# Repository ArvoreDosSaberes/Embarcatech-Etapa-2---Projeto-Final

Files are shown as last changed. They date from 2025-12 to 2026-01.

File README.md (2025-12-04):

# Rack Inteligente Workspace






[]()
[]()








MVP para o projeto Embarcatech, o Rack Inteligente é um sistema IoT para Racks de Redes de Computadores. Ele monitora o Rack quanto a questões ambientais (temperatura, umidade) e segurança (porta, inclinação), alertando uma central através do protocolo MQTT na borda, que recebe subscrição de um servidor na nuvem que centraliza a gestão dos racks.

---

## 📋 Índice

1. [Pré-requisitos](#-pré-requisitos)
2. [Clonagem do Repositório](#-clonagem-do-repositório)
3. [Configuração do Ambiente Python](#-configuração-do-ambiente-python)
4. [Instalação do Granite TSF](#-instalação-do-granite-tsf)
5. [Configuração de Variáveis de Ambiente](#%EF%B8%8F-configuração-de-variáveis-de-ambiente)
6. [Compilação do Firmware](#-compilação-do-firmware)
7. [Gravação no RP2040](#-gravação-no-rp2040)
8. [Configuração no VSCode/Windsurf](#-configuração-no-vscodewindsurf)
9. [Softwares Relevantes](#-softwares-relevantes)

---

## 🔧 Pré-requisitos

Antes de iniciar, certifique-se de ter instalado:

### Sistema Operacional
- **Linux** (Ubuntu 20.04+ recomendado) ou **Windows 10/11**
- **macOS** 10.15+ (Catalina ou superior)

### Ferramentas de Desenvolvimento

| Ferramenta | Versão Mínima | Descrição |
|---|---|---|
| **Git** | 2.30+ | Controle de versão |
| **Python** | 3.10+ | Runtime para dashboard e serviços |
| **CMake** | 3.16+ | Sistema de build para firmware |
| **GCC ARM** | 10.3+ | Compilador para RP2040 |
| **Pico SDK** | 2.1.1 | SDK da Raspberry Pi Pico |
| **picotool** | 2.1.1 | Ferramenta para flash do RP2040 |

### Instalação das Ferramentas no Linux (Ubuntu/Debian)

```bash
# Atualizar sistema
sudo apt update && sudo apt upgrade -y

# Instalar dependências básicas
sudo apt install -y git cmake build-essential python3 python3-pip python3-venv

# Instalar ARM toolchain
sudo apt install -y gcc-arm-none-eabi libnewlib-arm-none-eabi

# Instalar dependências do PyQt5 (para o dashboard)
sudo apt install -y libxcb-xinerama0 libxkbcommon-x11-0 libxcb-icccm4 \
    libxcb-image0 libxcb-keysyms1 libxcb-randr0 libxcb-render-util0 \
    libxcb-shape0 qtbase5-dev
```

---

## 📥 Clonagem do Repositório

O repositório utiliza **submódulos Git** para organizar os componentes. É necessário clonar recursivamente.

### Opção 1: Clonagem via SSH (recomendado)

```bash
git clone --recursive git@github.com:ArvoreDosSaberes/Embarcatech-Etapa-2---Projeto-Final.git
cd Embarcatech-Etapa-2---Projeto-Final
```

### Opção 2: Clonagem via HTTPS

```bash
git clone --recursive https://github.com/ArvoreDosSaberes/Embarcatech-Etapa-2---Projeto-Final.git
cd Embarcatech-Etapa-2---Projeto-Final
```

### Caso já tenha clonado sem `--recursive`

```bash
cd Embarcatech-Etapa-2---Projeto-Final
git submodule update --init --recursive
```

### Verificando os submódulos

Após a clonagem, verifique se todos os submódulos estão presentes:

```bash
git submodule status
```

Você deve ver os seguintes submódulos:
- `dashboard/` - Interface de monitoramento (PyQt5)
- `firmware/` - Firmware para RP2040/Pico W
- `FreeRTOS-Kernel/` - Kernel FreeRTOS
- `Keyboard-Menu---workspace/` - Biblioteca de menu para teclado matricial

---

## 🐍 Configuração do Ambiente Python

O projeto utiliza um ambiente virtual Python único na raiz do workspace.

### 1. Criar o ambiente virtual

```bash
# Na raiz do projeto
python3 -m venv venv
```

### 2. Ativar o ambiente virtual

**Linux/macOS:**
```bash
source venv/bin/activate
```

**Windows (PowerShell):**
```powershell
.\venv\Scripts\Activate.ps1
```

**Windows (CMD):**
```cmd
venv\Scripts\activate.bat
```

### 3. Atualizar pip e instalar dependências base

```bash
pip install --upgrade pip setuptools wheel

# Instalar dependências do workspace principal
pip install -r requirements.txt
```

### 4. Instalar dependências do Dashboard

```bash
pip install -r dashboard/requirements.txt
```

---

## 🔮 Instalação do Granite TSF

O **Granite Time Series Forecasting** é o serviço de previsão de séries temporais que utiliza o modelo IBM Granite TTM-R2.

### 1. Instalar dependências do Granite TSF

```bash
# Com o venv ativado
pip install -r Granite-Time-Series-Forecasting-Python/requirements.txt
```

### 2. Instalar o modelo IBM Granite TTM-R2

Execute o script de instalação fornecido:

```bash
cd Granite-Time-Series-Forecasting-Python
bash install_granite.sh
cd ..
```

O script irá:
- Instalar PyTorch (versão CPU por padrão)
- Instalar transformers
- Baixar e instalar o modelo Granite do repositório IBM

### 3. Verificar a instalação

```bash
python -c "
try:
    from tsfm_public import TimeSeriesForecastingPipeline, TinyTimeMixerForPrediction
    print('✅ Granite TTM-R2 disponível!')
except ImportError:
    print('⚠️  Granite TTM-R2 não disponível - usando modelo alternativo (SARIMA)')
"
```

> **Nota**: Caso o Granite não esteja disponível, o sistema utilizará automaticamente o modelo SARIMA (statsmodels) como fallback.

### 4. Configurar o serviço Granite TSF

```bash
cd Granite-Time-Series-Forecasting-Python
cp .env.example .env
# Edite o arquivo .env conforme necessário
cd ..
```

---

## ⚙️ Configuração de Variáveis de Ambiente

### 1. Criar arquivo `.env` a partir do exemplo

```bash
cp env.example .env
```

### 2. Editar o arquivo `.env`

Abra o arquivo `.env` e configure as seguintes variáveis:

#### Configuração WiFi (Firmware)
```ini
WIFI_SSID="SuaRedeWiFi"
WIFI_PASSWORD="SuaSenhaWiFi"
```

#### Configuração MQTT
```ini
MQTT_SERVER=mqtt.seu-servidor.com
MQTT_PORT=1883
MQTT_USERNAME=usuario
MQTT_PASSWORD=senha_segura
MQTT_KEEPALIVE=60
MQTT_BASE_TOPIC=racks/
MQTT_CLIENT_ID="Rack Inteligente"
MQTT_RACK_NUMBER="PICOW001"
```

#### Configuração de IA Generativa (opcional)
```ini
GENAI_API_KEY=sua-chave-api-aqui
GENAI_URL=generativa.rapport.tec.br/api/v1
GENAI_MODEL=granite4:3b
```

### 3. Criar arquivo `env.cmake` para o firmware

O firmware também requer um arquivo `env.cmake` na raiz do projeto:

```bash
# Criar arquivo env.cmake
cat > env.cmake << 'EOF'
# ===========================================
# Configurações do Firmware - env.cmake
# ===========================================

set(ENV{WIFI_SSID} "SuaRedeWiFi")
set(ENV{WIFI_PASSWORD} "SuaSenhaWiFi")

set(ENV{MQTT_BROKER} "mqtt.seu-servidor.com")
set(ENV{MQTT_PORT} "1883")
set(ENV{MQTT_USERNAME} "usuario")
set(ENV{MQTT_PASSWORD} "senha_segura")
set(ENV{MQTT_CLIENT_ID} "Rack Inteligente")
set(ENV{MQTT_BASE_TOPIC} "racks")
set(ENV{MQTT_RACK_NUMBER} "PICOW001")

# Nível de log: -1=OFF, 0=CRITICAL, 1=ERROR, 2=WARNING, 3=INFO
set(ENV{LOG_LEVEL} "3")
EOF
```

> **⚠️ Importante**: Os arquivos `.env` e `env.cmake` contêm credenciais sensíveis e estão no `.gitignore`.

---

## 🔨 Compilação do Firmware

O firmware é desenvolvido para **Raspberry Pi Pico W** utilizando o **Pico SDK** e **FreeRTOS**.

### Pré-requisitos do Pico SDK

#### Opção 1: Instalação via Extensão VSCode/Windsurf (Recomendado)

A extensão **Raspberry Pi Pico** instala automaticamente o SDK. Veja a seção [Configuração no VSCode/Windsurf](#-configuração-no-vscodewindsurf).

#### Opção 2: Instalação Manual

```bash
# Definir diretório do SDK
export PICO_SDK_PATH=$HOME/pico-sdk

# Clonar o SDK
git clone -b 2.1.1 https://github.com/raspberrypi/pico-sdk.git $PICO_SDK_PATH
cd $PICO_SDK_PATH
git submodule update --init

# Voltar ao projeto
cd -
```

### Compilação via Linha de Comando

```bash
# Criar diretório de build
cd firmware
mkdir -p build
cd build

# Configurar o projeto com CMake
cmake .. -DPICO_BOARD=pico_w

# Compilar
make -j$(nproc)

# Voltar à raiz
cd ../..
```

Após a compilação, o arquivo `rack_inteligente.uf2` estará em `firmware/build/`.

### Compilação via VSCode/Windsurf

1. Abra a pasta `firmware/` como workspace
2. Pressione `Ctrl+Shift+P` → **CMake: Configure**
3. Selecione o kit **Pico ARM GCC**
4. Pressione `F7` ou **CMake: Build** para compilar

---

## 📤 Gravação no RP2040

### Método 1: BOOTSEL (Modo UF2)

1. **Desconecte** a Pico W do USB
2. **Pressione e segure** o botão **BOOTSEL**
3. **Conecte** o cabo USB mantendo o botão pressionado
4. **Solte** o botão - a Pico aparecerá como dispositivo de armazenamento USB
5. **Copie** o arquivo `firmware/build/rack_inteligente.uf2` para o dispositivo

```bash
# No Linux, o dispositivo geralmente monta em /media/$USER/RPI-RP2
cp firmware/build/rack_inteligente.uf2 /media/$USER/RPI-RP2/
```

### Método 2: picotool (via SWD ou USB)

```bash
# Instalar picotool (se não instalado)
sudo apt install picotool

# Gravar firmware
picotool load firmware/build/rack_inteligente.uf2 -f

# Reiniciar a placa
picotool reboot
```

### Método 3: Via VSCode/Windsurf

1. Conecte a Pico W em modo BOOTSEL
2. Pressione `Ctrl+Shift+P` → **Raspberry Pi Pico: Flash**
3. Selecione o arquivo `.uf2` gerado

---

## 💻 Configuração no VSCode/Windsurf

### Extensões Essenciais

| Extensão | ID | Descrição |
|---|-----|---|
| **Raspberry Pi Pico** | `raspberry-pi.raspberry-pi-pico` | Suporte completo ao Pico SDK |
| **C/C++** | `ms-vscode.cpptools` | IntelliSense e debugging C/C++ |
| **CMake Tools** | `ms-vscode.cmake-tools` | Integração com CMake |
| **Python** | `ms-python.python` | Suporte Python |
| **Pylance** | `ms-python.vscode-pylance` | IntelliSense avançado para Python |

### Extensões Recomendadas

| Extensão | ID | Descrição |
|---|-----|---|
| **Cortex-Debug** | `marus25.cortex-debug` | Debug para ARM Cortex-M |
| **Serial Monitor** | `ms-vscode.vscode-serial-monitor` | Monitor serial integrado |
| **GitLens** | `eamodio.gitlens` | Melhorias para Git |
| **Error Lens** | `usernamehw.errorlens` | Exibe erros inline |
| **Todo Tree** | `Gruntfuggly.todo-tree` | Gerenciador de TODOs |

### Instalação das Extensões (Linha de Comando)

```bash
# Extensões essenciais
code --install-extension raspberry-pi.raspberry-pi-pico
code --install-extension ms-vscode.cpptools
code --install-extension ms-vscode.cmake-tools
code --install-extension ms-python.python
code --install-extension ms-python.vscode-pylance

# Extensões recomendadas
code --install-extension marus25.cortex-debug
code --install-extension ms-vscode.vscode-serial-monitor
code --install-extension eamodio.gitlens
```

### Configuração do Workspace

Ao abrir o projeto, o VSCode/Windsurf solicitará:

1. **Selecionar Kit CMake**: Escolha **Pico ARM GCC**
2. **Configurar Python Interpreter**: Selecione `./venv/bin/python`

### Arquivo `settings.json` Recomendado

Crie ou edite `.vscode/settings.json`:

```json
{
    "cmake.configureOnOpen": true,
    "cmake.buildDirectory": "${workspaceFolder}/firmware/build",
    "python.defaultInterpreterPath": "${workspaceFolder}/venv/bin/python",
    "python.terminal.activateEnvironment": true,
    "files.associations": {
        "*.h": "c",
        "*.hpp": "cpp"
    },
    "C_Cpp.default.configurationProvider": "ms-vscode.cmake-tools"
}
```

---

## 🛠️ Softwares Relevantes

| Software | Descrição | Link |
|---|---|---|
| **MQTTX** | Cliente MQTT GUI para testes | [mqttx.app](https://mqttx.app/) |
| **PuTTY** | Terminal serial (Windows) | [putty.org](https://www.putty.org/) |
| **minicom** | Terminal serial (Linux) | `sudo apt install minicom` |
| **Wireshark** | Análise de pacotes de rede | [wireshark.org](https://www.wireshark.org/) |

### Monitoramento Serial

```bash
# Linux (minicom)
minicom -D /dev/ttyACM0 -b 115200

# Linux (screen)
screen /dev/ttyACM0 115200
```

---

## 📚 Estrutura do Projeto

```
Embarcatech-Etapa-2---Projeto-Final/
├── dashboard/                      # Interface PyQt5 (submódulo)
│   ├── app.py                      # Aplicação principal
│   ├── services/                   # Serviços de negócio
│   └── requirements.txt
├── firmware/                       # Firmware RP2040 (submódulo)
│   ├── CMakeLists.txt              # Build system
│   ├── rack_inteligente.cpp        # Código principal
│   ├── tasks/                      # Tarefas FreeRTOS
│   └── FreeRTOS-Kernel/            # Kernel FreeRTOS
├── Granite-Time-Series-Forecasting-Python/  # Serviço de previsão
│   ├── app.py                      # Servidor Flask
│   ├── src/services/               # Serviços de ML
│   └── install_granite.sh          # Script de instalação
├── docs/                           # Documentação do projeto
├── simulador/                      # Simulador MQTT
├── .env                            # Variáveis de ambiente (gitignored)
├── env.cmake                       # Variáveis para CMake (gitignored)
├── env.example                     # Template de configuração
├── requirements.txt                # Dependências Python (raiz)
└── README.md                       # Este arquivo
```

---

## 🚀 Execução do Sistema Completo

### 1. Iniciar o Serviço Granite TSF (opcional)

```bash
source venv/bin/activate
cd Granite-Time-Series-Forecasting-Python
python app.py
# Acesse: http://localhost:5000
```

### 2. Iniciar o Dashboard

```bash
source venv/bin/activate
cd dashboard
python app.py
```

### 3. Gravar e executar o Firmware

Após gravar o firmware na Pico W, ela iniciará automaticamente e se conectará ao broker MQTT.

### 4. Simulador MQTT (para testes sem hardware)

```bash
source venv/bin/activate
cd simulador
python mqtt_simulator.py
```

---

## 🤝 Contribuindo

1. Fork o projeto
2. Crie uma branch para sua feature (`git checkout -b feature/NovaFuncionalidade`)
3. Commit suas mudanças (`git commit -m 'Adiciona nova funcionalidade'`)
4. Push para a branch (`git push origin feature/NovaFuncionalidade`)
5. Abra um Pull Request

---

## 📄 Licença

Este projeto está licenciado sob a licença **CC BY 4.0**. Veja o arquivo [LICENSE](LICENSE) para detalhes.

---

## 📞 Suporte

Para problemas ou dúvidas, abra uma [issue](https://github.com/ArvoreDosSaberes/Embarcatech-Etapa-2---Projeto-Final/issues) no repositório.

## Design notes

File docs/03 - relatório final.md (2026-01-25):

---
title: "Rack Inteligente: Sistema AIoT de Gerenciamento e Segurança Ambiental para Racks em Infraestruturas de Pequeno Porte"
authors:
  - "Carlos Delfino Carvalho Pinheiro"
summary: "Solução AIoT focada em monitorar ambiente e controlar o acesso de racks compactos, integrando sensores, atuadores e IA generativa. - Relatório Final"
language: "pt-BR"
date: "2025-11-06"
tags:
  - "EmbarcaTech"
  - "AIoT"
  - "IoT"
  - "Segurança"
  - "Monitoramento"
  - "Infraestrutura"
  - "Rack Inteligente"
  - "MQTT"
  - "Controle Ambiental"
  - "Relatório Final"

abnt:
  institution: "Instituto Federal de Educação, Ciência e Tecnologia"
  campus: "Campus Fortaleza"
  course: "Embarcatech - Etapa 2 - Residência"
  discipline: "Projeto Integrador"
  nature: "Trabalho de Conclusão de Curso"
  natureDetails: "apresentado ao Instituto Federal como requisito parcial do projeto Embarcatech - Etapa 2 - Residência."
  studentId: "202510110980368"
  city: "Fortaleza"
  state: "CE"
  year: "2026"
---
# Rack Inteligente AIoT

## Sistema de gerenciamento e segurança ambiental para racks em infraestruturas de pequeno porte, com apoio de IA generativa

## 1. Introdução

O **Rack Inteligente AIoT** foi desenvolvido para atender a uma necessidade comum em operações de TI de pequeno e médio porte: o gerenciamento de **múltiplos racks compactos**, frequentemente instalados em ambientes com pouca infraestrutura (salas pequenas, armários técnicos e pontos remotos). Nesse contexto, é comum haver:

- **Risco ambiental**, como temperatura elevada e umidade fora do recomendado.
- **Risco físico**, como acesso indevido ao rack.
- **Dificuldade de gestão remota**, especialmente quando há vários pontos distribuídos.

Com o apoio de IA, o sistema passa a operar de forma contínua (24x7), registrando histórico e apoiando decisões de forma cada vez mais consistente a partir dos dados coletados.

## 2. Objetivos

O objetivo do projeto é reduzir falhas e indisponibilidades em infraestruturas de rede de pequeno porte por meio de:

- Monitoramento ambiental (temperatura e umidade).
- Segurança física (estado da porta e eventos associados).
- Alertas e comandos remotos, utilizando MQTT.

Como resultado esperado, busca-se diminuir a incidência de ocorrências relacionadas ao ambiente e, consequentemente, reduzir chamados e custos de manutenção corretiva.

## 3. Justificativa

Durante **35 anos de experiência em suporte e implantação de redes de computadores**, foi observada uma carência de soluções voltadas a **pequenos racks** que unam segurança física e gestão ambiental em um mesmo sistema. Em geral, as tecnologias existentes são direcionadas a **data centers de grande porte**, deixando lacunas no mercado de **infraestruturas menores**, que muitas vezes operam em condições ambientais inadequadas ou vulneráveis a acessos indevidos. Além disso, é comum que as soluções disponíveis tenham custo incompatível com o porte do ambiente.

O **Rack Inteligente AIoT** surge como resposta a essa necessidade, oferecendo um sistema **autônomo, modular e acessível**, capaz de:

- Monitorar e controlar o ambiente interno do rack (temperatura e umidade).
- Gerenciar o acesso físico com autenticação e travamento automático.
- Enviar alertas e relatórios via rede para administração remota.

Essa abordagem é especialmente útil para organizações que precisam garantir **continuidade operacional** e **segurança de dados** com orçamento limitado e infraestrutura simplificada.

## 4. Problemática

Complementando a justificativa, a demanda por monitoramento de racks de pequeno porte é crescente. Atualmente, praticamente toda empresa depende de uma infraestrutura de rede (mesmo que enxuta), frequentemente instalada em pequenos racks. Sem monitoramento, o risco de falha aumenta por fatores como:

- Temperatura elevada e ventilação insuficiente.
- Umidade em níveis inadequados.
- Acesso indevido ou não rastreado.

O projeto busca reduzir esses riscos ao integrar sensores, atuadores e telemetria, combinando automação local com gestão remota.

## 5. Arquitetura do sistema (hardware + firmware + AIoT)

Diagrama representativo do projeto:

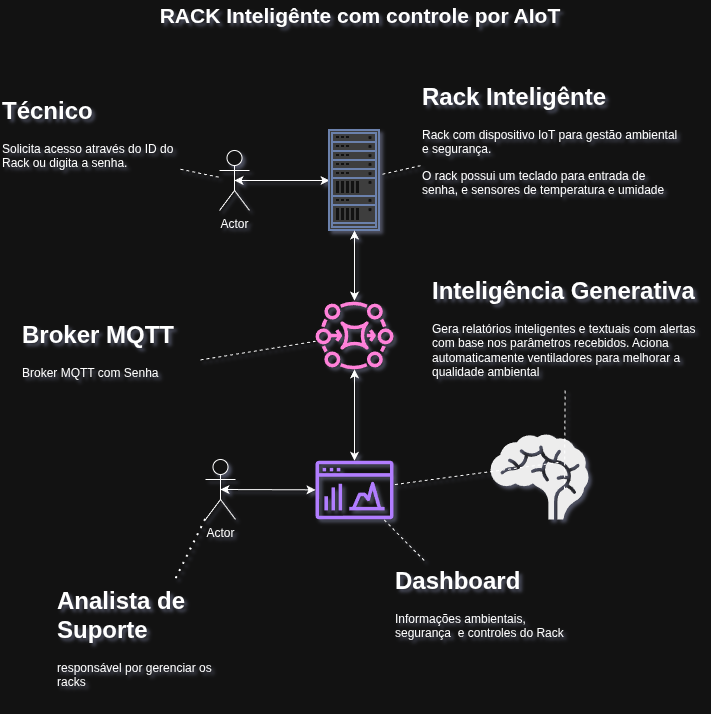
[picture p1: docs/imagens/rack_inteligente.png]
Diagrama Representativo do Projeto


Diagrama de blocos do projeto:

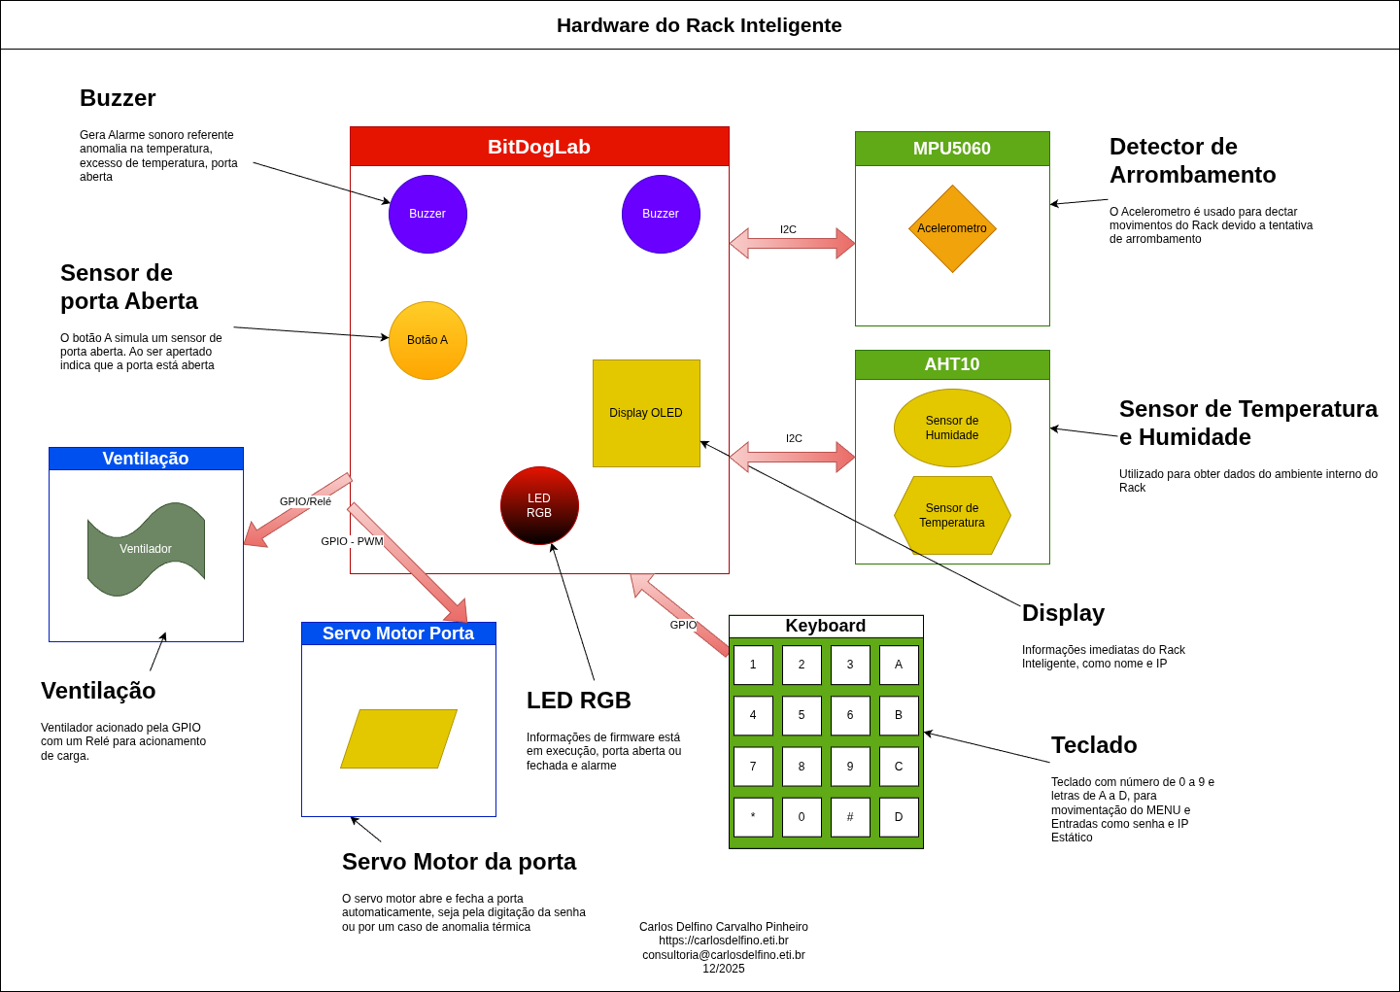
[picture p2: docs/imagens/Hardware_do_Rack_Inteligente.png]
Diagrama de Blocos do Projeto


## 6. Desenvolvimento do sistema

### 6.1. Estratégia de concorrência: uma task por responsabilidade

Foi adotada a estratégia de **uma task por responsabilidade**. Essa decisão facilita:

- **Diagnóstico** (isolamento de falhas e gargalos).
- **Manutenção** (alterações localizadas).
- **Evolução** (troca de drivers e protocolos com menor impacto).

Um exemplo direto é a publicação via MQTT: existem tasks dedicadas por parâmetro monitorado. Isso permite, se necessário, substituir apenas a camada de transporte (por exemplo, trocar MQTT por outro protocolo) **sem interferir** na coleta, validação e cálculo dos parâmetros ambientais.

### 6.2. Entrada do teclado e controle do menu

As tasks relacionadas ao teclado utilizam **notificações (task notify)** com **flags** para representar as teclas pressionadas. Há duas responsabilidades principais:

- **Task de leitura de GPIOs** do teclado.
- **Task de processamento** das teclas e controle do menu.

O menu é estruturado como uma **máquina de estados**. Embora não esteja totalmente finalizado, ele demonstra uma abordagem orientada a eventos adequada para sistemas embarcados.

Apesar de o algoritmo de leitura das teclas estar funcional, ainda não foram implementadas as rotinas completas de **troca de senha** e entrada do **código do rack** via menu. No estágio atual, esses parâmetros precisam ser definidos no momento da gravação do firmware.

### 6.3. Processamento de comandos: filas (queues) e ACK

Para comandos recebidos (por exemplo, **abrir porta**, **acionar alarme** e **acionar ventilação**), foi adotada a abordagem com **queues**. Com isso:

- Os comandos são enfileirados em ordem **FIFO**.
- A execução ocorre de forma previsível, reduzindo risco de concorrência.
- Ao final, é gerado um **ACK**, confirmando que o comando foi recebido e processado.

### 6.4. Sensores e comunicação com MQTT

Para sensores (movimento, temperatura e umidade), o firmware notifica componentes responsáveis por publicar telemetria. A escolha por múltiplas classes/módulos (mesmo quando seria possível centralizar a lógica) foi intencional para reforçar:

- Modularização.
- Separação de responsabilidades.
- Organização do sistema em um formato mais próximo de um produto evolutivo.

No caso do sensor de temperatura e umidade, foi adotado o padrão de projeto **Gatekeeper (Guardião)**: uma tarefa é responsável por se comunicar com o dispositivo e obter os dados, repassando cada medição para a tarefa responsável por tratá-la e publicá-la.

No caso do barramento I2C, foi utilizado o padrão de projeto **Proxy**, permitindo centralizar e gerenciar o acesso ao barramento em uma única lógica de controle, garantindo **atomicidade** na comunicação: iniciar a transação (obter o barramento), comunicar e finalizar, liberando o barramento para outras threads.

## 7. Hardware

O hardware foi desenvolvido conforme o pré-projeto. O diagrama de blocos abaixo resume a estrutura e o funcionamento:

Esquema de Blocos do Hardware

A imagem a seguir mostra o protótipo montado. Nela:

- Adaptador e **servo motor** (acionamento da porta).
- Placa de distribuição **I2C**.
- Sensor de movimento (**MPU6050**).
- Sensor de temperatura e umidade (**AHT10**).
- Teclado.
- A **BitDogLab** ao centro, já integrando LEDs RGB e display OLED.

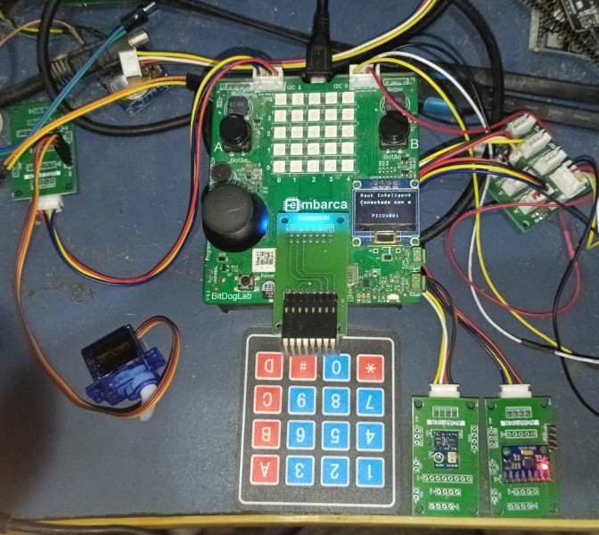
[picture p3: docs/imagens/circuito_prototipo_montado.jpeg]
Circuito do Rack


### 7.1. Esquemático das conexões

No esquemático, o barramento I2C usado pelo sensor de movimento (MPU6050) e pelo sensor de temperatura e umidade (AHT10) está conectado aos pinos GPIO0 e GPIO1 (canal I2C0), externalizado pelo conector indicado.

O PWM para controle do servo motor está no pino GPIO2, externalizado pelo conector identificado como I2C1 (neste caso, apenas como conector físico, sem relação com I2C).

O display OLED utiliza GPIO14 e GPIO15 no canal I2C1, não conflitando com o I2C0.

Os LEDs RGB estão conectados nos pinos GPIO12, GPIO13 e GPIO15.

Os buzzers estão conectados aos pinos GPIO10 e GPIO27, controlados por PWM.

Na BitDogLab, os botões são utilizados como entradas digitais:

- **Botão A**: GPIO5 (entrada com pull-up, lógica invertida).
- **Botão B**: GPIO6 (entrada com pull-up, lógica invertida).

O ventilador foi representado no protótipo pelo LED verde. O LED azul pisca indicando funcionamento do firmware: durante o boot rapidamente e, em operação normal, alterna o estado a cada 1 segundo.

O estado de porta aberta/fechada é simulado pelo **botão A**: quando pressionado, considera-se porta aberta; quando solto, porta fechada.

O **botão B** desativa o alarme até a próxima anomalia detectada.

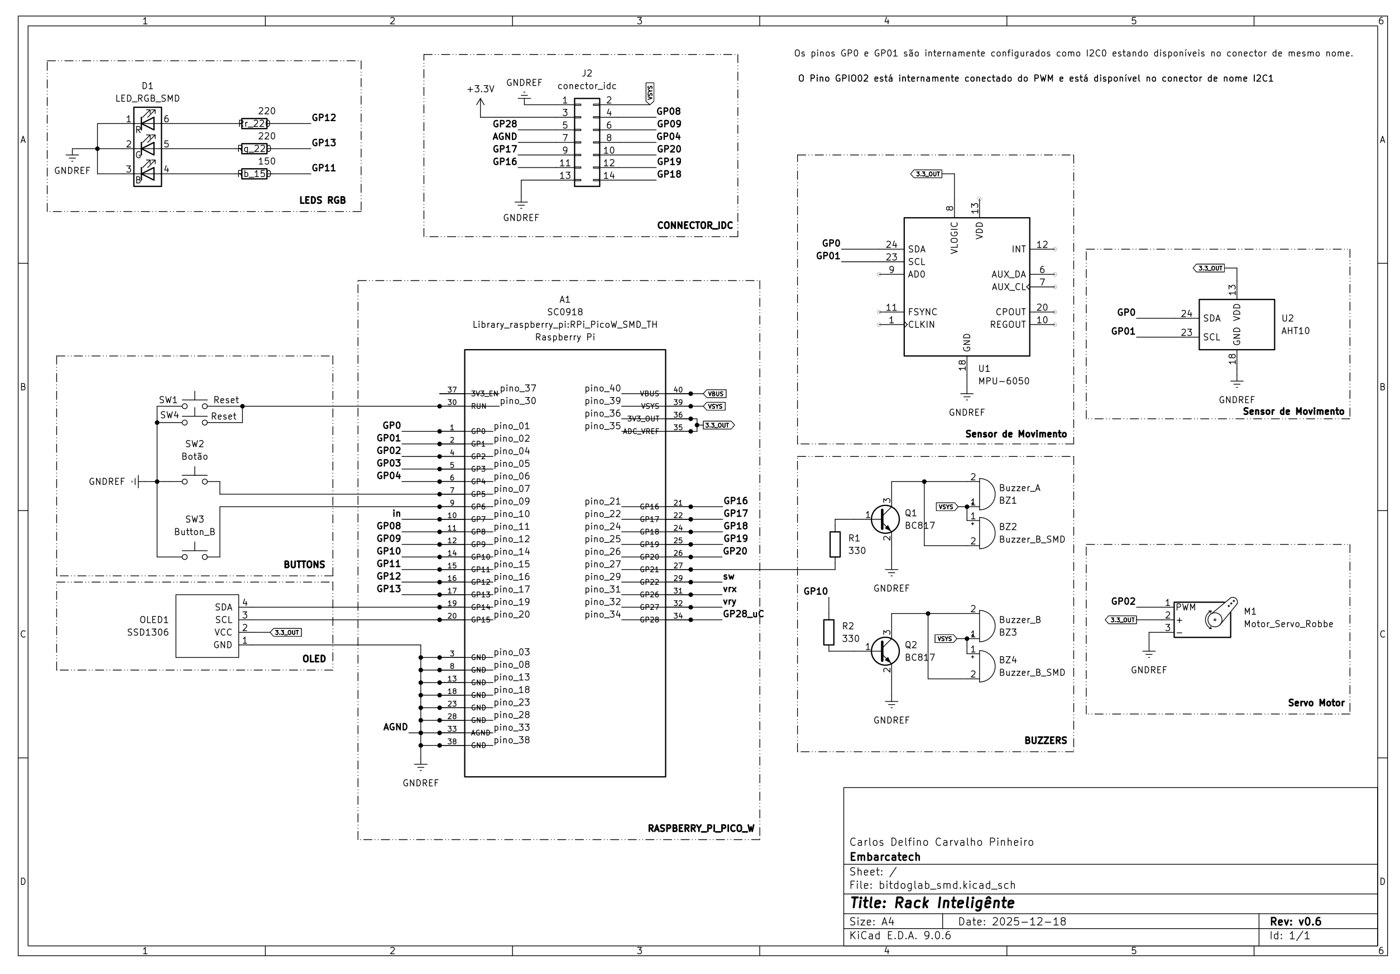
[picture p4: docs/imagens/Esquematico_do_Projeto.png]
Esquemático das Conexões


## 8. Camada IoT (MQTT)

Foi adotado o protocolo **MQTT** para comunicação entre o firmware e o dashboard por ser leve e adequado a telemetria e comandos em tempo real.

O broker foi implantado em um **servidor VPS**, com:

- Regras de **firewall** para reduzir a superfície de ataque.
- Autenticação por **usuário e senha**.

Essa base atende às necessidades de segurança operacional no cenário do projeto.

## 9. AIoT (IA aplicada ao sistema)

### 9.1. Integração com LLM via OpenWebUI/Ollama

Foi adotado o **OpenWebUI** como interface de acoplamento entre o dashboard e a engine de LLMs (via **Ollama**). Essa estratégia viabiliza requisições em formato compatível com a biblioteca OpenAI, facilitando a troca de engine de IA generativa sem mudanças grandes no código (em geral, basta ajustar URL e chave de API).

### 9.2. Tool Calling para decisão e atuação

Foram usados recursos de **Tool Calling** para apoiar decisões relacionadas a:

- Temperaturas em níveis críticos.
- Acionamento de ventilação.
- Disparo de alarmes.

O modelo utilizado como orquestrador de ferramentas é o **Granite 4** (3 bilhões de parâmetros).

### 9.3. Previsão de temperatura e umidade (TTM)

Foi adicionado um mecanismo de previsão com o **Granite TTM (Tiny Time Series Model)**, utilizando dados históricos para estimar valores futuros de temperatura e umidade. Isso auxilia na antecipação de situações de risco (por exemplo, tendência de aquecimento contínuo).

## 10. Treinamento e parametrização da IA

- O prompt principal para o comportamento da IA generativa está na pasta `prompts/`.
- As variáveis de execução do dashboard e parâmetros de treinamento/uso do Granite TTM são configuradas via arquivo `.env` na raiz do projeto.

### 10.1. Broker MQTT

O broker MQTT foi implementado com o **Mosquitto** em um servidor VPS, no endereço `mqtt://mqtt.rapport.tec.br`. Por questões de segurança, foi adotado controle de acesso por usuário e senha.

### 10.2. Dashboard (Python)

O dashboard foi desenvolvido em **Python** para facilitar a integração com a LLM e com o TTM (modelos Granite da IBM) e acelerar os ciclos de teste.

A seguir, a janela principal:

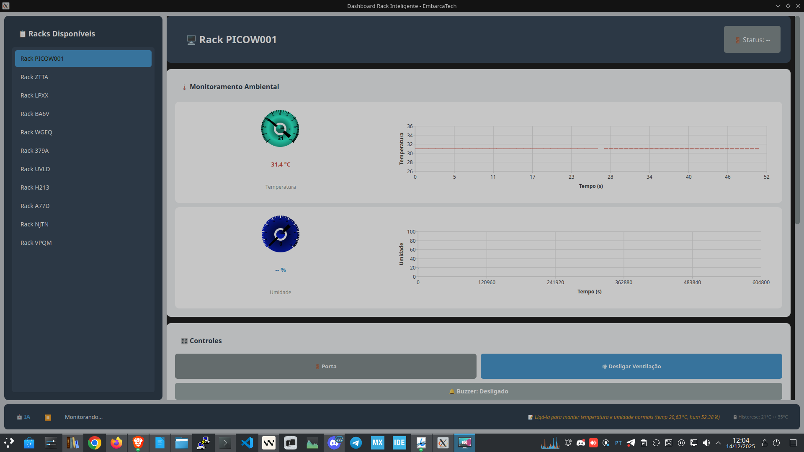
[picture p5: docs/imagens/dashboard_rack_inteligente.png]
Dashboard Principal


Componentes principais da interface:

- **Lista de racks (lado esquerdo)**: alimentada dinamicamente conforme as telemetrias são publicadas no MQTT. O nome do rack pisca quando algum parâmetro é atualizado.
- **Painel de telemetria (lado direito)**: temperatura e umidade. O traço contínuo representa o histórico coletado; o traço descontínuo representa a previsão baseada no histórico.
- **Controles manuais**: botões para abrir porta e acionar ventilação, além de sinalização do estado do alarme.

Ao rolar o conteúdo, é exibido o mapa de localização do rack, com dados obtidos pelo parâmetro de GPS enviado pelo Rack Inteligente:

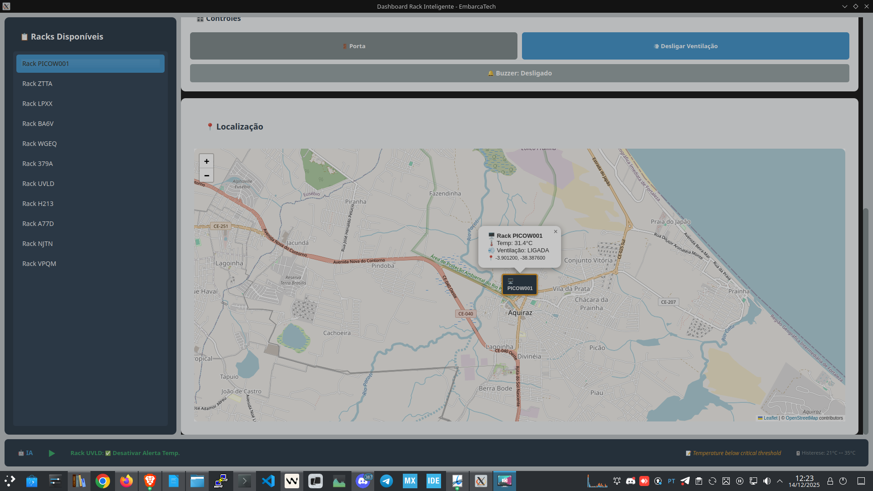
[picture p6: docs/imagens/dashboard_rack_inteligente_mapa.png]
Dashboard Mapa


No rodapé, são exibidas as **reflexões e decisões** produzidas pela IA generativa a partir dos parâmetros de telemetria.

## 11. Vídeo de apresentação do projeto

[https://youtu.be/8Clld03a714](https://youtu.be/8Clld03a714 "Vídeo de apresentação do projeto")

## 12. Conclusão

O projeto permanece em evolução. Ainda há itens em desenvolvimento, como a finalização do menu e a inclusão de rotinas completas para entrada de senha e código do rack via interface local. Mesmo com limitações de bancada e com a necessidade de validações adicionais em alguns componentes, foi possível testar o firmware e comprovar o funcionamento do sistema integrado.

O uso de séries temporais para previsão tende a ser mais efetivo após um período maior de coleta contínua. Ainda assim, a implementação e experimentação do TTM representaram um aprendizado relevante e abrem espaço para aplicações futuras.

## 13. Referências

- https://arxiv.org/pdf/2401.03955
- https://huggingface.co/ibm-granite/granite-timeseries-ttm-r2
- https://research.ibm.com/publications/tiny-time-mixers-ttms-fast-pre-trained-models-for-enhanced-zerofew-shot-forecasting-of-multivariate-time-series--1
- https://towardsdatascience.com/tiny-time-mixers-ttm-a-powerful-zero-shot-forecasting-model-by-ibm-576b0e0af583/
- https://groq.com/blog/introducing-llama-3-groq-tool-use-models
- https://huggingface.co/Groq/Llama-3-Groq-8B-Tool-Use

## 14. Apêndices

Link para o projeto no GitHub (workspace com submódulos):

* [https://github.com/ArvoreDosSaberes/Embarcatech-Etapa-2---Projeto-Final](https://github.com/ArvoreDosSaberes/Embarcatech-Etapa-2---Projeto-Final "Link direto para o repositório")
* [https://github.com/ArvoreDosSaberes/Embarcatech-Etapa-2---Projeto-Final-dashboard](https://github.com/ArvoreDosSaberes/Embarcatech-Etapa-2---Projeto-Final-dashboard)
* [https://github.com/ArvoreDosSaberes/Embarcatech-Etapa-2---Projeto-Final-firmware](https://github.com/ArvoreDosSaberes/Embarcatech-Etapa-2---Projeto-Final-firmware)

Para clonar o repositório:

O repositório principal tem os demais repositórios como submódulo, portanto use o comando:

```
git clone --recurse-submodules https://github.com/ArvoreDosSaberes/Embarcatech-Etapa-2---Projeto-Final.git
```

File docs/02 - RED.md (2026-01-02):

---
title: "Rack Inteligente: Sistema AIoT de Gerenciamento e Segurança Ambiental para Racks em Infraestruturas de Pequeno Porte"
authors:
  - "Carlos Delfino Carvalho Pinheiro"
summary: "Solução AIoT focada em monitorar ambiente e controlar o acesso de racks compactos, integrando sensores, atuadores e IA generativa. - Relatório de Evidência de Desenvolvimento"
language: "pt-BR"
date: "2025-11-06"
tags:
  - "EmbarcaTech"
  - "AIoT"
  - "IoT"
  - "Segurança"
  - "Monitoramento"
  - "Infraestrutura"
  - "Rack Inteligente"
  - "MQTT"
  - "Controle Ambiental"

abnt:
  institution: "Instituto Federal de Educação, Ciência e Tecnologia"
  campus: "Campus Fortaleza"
  course: "Embarcatech - Etapa 2 - Residência"
  discipline: "Projeto Integrador"
  nature: "Trabalho de Conclusão de Curso"
  natureDetails: "apresentado ao Instituto Federal como requisito parcial do projeto Embarcatech - Etapa 2 - Residência."
  studentId: "202510110980368"
  city: "Fortaleza"
  state: "CE"
  year: "2025"
---
# Relatório de Evidência de Desenvolvimento (RED)

## 1. Visão geral do projeto

Este projeto implementa um **Rack Inteligente** voltado para **monitoramento ambiental** e **segurança física** em infraestruturas de pequeno porte. A solução integra:

- **Firmware embarcado** (C/C++ com FreeRTOS), responsável por leitura de sensores, atuação e comunicação.
- **Camada IoT** via **MQTT**, para transporte de telemetria e comandos.
- **Dashboard** (Python), para visualização, controle manual e integração com recursos de IA.
- **AIoT**, com uso de **LLM** e **modelos de séries temporais** para apoiar decisões e previsões.

A ideia principal é separar bem as responsabilidades para facilitar manutenção, testes e evolução do sistema.

## 2. Estado atual (marcos e estabilidade)

O projeto está em **estágio avançado**, com os marcos principais **praticamente entregues**. Nesta etapa eu estou focado em:

- **Revisão geral do código** (refatorações pontuais e padronização).
- **Correção de bugs menores**.
- **Reatividade do sistema**, onde testo resposta a comandos e simulação de múltiplos Racks.
- **Testes de resiliência e estabilidade** (execução contínua por longos períodos).

Evidências observadas até aqui:

- **Firmware**: executando por dias com boa estabilidade.
- **Dashboard**: responde bem ao monitoramento simultâneo de **dezenas a centenas de racks**.
- **Broker MQTT (Mosquitto)** em VPS: serviço estável há **mais de 3 meses**, sem incidentes relevantes.

## 3. Arquitetura do firmware (C/C++ com FreeRTOS)

### 3.1. Estratégia de concorrência: uma task por responsabilidade

Foi adotada a tática de **uma task por responsabilidade**. Essa decisão melhora:

- **Diagnóstico** (fica mais fácil isolar gargalos e falhas).
- **Manutenção** (alterações ficam localizadas).
- **Evolução** (troca de protocolos ou drivers sem reescrever o sistema inteiro).

Um exemplo importante: para publicação de dados via MQTT, há tasks dedicadas por parâmetro monitorado. Isso permite, se necessário, substituir apenas a parte de transporte (por exemplo, trocar MQTT por outro protocolo) **sem interferir** na coleta e no cálculo dos parâmetros ambientais.

### 3.2. Entrada do teclado e controle do menu

As tasks relacionadas ao teclado utilizam **notificações (task notify)** com **flags** para representar as teclas pressionadas. Há duas responsabilidades principais:

- **Task de leitura de GPIOs** do teclado.
- **Task de processamento** das teclas e controle do menu.

O menu é estruturado como uma **máquina de estados**. Embora ainda não esteja totalmente finalizado, ele demonstra uma abordagem orientada a eventos, típica de sistemas embarcados robustos.

### 3.3. Processamento de comandos: filas (queues) e ACK

Para comandos recebidos (por exemplo, **abrir porta**, **acionar alarme** e **acionar ventilação**), foi adotada a abordagem com **queues**. Com isso:

- Os comandos são enfileirados em ordem **FIFO**.
- A execução ocorre de forma previsível, reduzindo risco de concorrência.
- Ao final, é gerado um **ACK** confirmando que o comando foi recebido e processado.

### 3.4. Sensores e comunicação com MQTT

Para sensores (movimento, temperatura e umidade), o firmware notifica componentes responsáveis por publicar telemetria. A escolha de múltiplas classes/módulos, mesmo quando seria possível concentrar lógica em um único ponto, foi intencional para reforçar:

- Modularização.
- Separação de responsabilidades.
- Organização do sistema em um formato mais próximo de um produto evolutivo.

## 4. Hardware

O hardware foi desenvolvido conforme o pré-projeto. O diagrama de blocos abaixo resume a estrutura e o funcionamento:

Esquema de Blocos do Hardware

A imagem a seguir mostra o protótipo montado. Nela:

- Adaptador e **servo motor** (acionamento da porta).
- Placa de distribuição **I2C**.
- Sensor de movimento (**MPU5060**).
- Sensor de temperatura e umidade (**AHT10**).
- Teclado.
- A **BitDogLab** ao centro, já integrando LEDs RGB e display OLED.

Circuito do Rack

### Esquemático das Conexões

No esquemático vemos o I2C usado pelo sensor de movimento (MPU6050) e sensor de temperatura e umidade (AHT10) conectado aos pinos GPIO0 e GPIO1 para o canal I2C0 do I2C externalizado através do conector de mesmo nome .

Já o PWM para controle do servo motor está no pino GPIO2, externalizado pelo conector de nome I2C1, mas neste uso não tem relação alguma com o I2C.

Os pinos de conexão do Display OLED são GPIO14 e GPIO15 conectados ao canal I2C1, como usam outros pinos não conflitam com o conector de mesmo nome.

Os LEDs RGB estão conectados nos pinos GPIO12, GPIO13 e GPIO15, respectivamente.

Os buzzer estão conectados ao GPIO10 e GPIO27, sendo controladores por PWM.

Os botões, botão A está conectado ao pino GPIO4 e o botão B GPIO5.

O Ventilador está representado pelo LED Verde, O LED Azul pisca indicando funcionamento do firmware corretamente, durante o boot rápidamente e durante o funcionamento normal muda de estado a cada 1 segundo.

A detecção de porta aberta está sendo feita pelo botão A, ao ser apertado a porta está aberta. em posição normal está fechada.

O botão B, desativa o alarme até a próxima anomalia alertada.

Esquemático das Conexões

## 5. Camada IoT (MQTT)

Foi adotado o protocolo **MQTT** para comunicação entre o firmware e o dashboard, por ser leve e adequado a telemetria e comandos em tempo real.

O broker foi implantado em um **servidor VPS**, com:

- Regras de **firewall** para reduzir superfície de ataque.
- Autenticação por **usuário/senha**.

Isso fornece uma base adequada para segurança operacional no cenário do projeto.

## 6. AIoT (IA aplicada ao sistema)

### 6.1. Integração com LLM via OpenWebUI/Ollama

Foi adotado o **OpenWebUI** como interface de acoplamento entre o dashboard e a engine de LLMs (via **Ollama**). Essa estratégia permite realizar requisições usando compatibilidade com a biblioteca OpenAI, facilitando a troca de engine GenAI sem mudanças grandes no código (normalmente basta alterar URL e chave de API).

### 6.2. Tool Calling para decisão e atuação

Foram usados recursos de **Tool Calling** para apoiar decisões relacionadas a:

- Temperaturas em níveis críticos.
- Acionamento de ventilação.
- Disparo de alarmes.

O modelo utilizado como orquestrador de ferramentas é o **Granite 4** (3 bilhões de parâmetros).

### 6.3. Previsão de temperatura e umidade (TTM)

Foi adicionado um mecanismo de previsão com o **Granite TTM (Tiny Time Series Model)**, utilizando dados históricos para estimar valores futuros de temperatura e umidade. Isso ajuda a antecipar situações de risco (por exemplo, tendência de aquecimento contínuo).

## 7. Treinamento e parametrização da IA

- O prompt principal para o comportamento da GenAI está na pasta `prompts/`.
- As variáveis de execução do dashboard e parâmetros de treinamento/uso do Granite TTM são configuradas via arquivo `.env` na raiz do projeto.

## 8. Dashboard (Python)

O dashboard foi desenvolvido em **Python** para facilitar a integração com a LLM e com o TTM (ambos modelos Granite da IBM) e acelerar os ciclos de teste.

A seguir, a janela principal:

Dashboard Principal

Componentes principais da interface:

- **Lista de racks (lado esquerdo)**: alimentada dinamicamente conforme as telemetrias são publicadas no MQTT. O nome do rack pisca quando algum parâmetro é atualizado.
- **Painel de telemetria (lado direito)**: temperatura e umidade, traço contínuo valor histórico coletado, traço descontinuo previsão com baseno histórico.
- **Controles manuais**: botões para abrir porta e acionar ventilação, além de sinalização do estado do alarme.

Ao rolar o conteúdo, é exibido o mapa de localização do rack, com dados obtidos pelo parâmetro de GPS enviado pelo Rack Inteligente:

Dashboard Mapa

No rodapé, são exibidas as **reflexões e decisões** produzidas pela GenAI a partir dos parâmetros de telemetria.

## 9. Testes realizados (evidências)

Além do uso com o hardware disponível, foram feitos testes para validar escala e estabilidade:

- Teste de **execução contínua** (firmware + dashboard ligados por dias).
- Teste de **carga lógica** no dashboard usando um script Python que simula racks extras publicando dados aleatórios (telemetria e localização), permitindo avaliar:
  - Desempenho da interface.
  - Estabilidade do broker MQTT.
  - Comportamento do sistema sob múltiplas fontes de dados.

### 9.1. Medições e Análise do circuito

Foram feitas medições e analises do circuito para identificar ponto de falhas. Apesar da deformação do sinal no barramento I2C (deveria ser uma onda quadrada mais retilinea) a comunicação funciona perfeitamente bem.

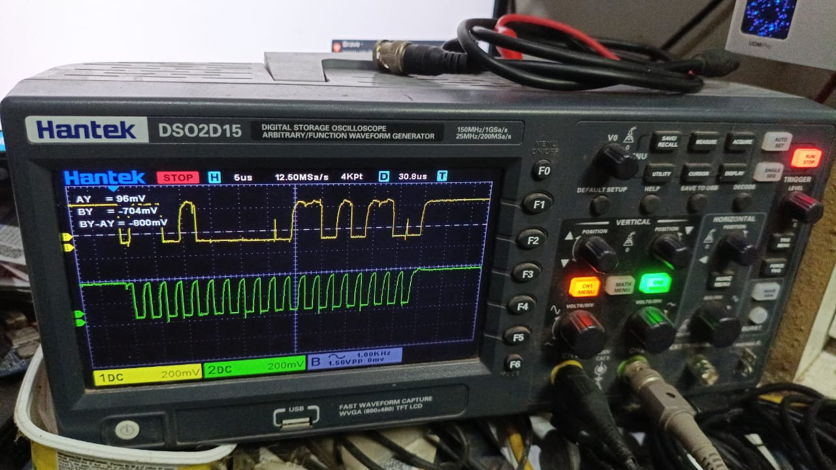
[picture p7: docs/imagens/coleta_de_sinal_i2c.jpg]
Medição da Sinalização I2C


## 10. Problemas encontrados e soluções adotadas

- **Limitação de bancada (ausência de um rack real)**

  - Para simular cenários, foram usados métodos práticos para elevar temperatura/umidade, permitindo observar respostas do sistema.
- **Necessidade de testar vários racks com apenas um kit**

  - Foi criado um simulador que injeta dados de múltiplos racks (com geolocalizações variadas e grande variação de temperatura/umidade), viabilizando testes mais completos do dashboard.
- **Sensor de movimento aparentemente não funcional**

  - Está em avaliação a possibilidade de troca do componente junto ao EmbarcaTech.
- **Falha no envio de umidade (intermitente)**

  - Próxima ação: revisar sincronismo entre a task de coleta e a task de publicação MQTT, garantindo consistência na atualização do valor.

## 11. Próximos passos

- Adicionar um **watchdog timer** para detectar travamentos e reiniciar o hardware quando necessário.
- Finalizar o **menu local** para troca de senha.
- Implementar armazenamento dinâmico e seguro de configurações (por exemplo, senha e dados de rede Wi-Fi).
- Evoluir a coleta e uso de geolocalização do rack, incluindo opções de configuração.
- Adicionar no dashboard recursos para **recuperação de senha remota** (com segurança e auditoria).
- Melhorar o treinamento e calibragem dos componentes de IA, tanto do **Granite TTM** quanto do **Granite LLM**.

## 12. Projeto no GitHub

O projeto pode ser clonado, lembre-se de clonar recursivamente, pois o firmware está em outro repositório. Assim poderá ser analisado em seu estágio atual:

* Projeto Geral: [https://github.com/ArvoreDosSaberes/Embacathec-Etapa-2---Projeto-Final.git](https://github.com/ArvoreDosSaberes/Embacathec-Etapa-2---Projeto-Final.git).
* Projeto Firmware: https://github.com/ArvoreDosSaberes/Embarcatech-Etapa-2---Projeto-Final-firmware
* Em breve Dashboard e Simulador estarão em seus repositórios próprios para facilitar minha gerencia do código.

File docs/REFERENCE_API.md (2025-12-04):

# Referência Técnica da API

Documentação completa das funções, macros e variáveis do projeto Rack Inteligente - EmbarcaTech TIC-27.

---

## 📁 Estrutura do Projeto

```
Projeto_Final/
├── dashboard/           # Dashboard PyQt5 com IA
│   ├── app.py           # Aplicação principal
│   └── services/        # Serviços de negócio
├── firmware/            # Firmware ESP32/RP2040
│   ├── rack_inteligente.cpp  # Ponto de entrada
│   ├── inc/             # Headers do projeto
│   ├── lib/             # Bibliotecas
│   └── tasks/           # Tasks FreeRTOS
├── simulador/           # Simulador MQTT
└── scripts/             # Scripts auxiliares
```

---

# 🐍 Códigos Python

## Dashboard - `dashboard/app.py`

### Classe `MainWindow`

Janela principal do dashboard com interface moderna PyQt5.

#### Sinais

| Sinal | Parâmetros | Descrição |
|---|---|---|
| `message_received` | `dict` | Emitido quando uma mensagem MQTT é recebida |
| `action_executed` | `str, str` | Emitido quando uma ação AI é executada (rackId, action) |
| `status_updated` | `str, str, str` | Emitido para atualizar barra de status (rackId, action, reason) |

#### Atributos de Instância

| Atributo | Tipo | Descrição |
|---|---|---|
| `current_rack_id` | `str` | ID do rack atualmente selecionado |
| `currentRack` | `Rack` | Instância do rack selecionado |
| `racks` | `dict[str, Rack]` | Dicionário de racks (rackId → Rack) |
| `rack_states` | `dict` | Cache de estados dos racks |
| `rackControlService` | `RackControlService` | Serviço de controle via MQTT |
| `toolCallingService` | `ToolCallingService` | Serviço de IA para decisões |
| `forecastService` | `ForecastService` | Serviço de previsão de séries temporais |
| `history_limit` | `int` | Limite de pontos de histórico (7 dias * 3600s) |
| `forecast_horizon` | `int` | Horizonte de previsão em horas (24h) |
| `base_topic` | `str` | Tópico MQTT base (da variável `MQTT_BASE_TOPIC`) |

#### Métodos Principais

```python
def setup_ui(self) -> None
```
Configura a interface gráfica com design moderno UX.

```python
def setup_mqtt(self) -> None
```
Configura cliente MQTT e inicia conexão com o broker.

```python
def handle_message_update(self, data: dict) -> None
```
Processa mensagens MQTT recebidas e atualiza a UI na thread principal.
- **Parâmetros**:
  - `data`: Dicionário com `topic` e `payload`

```python
def sample_current_state(self) -> None
```
Amostra periodicamente a telemetria para preencher gráficos de histórico.

```python
def update_metric_forecast(self, state: dict, metric: str) -> None
```
Calcula previsão para a métrica usando ForecastService.
- **Parâmetros**:
  - `state`: Estado do rack
  - `metric`: Nome da métrica ('temperature' ou 'humidity')

```python
@pyqtSlot(str)
def selectRackFromMap(self, rack_id: str) -> None
```
Callback JavaScript quando rack é clicado no mapa.

```python
def generate_all_racks_map_html(self, selected_rack_id: str = None) -> str
```
Gera HTML do mapa Leaflet/OpenStreetMap com todos os racks.

---

## Serviço de Controle - `dashboard/services/rackControlService.py`

### Enums

#### `DoorStatus(IntEnum)`
| Valor | Nome | Descrição |
|---|---|---|
| 0 | `CLOSED` | Porta fechada |
| 1 | `OPEN` | Porta aberta |

#### `VentilationStatus(IntEnum)`
| Valor | Nome | Descrição |
|---|---|---|
| 0 | `OFF` | Ventilação desligada |
| 1 | `ON` | Ventilação ligada |

#### `BuzzerStatus(IntEnum)`
| Valor | Nome | Descrição |
|---|---|---|
| 0 | `OFF` | Buzzer desligado |
| 1 | `DOOR_OPEN` | Alerta de porta aberta |
| 2 | `BREAK_IN` | Alerta de arrombamento |
| 3 | `OVERHEAT` | Alerta de superaquecimento |

### Classe `Rack`

Representa um rack físico no sistema.

| Atributo | Tipo | Descrição |
|---|---|---|
| `rackId` | `str` | Identificador único do rack |
| `temperature` | `Optional[float]` | Temperatura atual em °C |
| `humidity` | `Optional[float]` | Umidade relativa em % |
| `doorStatus` | `DoorStatus` | Status da porta |
| `ventilationStatus` | `VentilationStatus` | Status da ventilação |
| `buzzerStatus` | `BuzzerStatus` | Status do alarme sonoro |
| `latitude` | `Optional[float]` | Coordenada de latitude |
| `longitude` | `Optional[float]` | Coordenada de longitude |

#### Métodos

```python
def isDoorOpen(self) -> bool
```
Retorna `True` se a porta está aberta.

```python
def isVentilationOn(self) -> bool
```
Retorna `True` se a ventilação está ligada.

```python
def isBuzzerActive(self) -> bool
```
Retorna `True` se o buzzer está ativo (qualquer estado exceto OFF).

### Classe `PendingCommand`

Representa um comando pendente aguardando ACK.

| Atributo | Tipo | Descrição |
|---|---|---|
| `rackId` | `str` | ID do rack alvo |
| `commandType` | `str` | Tipo de comando (door, ventilation, buzzer) |
| `value` | `int` | Valor enviado |
| `timestamp` | `float` | Momento do envio |
| `callback` | `Optional[Callable]` | Callback ao receber ACK |

### Classe `RackControlService`

Serviço de controle de racks via MQTT com confirmação de comandos.

#### Constantes

| Constante | Valor | Descrição |
|---|---|---|
| `DEFAULT_COMMAND_TIMEOUT` | `5.0` | Timeout para ACK em segundos |

#### Métodos de Controle

```python
def openDoor(self, rack: Rack, callback: Optional[Callable[[bool], None]] = None) -> bool
```
Abre a porta do rack. Estado NÃO é atualizado até receber ACK.

```python
def closeDoor(self, rack: Rack, callback: Optional[Callable[[bool], None]] = None) -> bool
```
Fecha a porta do rack. Estado NÃO é atualizado até receber ACK.

```python
def toggleDoor(self, rack: Rack) -> bool
```
Alterna estado da porta.

```python
def turnOnVentilation(self, rack: Rack, callback: Optional[Callable[[bool], None]] = None) -> bool
```
Liga a ventilação do rack.

```python
def turnOffVentilation(self, rack: Rack, callback: Optional[Callable[[bool], None]] = None) -> bool
```
Desliga a ventilação do rack.

```python
def toggleVentilation(self, rack: Rack) -> bool
```
Alterna estado da ventilação.

```python
def activateCriticalTemperatureAlert(self, rack: Rack, callback: Optional[Callable[[bool], None]] = None) -> bool
```
Ativa alerta de superaquecimento (buzzer = 3).

```python
def deactivateCriticalTemperatureAlert(self, rack: Rack, callback: Optional[Callable[[bool], None]] = None) -> bool
```
Desativa alerta de temperatura crítica.

```python
def processAck(self, rackId: str, commandType: str, value: int) -> bool
```
Processa confirmação (ACK) recebida do firmware.

```python
def getExpiredCommands(self) -> list
```
Retorna lista de comandos que expiraram sem ACK.

---

## Serviço de Previsão - `dashboard/services/forecastService.py`

### Variáveis de Módulo

| Variável | Tipo | Descrição |
|---|---|---|
| `GRANITE_AVAILABLE` | `bool` | Indica se IBM Granite TTM-R2 está disponível |

### Classe `ForecastService`

Serviço de previsão de séries temporais com arquitetura híbrida (Granite + SARIMA).

#### Parâmetros do Construtor

| Parâmetro | Tipo | Padrão | Descrição |
|---|---|---|---|
| `model_name` | `str` | `"ibm-granite/granite-timeseries-ttm-r2"` | Nome do modelo |
| `forecast_horizon` | `int` | `24` | Passos de previsão (horas) |
| `context_length` | `int` | `168` | Tamanho do histórico (7 dias) |

#### Atributos

| Atributo | Tipo | Descrição |
|---|---|---|
| `sarimaFallback` | `SarimaFallbackService` | Serviço de fallback SARIMA |
| `maeThreshold` | `float` | Limiar de MAE para ativar fallback |
| `currentMae` | `float` | MAE atual do modelo principal |
| `useFallback` | `bool` | Se está usando fallback |
| `sampleInterval` | `int` | Intervalo de agregação (segundos) |
| `enableAnnualSeasonality` | `bool` | Habilita sazonalidade anual |

#### Métodos

```python
def predict(
    self, 
    data_history: List[Dict], 
    aggregateData: bool = True,
    exogenousData: Optional[List[Dict]] = None
) -> Optional[Dict]
```
Realiza previsão de valores futuros para as próximas 24 horas.

- **Parâmetros**:
  - `data_history`: Histórico de dados (mínimo 10 pontos)
  - `aggregateData`: Se True, agrega dados por hora
  - `exogenousData`: Dados exógenos (ex: umidade)
  
- **Retorno**: Dicionário com previsões ou None se erro

```python
def aggregateHourlyData(self, data_history: List[Dict]) -> List[Dict]
```
Converte amostras de alta frequência em médias horárias.

```python
def addAnnualSeasonalComponent(self, predictions: List[float], baseTimestamp: datetime) -> List[float]
```
Adiciona componente de sazonalidade anual às previsões.

```python
def applyHumidityCorrection(
    self, 
    tempPredictions: List[float], 
    humidityHistory: List[Dict],
    baseTimestamp: datetime
) -> List[float]
```
Aplica correção de umidade às previsões de temperatura.

```python
def updateMaeTracking(self, predicted: float, actual: float) -> float
```
Atualiza tracking de MAE e decide sobre fallback.

```python
def stop(self) -> None
```
Para o serviço graciosamente (suporte a Ctrl+C).

```python
def start(self) -> None
```
Inicia/reinicia o serviço.

---

## Serviço SARIMA Fallback - `dashboard/services/sarimaFallbackService.py`

### Classe `SarimaConfig`

Configuração dos parâmetros SARIMA(p, d, q)(P, D, Q)_s.

| Parâmetro | Tipo | Padrão | Descrição |
|---|---|---|---|
| `p` | `int` | `1` | Ordem AR não sazonal |
| `d` | `int` | `1` | Diferenciações não sazonais |
| `q` | `int` | `1` | Ordem MA não sazonal |
| `P` | `int` | `1` | Ordem AR sazonal |
| `D` | `int` | `1` | Diferenciações sazonais |
| `Q` | `int` | `0` | Ordem MA sazonal |
| `s` | `int` | `24` | Período da sazonalidade |
| `maeThreshold` | `float` | `5.0` | Limiar de MAE |
| `maeWindowSize` | `int` | `50` | Janela para cálculo de MAE |
| `autoSelectParams` | `bool` | `True` | Detecta parâmetros automaticamente |

### Classe `ForecastResult`

| Atributo | Tipo | Descrição |
|---|---|---|
| `predictions` | `List[float]` | Valores previstos |
| `timestamps` | `List[str]` | Timestamps correspondentes |
| `mae` | `Optional[float]` | MAE calculado |
| `modelUsed` | `str` | Nome do modelo |
| `isFromFallback` | `bool` | Se veio do fallback |
| `confidence` | `float` | Nível de confiança (0-1) |

### Classe `SarimaFallbackService`

#### Métodos

```python
def forecast(self, dataHistory: List[Dict], steps: int = 10) -> Optional[ForecastResult]
```
Realiza previsão SARIMA.

```python
def calculateMae(self, predictions: List[float], actuals: List[float]) -> float
```
Calcula Mean Absolute Error (MAE).

```python
def shouldUseFallback(self, graniteMae: Optional[float] = None) -> bool
```
Verifica se fallback deve ser ativado.

```python
def getModelInfo(self) -> Dict
```
Retorna informações do modelo e estado.

---

## Serviço de Tool Calling - `dashboard/services/toolCallingService.py`

### Classe `RackAction`

| Atributo | Tipo | Descrição |
|---|---|---|
| `rackId` | `str` | ID do rack alvo |
| `function` | `str` | Nome da função a executar |
| `reason` | `str` | Motivo da ação |

### Classe `RackTelemetry`

| Atributo | Tipo | Descrição |
|---|---|---|
| `rackId` | `str` | Identificador do rack |
| `temperature` | `Optional[float]` | Temperatura atual em °C |
| `humidity` | `Optional[float]` | Umidade em % |
| `doorStatus` | `int` | Status da porta (0=fechada, 1=aberta) |
| `ventilationStatus` | `int` | Status da ventilação |
| `buzzerStatus` | `int` | Status do buzzer (0-3) |
| `tempAvg` | `Optional[float]` | Média de temperatura da última hora |
| `tempTrend` | `Optional[float]` | Tendência de temperatura (°C/min) |
| `humAvg` | `Optional[float]` | Média de umidade da última hora |
| `humTrend` | `Optional[float]` | Tendência de umidade (%/min) |

### Classe `ThresholdConfig`

Configuração de limiares com histerese (Schmitt Trigger).

| Parâmetro | Tipo | Padrão | Descrição |
|---|---|---|---|
| `tempHighThreshold` | `float` | `35.0` | Temperatura para ligar ventilação |
| `tempLowThreshold` | `float` | `28.0` | Temperatura para desligar ventilação |
| `tempCriticalThreshold` | `float` | `45.0` | Temperatura crítica |
| `tempCriticalReset` | `float` | `40.0` | Reset de alerta crítico |
| `humHighThreshold` | `float` | `80.0` | Umidade alta |
| `humLowThreshold` | `float` | `60.0` | Umidade baixa |

### Classe `ToolCallingService`

#### Constantes

```python
AVAILABLE_FUNCTIONS = {
    'turnOnVentilation',
    'turnOffVentilation',
    'activateCriticalTemperatureAlert',
    'deactivateCriticalTemperatureAlert',
    'activateDoorOpenAlert',
    'activateBreakInAlert',
    'silenceBuzzer',
    'openDoor',
    'closeDoor'
}
```

#### Métodos

```python
def updateTelemetry(self, rackId: str, telemetry: Dict[str, Any]) -> None
```
Atualiza dados de telemetria no buffer e histórico.

```python
def analyzeAndExecute(self, racksDict: Dict[str, Any]) -> List[RackAction]
```
Analisa telemetria e executa ações via LLM (Tool Calling nativo).

```python
def callLlmWithTools(self, telemetryList: List[RackTelemetry]) -> List[RackAction]
```
Chama LLM usando Tool Calling nativo da OpenAI.

```python
def loadPrompt(self, promptName: str) -> str
```
Carrega prompt do arquivo na pasta `prompts/`.

---

## Detector de Anomalias - `dashboard/services/anomalyDetector.py`

### Classe `AnomalyDetector`

Detecta anomalias em séries temporais usando Z-score.

#### Parâmetros do Construtor

| Parâmetro | Tipo | Padrão | Descrição |
|---|---|---|---|
| `threshold_multiplier` | `float` | `3.0` | Múltiplo de σ para anomalia |
| `window_size` | `int` | `50` | Tamanho da janela |
| `rolling_window_seconds` | `int \| None` | `None` | Janela de tempo em segundos |

#### Métodos

```python
def detect(self, current_value: float, data_history: List[Dict]) -> Tuple[bool, Dict]
```
Detecta se o valor atual é uma anomalia.

- **Retorno**: Tupla `(is_anomaly, info)` onde `info` contém:
  - `value`: Valor atual
  - `mean`: Média da janela
  - `stdev`: Desvio padrão
  - `zscore`: Z-score calculado
  - `severity`: 'normal', 'medium', 'high', 'critical'

```python
def get_anomaly_rate(self, recent_count: int = 100) -> float
```
Calcula taxa de anomalias recentes.

```python
def adjust_sensitivity(self, new_threshold: float) -> None
```
Ajusta sensibilidade do detector.

---

## Simulador MQTT - `simulador/mqtt_simulator.py`

### Variáveis de Módulo

```python
FORTALEZA_COORDINATES: list[Tuple[float, float]]
```
Coordenadas fixas de locais em Fortaleza-CE para atribuir aos racks.

### Classe `RackState`

| Atributo | Tipo | Descrição |
|---|---|---|
| `rack_id` | `str` | Identificador do rack |
| `status` | `int` | Estado da porta (0=fechada, 1=aberta) |
| `temperature` | `float` | Temperatura simulada |
| `humidity` | `float` | Umidade simulada |
| `latitude` | `float` | Coordenada latitude |
| `longitude` | `float` | Coordenada longitude |
| `ventilation_status` | `int` | Estado da ventilação |
| `temperature_anomaly` | `Optional[Dict]` | Dados de anomalia térmica |
| `humidity_anomaly` | `Optional[Dict]` | Dados de anomalia de umidade |

### Classe `TelemetryPublisher`

Publicador MQTT para envio de leituras.

```python
def publish(self, topic: str, payload: str) -> None
```
Envia leitura para o broker MQTT.

### Classe `RackSimulator`

Gera e publica telemetria de um rack.

#### Métodos

```python
async def run(self) -> None
```
Executa ciclo assíncrono de geração de telemetria.

```python
def enqueue_command(self, command: str, payload: str) -> None
```
Enfileira comandos vindos do broker MQTT.

```python
def publish_location(self) -> None
```
Publica coordenadas GPS do rack.

### Funções de Módulo

```python
def log_message(sector: str, rack_id: str, message: str, emoji: str) -> None
```
Exibe mensagens padronizadas no console.

```python
def load_mqtt_client() -> mqtt.Client
```
Configura e retorna cliente MQTT baseado em variáveis de ambiente.

```python
def generate_rack_ids(amount: int = 10, reset: bool = False) -> list[str]
```
Gera identificadores únicos para racks com persistência SQLite.

```python
async def run_simulation(reset: bool = False) -> None
```
Inicializa recursos e executa simulação.

---

## Script de Conversão PDF - `scripts/convert_md_to_pdf.py`

### Constantes

```python
PDF_STYLES: str       # Estilos CSS para PDF padrão
ABNT_PDF_STYLES: str  # Estilos CSS para PDF formato ABNT
ROOT_DIR: Path        # Diretório raiz do projeto
DEFAULT_SOURCE: Path  # Diretório fonte padrão (docs/)
DEFAULT_OUTPUT: Path  # Diretório de saída padrão (docs.temp/)
```

### Classes

#### `StandardPdfRenderer`
Renderiza PDFs com estilo padrão.

#### `AbntPdfRenderer`
Renderiza PDFs no formato ABNT com capa e metadados.

### Funções

```python
def parse_front_matter(markdown_text: str) -> tuple[dict, str]
```
Extrai front matter YAML e corpo do markdown.

```python
def convert_markdown_file(
    markdown_file: Path,
    output_dir: Path,
    root: Path,
    *,
    renderer: PdfRenderer
) -> Path
```
Converte um arquivo markdown para PDF.

```python
def main(argv: Sequence[str] | None = None) -> int
```
Ponto de entrada com suporte a argumentos de linha de comando.

---

# 🔧 Códigos C/C++ (Firmware)

## Arquivo Principal - `firmware/rack_inteligente.cpp`

### Variáveis Globais

| Variável | Tipo | Descrição |
|---|---|---|
| `i2c` | `I2C` | Objeto I2C para comunicação com sensores |
| `environment` | `environment_t` | Dados ambientais do rack |
| `mqtt_connected` | `bool` | Estado da conexão MQTT |
| `mqtt_client` | `mqtt_client_t*` | Cliente MQTT |
| `mqtt_rack_topic` | `char[50]` | Tópico MQTT do rack |
| `rack_name` | `char[50]` | Nome/ID do rack |

### Funções

```c
int main(void)
```
Função principal: inicializa Wi-Fi, MQTT, cria tasks FreeRTOS e inicia o scheduler.

```c
static void inpub_cb(void *arg, const char *topic, u32_t tot_len)
```
Callback para identificar tópico MQTT recebido.

```c
static void indata_cb(void *arg, const u8_t *data, u16_t len, u8_t flags)
```
Callback para processar dados da mensagem MQTT recebida.

```c
static void subscribeToCommandTopics(mqtt_client_t *client)
```
Subscreve aos tópicos de comando MQTT após conexão.

```c
static void mqtt_connection_callback(mqtt_client_t *client, void *arg, mqtt_connection_status_t status)
```
Callback de conexão MQTT - inicializa módulo de comandos.

```c
void dns_check_callback(const char *name, const ip_addr_t *ipaddr, void *callback_arg)
```
Callback de resolução DNS do broker MQTT.

```c
void vApplicationStackOverflowHook(TaskHandle_t xTask, char *pcTaskName)
```
Hook FreeRTOS para stack overflow.

### Funções Legadas

```c
static inline void openDoor()
```
Abre porta via servo (delega para `doorServoOpen`).

```c
static inline void closeDoor()
```
Fecha porta via servo (delega para `doorServoClose`).

```c
static inline void turnOnAlarm()
```
Ativa alarme via PWM (delega para `buzzerPwmSetState`).

```c
static inline void turnOffAlarm()
```
Desativa alarme via PWM (delega para `buzzerPwmOff`).

---

## Header Principal - `firmware/inc/rack_inteligente.h`

### Macros

| Macro | Valor | Descrição |
|---|---|---|
| `RACK_DOOR_OPEN` | `true` | Porta aberta |
| `RACK_DOOR_CLOSED` | `false` | Porta fechada |

### Estruturas

#### `gps_position_t`
| Campo | Tipo | Descrição |
|---|---|---|
| `latitude` | `float` | Latitude |
| `longitude` | `float` | Longitude |
| `altitude` | `float` | Altitude |
| `time` | `uint32_t` | Timestamp GPS |
| `speed` | `float` | Velocidade |

#### `environment_t`
| Campo | Tipo | Descrição |
|---|---|---|
| `temperature` | `float` | Temperatura em °C |
| `humidity` | `float` | Umidade em % |
| `door` | `bool` | Estado da porta |
| `tilt` | `bool` | Estado de inclinação |
| `gps_position` | `gps_position_t` | Posição GPS |

---

## Parâmetros - `firmware/inc/rack_inteligente_parametros.h`

### Macros Obrigatórias (definidas via CMake)

| Macro | Descrição |
|---|---|
| `WIFI_SSID` | Nome da rede Wi-Fi |
| `WIFI_PASSWORD` | Senha da rede Wi-Fi |
| `MQTT_BROKER` | Endereço do broker MQTT |
| `MQTT_PORT` | Porta do broker MQTT |
| `MQTT_CLIENT_ID` | ID do cliente MQTT |
| `MQTT_USERNAME` | Usuário MQTT |
| `MQTT_PASSWORD` | Senha MQTT |
| `MQTT_BASE_TOPIC` | Tópico base MQTT |
| `MQTT_RACK_NUMBER` | Número/ID do rack |

### Macros de Pinos GPIO

| Macro | Valor | Descrição |
|---|---|---|
| `LEDG` | `11` | LED verde |
| `LEDB` | `12` | LED azul |
| `LEDR` | `13` | LED vermelho |
| `I2C_SDA_PIN` | `0` | Pino SDA I2C |
| `I2C_SCL_PIN` | `1` | Pino SCL I2C |
| `RACK_DOOR_STATE_PIN` | `5` | Pino de estado da porta (entrada) |
| `RACK_DOOR_LOCK_PIN` | `2` | Pino da trava/servo da porta (saída) |
| `RACK_ALARM_PIN` | `10` | Pino do buzzer |
| `RACK_VENTILATOR_PIN` | `LEDR` | Pino do ventilador |
| `RACK_DOOR_SERVO_PIN` | `RACK_DOOR_LOCK_PIN` | Pino do servo motor |

### Macros de Servo

| Macro | Valor | Descrição |
|---|---|---|
| `DOOR_SERVO_ANGLE_CLOSED` | `0` | Ângulo porta fechada |
| `DOOR_SERVO_ANGLE_OPEN` | `179` | Ângulo porta aberta |

### Macros de Configuração I2C

| Macro | Valor | Descrição |
|---|---|---|
| `I2C_PORT` | `i2c0` | Porta I2C |
| `I2C_BAUD_RATE` | `400000` | Frequência I2C (400kHz) |

### Macros de GPS

| Macro | Valor | Descrição |
|---|---|---|
| `RACK_LATITUDE` | `-3.9012` | Latitude padrão |
| `RACK_LONGITUDE` | `-38.3876` | Longitude padrão |

### Macros de Tasks FreeRTOS

| Macro | Valor | Descrição |
|---|---|---|
| `RACK_BUZZER_TASK_STACK_SIZE` | `configMINIMAL_STACK_SIZE * 2` | Stack do buzzer |
| `RACK_BUZZER_TASK_PRIORITY` | `tskIDLE_PRIORITY + 4` | Prioridade do buzzer |
| `RACK_MQTT_TASK_STACK_SIZE` | `configMINIMAL_STACK_SIZE * 3` | Stack de tasks MQTT |
| `RACK_MQTT_TASK_PRIORITY` | `tskIDLE_PRIORITY + 5` | Prioridade MQTT |
| `RACK_POLLING_TASK_STACK_SIZE` | `configMINIMAL_STACK_SIZE * 2` | Stack de polling |
| `RACK_POLLING_TASK_DELAY` | `500` | Delay de polling (ms) |
| `RACK_NETWORK_POLL_TASK_PRIORITY` | `tskIDLE_PRIORITY + 2` | Prioridade da rede |
| `RACK_WIFI_TIMEOUT` | `20000` | Timeout Wi-Fi (ms) |

### Macros de Timeouts

| Macro | Valor | Descrição |
|---|---|---|
| `RACK_DOOR_OPEN_ALERT_TIMEOUT_MS` | `20 * 60 * 1000` | Timeout de alerta de porta (20 min) |
| `RACK_DOOR_CHECK_INTERVAL_MS` | `1000` | Intervalo de verificação (1s) |

---

## Task de Comandos MQTT - `firmware/tasks/command_mqtt_task.h`

### Enums

#### `CommandType`
| Valor | Nome | Descrição |
|---|---|---|
| `0` | `COMMAND_TYPE_NONE` | Nenhum comando |
| `1` | `COMMAND_TYPE_DOOR` | Comando de porta |
| `2` | `COMMAND_TYPE_VENTILATION` | Comando de ventilação |
| `3` | `COMMAND_TYPE_BUZZER` | Comando de buzzer |

#### `BuzzerState`
| Valor | Nome | Descrição |
|---|---|---|
| `0` | `BUZZER_OFF` | Buzzer desligado |
| `1` | `BUZZER_DOOR_OPEN` | Alerta de porta aberta |
| `2` | `BUZZER_BREAK_IN` | Alerta de arrombamento |
| `3` | `BUZZER_OVERHEAT` | Alerta de superaquecimento |

### Estruturas

#### `CommandQueueItem`
| Campo | Tipo | Descrição |
|---|---|---|
| `type` | `CommandType` | Tipo do comando |
| `value` | `int` | Valor do comando |

### Funções

```c
bool commandMqttInit(void)
```
Inicializa variáveis, filas e hardware do módulo de comandos.

```c
void commandMqttStartTask(void)
```
Inicia task FreeRTOS de processamento de comandos.

```c
void processCommandDoor(int value)
```
Enfileira comando de porta. **Seguro para callbacks MQTT**.
- `value = 1`: Abrir porta
- `value = 0`: Fechar porta

```c
void processCommandVentilation(int value)
```
Enfileira comando de ventilação. **Seguro para callbacks MQTT**.
- `value = 1`: Ligar
- `value = 0`: Desligar

```c
void processCommandBuzzer(int value)
```
Enfileira comando de buzzer. **Seguro para callbacks MQTT**.
- `value = 0-3`: Estado do buzzer

```c
bool publishCommandAck(CommandType commandType, int value)
```
Publica confirmação (ACK) via MQTT.

```c
bool getDoorState(void)
```
Retorna estado atual da porta.

```c
bool getVentilationState(void)
```
Retorna estado atual da ventilação.

```c
BuzzerState getBuzzerState(void)
```
Retorna estado atual do buzzer.

---

## Task do Servo Motor - `firmware/tasks/door_servo_task.c`

### Macros

| Macro | Valor | Descrição |
|---|---|---|
| `SERVO_PWM_FREQ` | `50` | Frequência PWM (50Hz) |
| `SERVO_PULSE_MIN_US` | `500` | Pulso mínimo (0°) em µs |
| `SERVO_PULSE_MAX_US` | `2500` | Pulso máximo (180°) em µs |
| `SERVO_SMOOTH_STEP_DELAY` | `15` | Delay entre passos (ms) |
| `SERVO_SMOOTH_STEP_SIZE` | `3` | Incremento por passo (graus) |

### Enums

#### `DoorServoState`
| Valor | Nome | Descrição |
|---|---|---|
| `0` | `DOOR_SERVO_STATE_CLOSED` | Porta fechada |
| `1` | `DOOR_SERVO_STATE_OPEN` | Porta aberta |
| `2` | `DOOR_SERVO_STATE_MOVING` | Porta em movimento |

### Funções

```c
bool doorServoInit(void)
```
Inicializa hardware PWM e posiciona servo em 0° (fechada).

```c
void doorServoSetAngle(uint8_t angle)
```
Define ângulo do servo (0-180°).

```c
uint8_t doorServoGetAngle(void)
```
Retorna ângulo atual do servo.

```c
DoorServoState doorServoGetState(void)
```
Retorna estado atual do servo.

```c
void doorServoOpen(bool smooth)
```
Abre porta. Se `smooth=true`, movimento gradual.

```c
void doorServoClose(bool smooth)
```
Fecha porta. Se `smooth=true`, movimento gradual.

```c
bool doorServoIsOpen(void)
```
Retorna `true` se porta está aberta (≥180°).

```c
bool doorServoIsClosed(void)
```
Retorna `true` se porta está fechada (0°).

```c
void doorServoDisable(void)
```
Desabilita PWM do servo.

```c
void doorServoEnable(void)
```
Habilita PWM do servo.

---

## Task do Buzzer PWM - `firmware/tasks/buzzer_pwm_task.c`

### Macros

| Macro | Valor | Descrição |
|---|---|---|
| `BUZZER_PWM_PIN` | `RACK_ALARM_PIN` | Pino do buzzer |
| `BUZZER_PWM_DUTY_CYCLE` | `50` | Duty cycle (50%) |
| `BUZZER_MIN_FREQ` | `100` | Frequência mínima (Hz) |
| `BUZZER_MAX_FREQ` | `10000` | Frequência máxima (Hz) |

### Estrutura `BuzzerPattern`

| Campo | Tipo | Descrição |
|---|---|---|
| `frequencyHigh` | `uint32_t` | Frequência do tom alto (Hz) |
| `frequencyLow` | `uint32_t` | Frequência do tom baixo (Hz) |
| `durationHigh` | `uint32_t` | Duração do tom alto (ms) |
| `durationLow` | `uint32_t` | Duração do tom baixo (ms) |
| `pauseDuration` | `uint32_t` | Duração da pausa entre sequências |
| `cyclesBeforePause` | `uint8_t` | Ciclos antes da pausa |

### Padrões Sonoros Predefinidos

| Padrão | Frequência | Ritmo | Uso |
|---|---|---|-----|
| `patternDoorOpen` | 1000Hz / silêncio | beep-beep, pausa 1s | Porta aberta |
| `patternBreakIn` | 2500Hz / 1800Hz | alternância rápida | Arrombamento |
| `patternOverheat` | 500Hz / 300Hz | pulsos longos | Superaquecimento |

### Enums

#### `BuzzerPwmState`
| Valor | Nome | Descrição |
|---|---|---|
| `0` | `BUZZER_STATE_OFF` | Desligado |
| `1` | `BUZZER_STATE_DOOR_OPEN` | Padrão porta aberta |
| `2` | `BUZZER_STATE_BREAK_IN` | Padrão arrombamento |
| `3` | `BUZZER_STATE_OVERHEAT` | Padrão superaquecimento |

### Funções

```c
bool buzzerPwmInit(void)
```
Inicializa hardware PWM e cria task do buzzer.

```c
void buzzerPwmSetState(BuzzerPwmState state)
```
Define estado/padrão do buzzer.

```c
BuzzerPwmState buzzerPwmGetState(void)
```
Retorna estado atual.

```c
void buzzerPwmOff(void)
```
Desliga buzzer.

```c
void buzzerPwmBeep(uint32_t frequency, uint32_t durationMs)
```
Emite beep único com frequência e duração especificadas.

```c
void buzzerPwmTask(void *pvParameters)
```
Task FreeRTOS que executa padrões sonoros.

---

## Biblioteca de Log - `firmware/lib/log_vt100/log_vt100.h`

### Enums

#### `log_level_t`
| Valor | Nome | Cor VT100 |
|---|---|---|
| `0` | `LOG_LEVEL_TRACE` | Cinza |
| `1` | `LOG_LEVEL_DEBUG` | Azul |
| `2` | `LOG_LEVEL_INFO` | Verde |
| `3` | `LOG_LEVEL_WARN` | Amarelo |

### Macros de Configuração

| Macro | Padrão | Descrição |
|---|---|---|
| `LOG_DEFAULT_LEVEL` | `LOG_LEVEL_INFO` | Nível padrão |
| `LOG_LEVEL` | `1` | Verbosidade em tempo de compilação |
| `LOG_TAG` | `NULL` | Tag opcional para mensagens |

### Macros de Logging

```c
LOG_TRACE(fmt, ...)  // Disponível se LOG_LEVEL >= 3
LOG_DEBUG(fmt, ...)  // Disponível se LOG_LEVEL >= 2
LOG_INFO(fmt, ...)   // Disponível se LOG_LEVEL >= 1
LOG_WARN(fmt, ...)   // Sempre disponível se LOG_LEVEL >= 0
```

### Funções

```c
void log_set_level(log_level_t level)
```
Define nível de log em runtime.

```c
void log_write(log_level_t level, const char *fmt, ...)
```
Escreve mensagem de log com formatação estilo printf.
Suporta especificador extra `%b` para binário.

---

## FreeRTOS Config - `firmware/FreeRTOSConfig.h`

### Macros de Configuração Principal

| Macro | Valor | Descrição |
|---|---|---|
| `configUSE_PREEMPTION` | `1` | Preempção habilitada |
| `configTICK_RATE_HZ` | `1000` | 1ms por tick |
| `configMAX_PRIORITIES` | `32` | Níveis de prioridade |
| `configMINIMAL_STACK_SIZE` | `256` | Stack mínima em words |
| `configTOTAL_HEAP_SIZE` | `128*1024` | Heap total (128KB) |
| `configCHECK_FOR_STACK_OVERFLOW` | `2` | Verificação de stack overflow |
| `configUSE_MUTEXES` | `1` | Mutexes habilitados |
| `configUSE_COUNTING_SEMAPHORES` | `1` | Semáforos contadores |
| `configUSE_TIMERS` | `1` | Timers de software |
| `configTIMER_TASK_STACK_DEPTH` | `1024` | Stack da task de timers |

---

# 📡 Tópicos MQTT

## Tópicos de Telemetria (Firmware → Dashboard)

| Tópico | Payload | Descrição |
|---|---|---|
| `{base}/{rack_id}/environment/door` | `0` ou `1` | Estado da porta |
| `{base}/{rack_id}/environment/temperature` | `float` | Temperatura em °C |
| `{base}/{rack_id}/environment/humidity` | `float` | Umidade em % |
| `{base}/{rack_id}/gps` | JSON | Coordenadas GPS |
| `{base}/{rack_id}/tilt` | `0` ou `1` | Inclinação |

## Tópicos de Comando (Dashboard → Firmware)

| Tópico | Payload | Descrição |
|---|---|---|
| `{base}/{rack_id}/command/door` | `0` ou `1` | Fechar/Abrir |
| `{base}/{rack_id}/command/ventilation` | `0` ou `1` | Desligar/Ligar |
| `{base}/{rack_id}/command/buzzer` | `0-3` | Estado do buzzer |

## Tópicos de Confirmação (Firmware → Dashboard)

| Tópico | Payload | Descrição |
|---|---|---|
| `{base}/{rack_id}/ack/door` | `0` ou `1` | ACK de comando de porta |
| `{base}/{rack_id}/ack/ventilation` | `0` ou `1` | ACK de ventilação |
| `{base}/{rack_id}/ack/buzzer` | `0-3` | ACK de buzzer |

---

# 🌍 Variáveis de Ambiente (.env)

| Variável | Descrição | Exemplo |
|---|---|---|
| `MQTT_SERVER` | Endereço do broker MQTT | `broker.mqtt.com` |
| `MQTT_PORT` | Porta do broker | `1883` |
| `MQTT_USERNAME` | Usuário MQTT | `user` |
| `MQTT_PASSWORD` | Senha MQTT | `pass` |
| `MQTT_BASE_TOPIC` | Tópico base | `racks` |
| `FORECAST_CONTEXT_LENGTH` | Histórico em horas | `168` |
| `FORECAST_HORIZON` | Horizonte de previsão | `24` |
| `FORECAST_MAE_THRESHOLD` | Limiar MAE | `5.0` |
| `AI_ANALYSIS_INTERVAL` | Intervalo de análise AI (s) | `10` |
| `TEMP_HIGH_THRESHOLD` | Limiar alto de temperatura | `35` |
| `TEMP_LOW_THRESHOLD` | Limiar baixo de temperatura | `28` |
| `TEMP_CRITICAL_THRESHOLD` | Temperatura crítica | `45` |
| `HUMIDITY_HIGH_THRESHOLD` | Limiar alto de umidade | `80` |
| `HUMIDITY_LOW_THRESHOLD` | Limiar baixo de umidade | `60` |

---

*Documentação gerada automaticamente - Projeto Rack Inteligente EmbarcaTech TIC-27*

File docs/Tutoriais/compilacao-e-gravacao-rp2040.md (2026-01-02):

# Tutorial: Compilação e Gravação do Firmware no RP2040

Este tutorial explica passo a passo como configurar o ambiente, compilar o firmware do projeto **Rack Inteligente** e gravá-lo no microcontrolador **RP2040** (Raspberry Pi Pico W).

---

## Sumário

1. [Pré-requisitos](#1-pré-requisitos)
2. [Instalação do Ambiente](#2-instalação-do-ambiente)
3. [Configuração do Projeto](#3-configuração-do-projeto)
4. [Compilação do Firmware](#4-compilação-do-firmware)
5. [Gravação no RP2040](#5-gravação-no-rp2040)
6. [Verificação e Depuração](#6-verificação-e-depuração)
7. [Resolução de Problemas](#7-resolução-de-problemas)

---

## 1. Pré-requisitos

### Hardware Necessário

- **Raspberry Pi Pico W** (RP2040 com módulo WiFi CYW43439)
- Cabo USB micro-B para conexão com o computador
- (Opcional) Adaptador UART para depuração serial

### Software Necessário

| Software | Versão Mínima | Descrição |
|---|---|---|
| CMake | 3.13+ | Sistema de build |
| ARM GCC Toolchain | 14.2 | Compilador para ARM Cortex-M0+ |
| Pico SDK | 2.1.1 | SDK oficial da Raspberry Pi |
| Git | 2.0+ | Controle de versão |
| picotool | 2.1.1 | Ferramenta de gravação e diagnóstico |

---

## 2. Instalação do Ambiente

### 2.1 Linux (Ubuntu/Debian)

```bash
# 1. Instalar dependências básicas
sudo apt update
sudo apt install -y cmake gcc-arm-none-eabi libnewlib-arm-none-eabi \
    build-essential git libstdc++-arm-none-eabi-newlib

# 2. Clonar o Pico SDK (caso não use a extensão do VS Code)
cd ~
git clone https://github.com/raspberrypi/pico-sdk.git
cd pico-sdk
git submodule update --init

# 3. Configurar variável de ambiente
echo 'export PICO_SDK_PATH=~/pico-sdk' >> ~/.bashrc
source ~/.bashrc
```

### 2.2 Usando a Extensão Raspberry Pi Pico (VS Code) - **Recomendado**

A forma mais simples é utilizar a extensão oficial:

1. Abra o **VS Code**
2. Vá em **Extensions** (Ctrl+Shift+X)
3. Pesquise por **"Raspberry Pi Pico"**
4. Instale a extensão oficial da Raspberry Pi
5. A extensão instalará automaticamente:
   - Pico SDK 2.1.1
   - ARM Toolchain 14.2
   - picotool 2.1.1
   - CMake e Ninja

Os arquivos são instalados em: `~/.pico-sdk/`

### 2.3 Windows

1. Baixe e instale o **Pico Setup for Windows** do site oficial:
   - https://www.raspberrypi.com/documentation/microcontrollers/c_sdk.html
2. Ou use a extensão do VS Code (recomendado)

---

## 3. Configuração do Projeto

### 3.1 Clonar o Repositório

```bash
git clone <url-do-repositorio>
cd Projeto_Final
git submodule update --init --recursive
```

### 3.2 Criar o Arquivo de Configuração `env.cmake`

O projeto requer um arquivo `env.cmake` na **raiz do projeto** com as variáveis de configuração. Este arquivo **não está no repositório** por motivos de segurança.

1. Crie o arquivo `env.cmake` na raiz do projeto:

```bash
touch env.cmake
```

2. Adicione o seguinte conteúdo (ajuste com seus dados):

```cmake
# ===========================================
# Configuração do Firmware - env.cmake
# ===========================================

# WiFi
set(ENV{WIFI_SSID} "SuaRedeWiFi")
set(ENV{WIFI_PASSWORD} "SuaSenhaWiFi")

# MQTT Broker (OBRIGATÓRIO)
set(ENV{MQTT_BROKER} "mqtt.seu-servidor.com")
set(ENV{MQTT_PORT} "1883")
set(ENV{MQTT_USERNAME} "seu_usuario")
set(ENV{MQTT_PASSWORD} "sua_senha")

# MQTT Client
set(ENV{MQTT_CLIENT_ID} "Rack Inteligente")
set(ENV{MQTT_BASE_TOPIC} "racks")
set(ENV{MQTT_RACK_NUMBER} "001")

# Log Level: -1=OFF, 0=ERROR, 1=WARN, 2=INFO, 3=DEBUG
set(ENV{LOG_LEVEL} "2")

# Análise RTOS (opcional, para debug)
# set(ENV{ENABLE_RTOS_ANALYSIS} "1")
# set(ENV{ENABLE_STACK_WATERMARK} "1")
```

### 3.3 Variáveis Obrigatórias

| Variável | Descrição |
|---|---|
| `WIFI_SSID` | Nome da rede WiFi |
| `WIFI_PASSWORD` | Senha da rede WiFi |
| `MQTT_BROKER` | Endereço do broker MQTT |
| `MQTT_USERNAME` | Usuário do broker MQTT |
| `MQTT_PASSWORD` | Senha do broker MQTT |
| `MQTT_RACK_NUMBER` | Identificador único do rack |

---

## 4. Compilação do Firmware

### 4.1 Criar Diretório de Build

```bash
cd firmware
mkdir -p build
cd build
```

### 4.2 Configurar o CMake

```bash
cmake ..
```

**Saída esperada:**
```
-- Arquivo env.cmake carregado com sucesso.
-- WIFI_SSID: SuaRedeWiFi
-- MQTT_BROKER: mqtt.seu-servidor.com
-- LOG_LEVEL: 2
-- Build files have been written to: .../firmware/build
```

### 4.3 Compilar o Projeto

```bash
make -j$(nproc)
```

Ou usando Ninja (mais rápido):

```bash
cmake -G Ninja ..
ninja
```

### 4.4 Arquivos Gerados

Após a compilação bem-sucedida, os seguintes arquivos são gerados em `firmware/build/`:

| Arquivo | Descrição |
|---|---|
| `rack_inteligente.uf2` | Firmware para gravação via USB (modo BOOTSEL) |
| `rack_inteligente.elf` | Binário com símbolos para debug |
| `rack_inteligente.bin` | Binário puro |
| `rack_inteligente.hex` | Formato Intel HEX |

---

## 5. Gravação no RP2040

### 5.1 Método 1: Modo BOOTSEL (USB Mass Storage)

Este é o método mais simples e não requer software adicional.

1. **Desconecte** o Pico W do USB (se estiver conectado)

2. **Pressione e segure** o botão **BOOTSEL** na placa

3. **Conecte** o cabo USB ao computador **mantendo o botão pressionado**

4. **Solte** o botão BOOTSEL após conectar

5. O Pico aparecerá como um **dispositivo de armazenamento USB** chamado `RPI-RP2`

6. **Copie** o arquivo `.uf2` para o dispositivo:

```bash
# Linux
cp firmware/build/rack_inteligente.uf2 /media/$USER/RPI-RP2/

# Ou arraste o arquivo para a unidade RPI-RP2 no gerenciador de arquivos
```

7. O Pico **reiniciará automaticamente** e executará o firmware

### 5.2 Método 2: Usando picotool (Recomendado para Desenvolvimento)

O `picotool` permite gravar sem entrar manualmente no modo BOOTSEL.

```bash
# Gravar o firmware (força modo BOOTSEL via software)
picotool load firmware/build/rack_inteligente.uf2 -f

# Reiniciar o dispositivo após gravação
picotool reboot
```

**Opções úteis:**

```bash
# Verificar informações do firmware atual
picotool info

# Gravar e reiniciar em um comando
picotool load firmware/build/rack_inteligente.uf2 -f -x

# Verificar se o arquivo é válido antes de gravar
picotool verify firmware/build/rack_inteligente.uf2
```

### 5.3 Método 3: Debug via SWD (Avançado)

Para depuração em tempo real com GDB:

1. Conecte um **Raspberry Pi Debug Probe** ou outro adaptador SWD

2. Inicie o OpenOCD:
```bash
openocd -f interface/cmsis-dap.cfg -f target/rp2040.cfg
```

3. Em outro terminal, inicie o GDB:
```bash
arm-none-eabi-gdb firmware/build/rack_inteligente.elf
(gdb) target remote localhost:3333
(gdb) load
(gdb) monitor reset init
(gdb) continue
```

---

## 6. Verificação e Depuração

### 6.1 Monitorar Saída Serial (USB CDC)

O firmware está configurado para saída via **USB CDC** (serial sobre USB).

**Linux:**
```bash
# Identificar a porta serial
ls /dev/ttyACM*

# Conectar usando minicom
minicom -D /dev/ttyACM0 -b 115200

# Ou usando screen
screen /dev/ttyACM0 115200

# Ou usando picocom
picocom -b 115200 /dev/ttyACM0
```

**Permissões (Linux):**
```bash
# Adicionar usuário ao grupo dialout para acesso à serial
sudo usermod -a -G dialout $USER
# Reiniciar a sessão para aplicar
```

### 6.2 Verificar Conexão WiFi e MQTT

Após a gravação, observe os logs no terminal serial:

```
[INFO] WiFi: Conectando a SuaRedeWiFi...
[INFO] WiFi: Conectado! IP: 192.168.1.100
[INFO] MQTT: Conectando ao broker mqtt.seu-servidor.com:1883...
[INFO] MQTT: Conexão estabelecida!
```

### 6.3 Verificar Informações do Firmware

```bash
picotool info -a
```

Saída esperada:
```
Program Information
 name:          rack_inteligente
 version:       0.5
 features:      USB stdin / stdout
 binary start:  0x10000000
 binary end:    0x100xxxxx
```

---

## 7. Resolução de Problemas

### 7.1 Erro: "Arquivo env.cmake não encontrado!"

**Causa:** O arquivo `env.cmake` não existe na raiz do projeto.

**Solução:** Crie o arquivo conforme a seção [3.2](#32-criar-o-arquivo-de-configuração-envcmake).

### 7.2 Erro: "Variável MQTT_USERNAME não definida"

**Causa:** Variável obrigatória faltando no `env.cmake`.

**Solução:** Adicione todas as variáveis obrigatórias no `env.cmake`.

### 7.3 Dispositivo RPI-RP2 não aparece

**Causas possíveis:**
1. Botão BOOTSEL não foi pressionado corretamente
2. Cabo USB com defeito ou apenas para carga (sem dados)
3. Firmware corrompido travando o boot

**Soluções:**
1. Tente novamente pressionando BOOTSEL **antes** de conectar
2. Use outro cabo USB de dados
3. Use o comando `picotool reboot -f -u` para forçar modo BOOTSEL

### 7.4 Erro de compilação: "arm-none-eabi-gcc not found"

**Causa:** Toolchain ARM não está instalado ou não está no PATH.

**Solução:**
```bash
# Ubuntu/Debian
sudo apt install gcc-arm-none-eabi

# Ou verifique se a extensão do VS Code instalou em ~/.pico-sdk
export PATH="$HOME/.pico-sdk/toolchain/14_2_Rel1/bin:$PATH"
```

### 7.5 Sem saída no terminal serial

**Verificações:**
1. Confirme que `pico_enable_stdio_usb` está como `1` no CMakeLists.txt
2. Verifique se a porta serial correta está sendo usada
3. Aguarde alguns segundos após a conexão (o USB CDC demora para inicializar)

### 7.6 WiFi não conecta

**Verificações:**
1. Confirme SSID e senha no `env.cmake`
2. Verifique se a rede é 2.4GHz (Pico W não suporta 5GHz)
3. Aproxime o dispositivo do roteador

---

## Referências

- [Raspberry Pi Pico SDK Documentation](https://www.raspberrypi.com/documentation/microcontrollers/c_sdk.html)
- [Getting Started with Pico W](https://datasheets.raspberrypi.com/picow/connecting-to-the-internet-with-pico-w.pdf)
- [FreeRTOS on RP2040](https://www.freertos.org/Documentation/02-Kernel/02-Kernel-porting-guide/01-Supported-devices/11-Raspberry-Pi-Pico)
- [picotool GitHub](https://github.com/raspberrypi/picotool)

---

**Tempo estimado:** 15-30 minutos para primeira configuração; 2-5 minutos para compilação e gravação subsequentes.

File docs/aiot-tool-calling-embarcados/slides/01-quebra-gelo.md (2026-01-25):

# 🧔 Homens de Barba São Capazes de Grandes Feitos

## O Movimento Beard Culture / Beard Brotherhood

Comunidades informais online que celebram barbas como símbolo de:

- **Maturidade** — A barba como marca de experiência e sabedoria
- **Força** — Símbolo de determinação e resiliência
- **Autenticidade** — Expressão de identidade própria
- **Irmandade** — Conexão entre homens que compartilham valores

## Grandes Barbas da História da Tecnologia

- **Dennis Ritchie** — Criador da linguagem C e Unix
- **Ken Thompson** — Co-criador do Unix e Go
- **Richard Stallman** — Fundador do movimento GNU/Software Livre
- **Robert A. Pease** — Escritor do livro Troubleshooting Analog Circuits

> "Por trás de toda grande inovação, há um grande homem... muitas vezes com uma grande barba!"

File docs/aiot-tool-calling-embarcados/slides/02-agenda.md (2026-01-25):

# 📋 Agenda da Apresentação

## O que vamos explorar juntos:

1. **Inteligência Artificial** — É certo usar este nome?

2. **GenAIs e LLMs** — O que são e como funcionam

3. **AIoT** — A convergência entre IA e IoT

4. **Time Series com Granite TTM** — Previsões inteligentes

5. **Tool Calling** — LLMs que executam ações

6. **Tool Calling no ESP32** — Código real em C/C++

7. **HTTPS no ESP32** — Segurança na comunicação

8. **OpenAI para Demonstração** — Como começar gratuitamente

---

> Objetivo: Desmistificar IA para desenvolvedores embarcados!

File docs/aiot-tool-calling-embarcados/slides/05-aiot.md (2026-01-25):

# 🌐 O que é AIoT?

## Artificial Intelligence + Internet of Things

A **convergência** entre IA e IoT cria dispositivos que:

- **Coletam dados** do mundo físico (sensores)
- **Processam localmente** ou na nuvem
- **Tomam decisões** baseadas em modelos de IA
- **Executam ações** no mundo real (atuadores)

## Arquiteturas de AIoT

| Modelo | Processamento | Latência | Custo |
|---|---|---|---|
| Cloud AI | 100% nuvem | Alta | Baixo/dispositivo |
| Edge AI | No dispositivo | Mínima | Alto/dispositivo |
| Híbrido | Distribuído | Média | Balanceado |

## Exemplos Práticos

- **Rack Inteligente** — Controle térmico preditivo
- **Câmeras de Segurança** — Detecção de intrusão
- **Agricultura** — Irrigação automatizada
- **Indústria 4.0** — Manutenção preditiva

> No nosso projeto: ESP32 envia telemetria → LLM decide → ESP32 executa

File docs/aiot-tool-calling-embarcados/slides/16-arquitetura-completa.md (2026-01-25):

# 🏗️ Arquitetura Completa do Projeto

## Fluxo de Dados

```
┌─────────────────┐     MQTT      ┌─────────────────┐
│     ESP32       │ ────────────→ │   Dashboard     │
│   (Firmware)    │               │    (Python)     │
│                 │ ←──────────── │                 │
└─────────────────┘   Comandos    └────────┬────────┘
        │                                  │
        │ Sensores                         │ HTTPS
        ↓                                  ↓
┌─────────────────┐              ┌─────────────────┐
│  Temperatura    │              │   LLM Server    │
│  Umidade        │              │  (Tool Calling) │
│  Porta (GPIO)   │              │                 │
└─────────────────┘              └─────────────────┘
```

## Componentes do Sistema

- **Firmware ESP32**: Coleta sensores, executa comandos
- **Dashboard Python**: Interface, gráficos, forecast
- **ToolCallingService**: Decisões via LLM
- **ForecastService**: Granite TTM + SARIMA fallback

> O ESP32 não precisa rodar a LLM — apenas executa as decisões!

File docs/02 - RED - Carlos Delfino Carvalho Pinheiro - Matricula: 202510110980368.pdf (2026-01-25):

INSTITUTO FEDERAL DE EDUCAÇÃO, CIÊNCIA E TECNOLOGIA CAMPUS: CAMPUS FORTALEZA
DISCIPLINA: PROJETO INTEGRADOR EMBARCATECH - ETAPA 2 - RESIDÊNCIA

CARLOS DELFINO CARVALHO PINHEIRO 202510110980368

RACK INTELIGENTE: SISTEMA AIOT DE GERENCIAMENTO E SEGURANÇA AMBIENTAL PARA RACKS EM INFRAESTRUTURAS DE PEQUENO PORTE
Trabalho de Conclusão de Curso apresentado ao Instituto Federal como requisito parcial do projeto Embarcatech -Etapa 2 - Residência.

FORTALEZA - CE
2025

RELATÓRIO DE EVIDÊNCIA DE DESENVOLVIMENTO (RED)

### 1. VISÃO GERAL DO PROJETO

Este projeto implementa um Rack Inteligente voltado para monitoramento ambiental e segurança física em infraestruturas de pequeno porte. A solução integra:

Firmware embarcado (C/C++ com FreeRTOS), responsável por leitura de sensores, atuação e comunicação.
Camada IoT via MQTT, para transporte de telemetria e comandos.
Dashboard (Python), para visualização, controle manual e integração com recursos de IA.
AIoT, com uso de LLM e modelos de séries temporais para apoiar decisões e previsões.

A ideia principal é separar bem as responsabilidades para facilitar manutenção, testes e evolução do sistema.

### 2. ESTADO ATUAL (MARCOS E ESTABILIDADE)

O projeto está em estágio avançado, com os marcos principais praticamente entregues. Nesta etapa eu estou focado em:

Revisão geral do código (refatorações pontuais e padronização).
Correção de bugs menores.
Reatividade do sistema, onde testo resposta a comandos e simulação de múltiplos Racks.
Testes de resiliência e estabilidade (execução contínua por longos períodos).

Evidências observadas até aqui:

Firmware: executando por dias com boa estabilidade.
Dashboard: responde bem ao monitoramento simultâneo de dezenas a centenas de racks.
Broker MQTT (Mosquitto) em VPS: serviço estável há mais de 3 meses, sem incidentes relevantes.

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
### 3. ARQUITETURA DO FIRMWARE (C/C++ COM FREERTOS)

### 3.1. ESTRATÉGIA DE CONCORRÊNCIA: UMA TASK POR

RESPONSABILIDADE

Foi adotada a tática de uma task por responsabilidade. Essa decisão melhora:

Diagnóstico (fica mais fácil isolar gargalos e falhas).
Manutenção (alterações ficam localizadas).
Evolução (troca de protocolos ou drivers sem reescrever o sistema inteiro).

Um exemplo importante: para publicação de dados via MQTT, há tasks dedicadas por parâmetro monitorado. Isso permite, se necessário, substituir apenas a parte de transporte (por exemplo, trocar MQTT por outro protocolo) sem interferir na coleta e no cálculo dos parâmetros ambientais.

### 3.2. ENTRADA DO TECLADO E CONTROLE DO MENU

As tasks relacionadas ao teclado utilizam notificações (task notify) com flags para representar as teclas pressionadas. Há duas responsabilidades principais:

Task de leitura de GPIOs do teclado.
Task de processamento das teclas e controle do menu.

O menu é estruturado como uma máquina de estados. Embora ainda não esteja totalmente finalizado, ele demonstra uma abordagem orientada a eventos, típica de sistemas embarcados robustos.

### 3.3. PROCESSAMENTO DE COMANDOS: FILAS (QUEUES) E ACK

Para comandos recebidos (por exemplo, abrir porta, acionar alarme e acionar ventilação), foi adotada a abordagem com queues. Com isso:

Os comandos são enfileirados em ordem FIFO.
A execução ocorre de forma previsível, reduzindo risco de concorrência.
Ao final, é gerado um ACK confirmando que o comando foi recebido e processado.

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
### 3.4. SENSORES E COMUNICAÇÃO COM MQTT

Para sensores (movimento, temperatura e umidade), o firmware notifica componentes responsáveis por publicar telemetria. A escolha de múltiplas classes/módulos, mesmo quando seria possível concentrar lógica em um único ponto, foi intencional para reforçar:

Modularização.
Separação de responsabilidades.
Organização do sistema em um formato mais próximo de um produto evolutivo.

### 4. HARDWARE

O hardware foi desenvolvido conforme o pré-projeto. O diagrama de blocos abaixo resume a estrutura e o funcionamento:

•
•
•

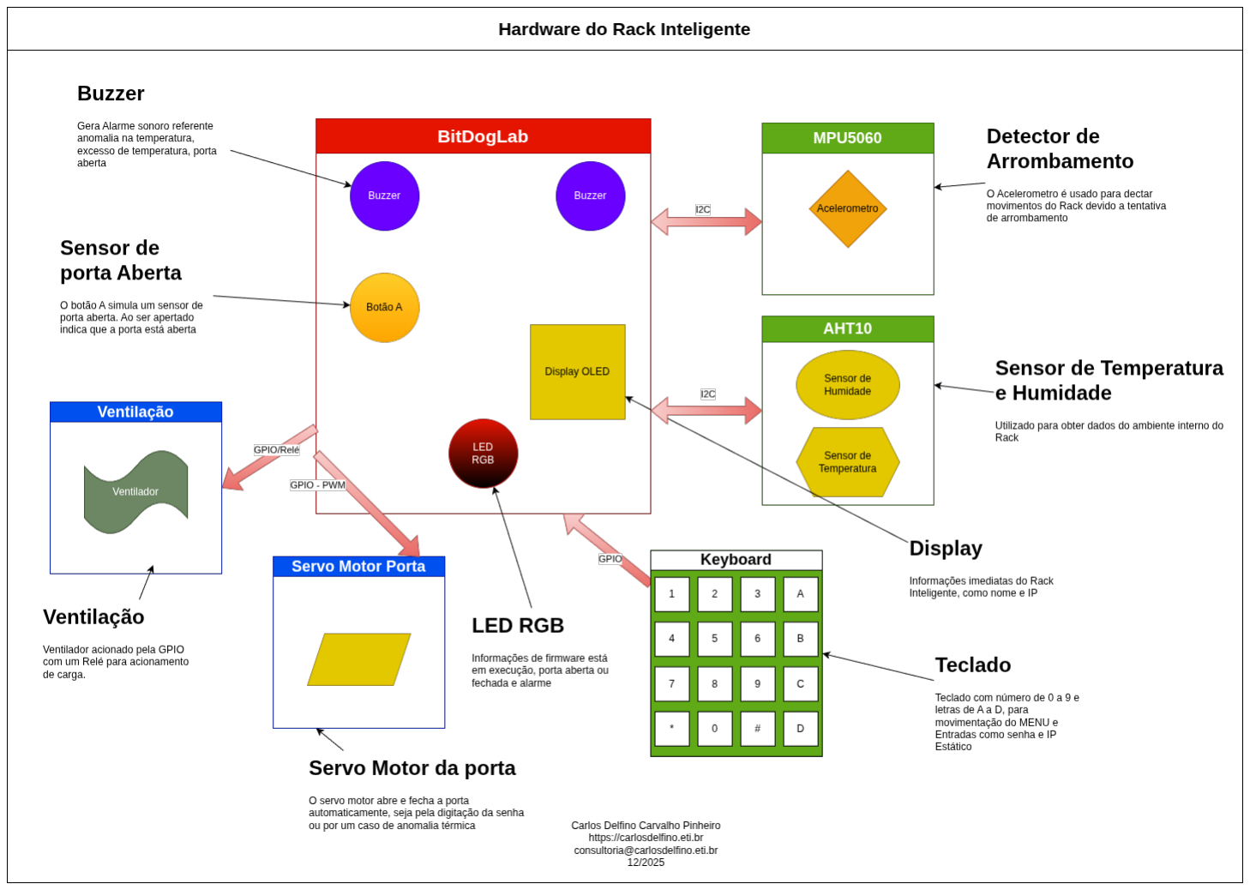
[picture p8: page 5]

A imagem a seguir mostra o protótipo montado. Nela:

Adaptador e servo motor (acionamento da porta). Placa de distribuição I2C.
Sensor de movimento (MPU5060).
Sensor de temperatura e umidade (AHT10).
Teclado.
A BitDogLab ao centro, já integrando LEDs RGB e display OLED.

•
•
•
•
•
•

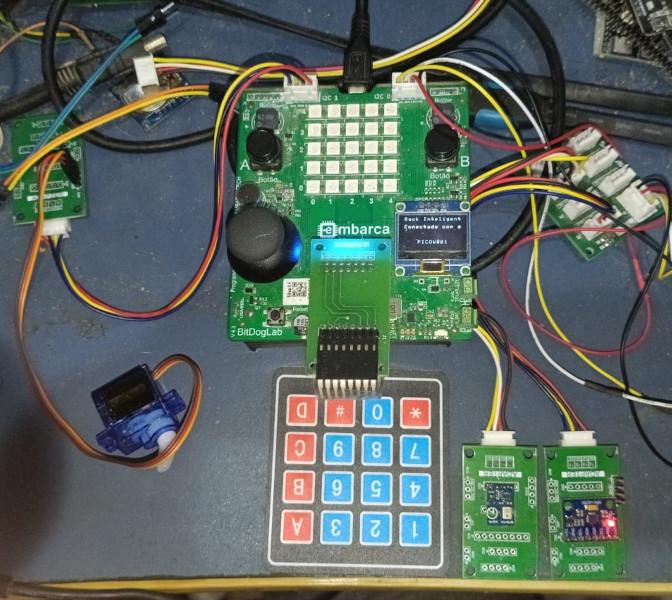
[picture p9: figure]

ESQUEMÁTICO DAS CONEXÕES

No esquemático vemos o I2C usado pelo sensor de movimento (MPU6050) e sensor de temperatura e umidade (AHT10) conectado aos pinos GPIO0 e GPIO1 para o canal I2C0 do I2C externalizado através do conector de mesmo nome .

Já o PWM para controle do servo motor está no pino GPIO2, externalizado pelo conector de nome I2C1, mas neste uso não tem relação alguma com o I2C.

Os pinos de conexão do Display OLED são GPIO14 e GPIO15 conectados ao canal I2C1, como usam outros pinos não conflitam com o conector de mesmo nome.

Os LEDs RGB estão conectados nos pinos GPIO12, GPIO13 e GPIO15, respectivamente.

Os buzzer estão conectados ao GPIO10 e GPIO27, sendo controladores por PWM.

Os botões, botão A está conectado ao pino GPIO4 e o botão B GPIO5.

O Ventilador está representado pelo LED Verde, O LED Azul pisca indicando funcionamento do firmware corretamente, durante o boot rápidamente e durante o funcionamento normal muda de estado a cada 1 segundo.

A detecção de porta aberta está sendo feita pelo botão A, ao ser apertado a porta está aberta. em posição normal está fechada.

O botão B, desativa o alarme até a próxima anomalia alertada.


### 5. CAMADA IOT (MQTT)

Foi adotado o protocolo MQTT para comunicação entre o firmware e o dashboard, por ser leve e adequado a telemetria e comandos em tempo real.

O broker foi implantado em um servidor VPS, com:

Regras de firewall para reduzir superfície de ataque.
Autenticação por usuário/senha.

Isso fornece uma base adequada para segurança operacional no cenário do projeto.

### 6. AIOT (IA APLICADA AO SISTEMA)

### 6.1. INTEGRAÇÃO COM LLM VIA OPENWEBUI/OLLAMA

Foi adotado o OpenWebUI como interface de acoplamento entre o dashboard e a engine de LLMs (via Ollama). Essa estratégia permite realizar requisições usando compatibilidade com a biblioteca OpenAI, facilitando a troca de engine GenAI sem mudanças grandes no código (normalmente basta alterar URL e chave de API).

### 6.2. TOOL CALLING PARA DECISÃO E ATUAÇÃO

Foram usados recursos de Tool Calling para apoiar decisões relacionadas a:

Temperaturas em níveis críticos.
Acionamento de ventilação.
Disparo de alarmes.

O modelo utilizado como orquestrador de ferramentas é o Granite 4 (3 bilhões de parâmetros).

### 6.3. PREVISÃO DE TEMPERATURA E UMIDADE (TTM)

Foi adicionado um mecanismo de previsão com o Granite TTM (Tiny Time Series Model), utilizando dados históricos para estimar valores futuros de temperatura e umidade. Isso ajuda a antecipar situações de risco (por exemplo, tendência de aquecimento contínuo).

•
•

•
•
•

### 7. TREINAMENTO E PARAMETRIZAÇÃO DA IA

O prompt principal para o comportamento da GenAI está na pasta prompts/. As variáveis de execução do dashboard e parâmetros de treinamento/uso do Granite TTM são configuradas via arquivo .env na raiz do projeto.

### 8. DASHBOARD (PYTHON)

O dashboard foi desenvolvido em Python para facilitar a integração com a LLM e com o TTM (ambos modelos Granite da IBM) e acelerar os ciclos de teste.

A seguir, a janela principal:

•
•


Componentes principais da interface:

Lista de racks (lado esquerdo): alimentada dinamicamente conforme as telemetrias são publicadas no MQTT. O nome do rack pisca quando algum parâmetro é atualizado.
Painel de telemetria (lado direito): temperatura e umidade, traço contínuo valor histórico coletado, traço descontinuo previsão com baseno histórico. Controles manuais: botões para abrir porta e acionar ventilação, além de sinalização do estado do alarme.

Ao rolar o conteúdo, é exibido o mapa de localização do rack, com dados obtidos pelo parâmetro de GPS enviado pelo Rack Inteligente:

•

•

•


No rodapé, são exibidas as reflexões e decisões produzidas pela GenAI a partir dos parâmetros de telemetria.

### 9. TESTES REALIZADOS (EVIDÊNCIAS)

Além do uso com o hardware disponível, foram feitos testes para validar escala e estabilidade:

Teste de execução contínua (firmware + dashboard ligados por dias).
Teste de carga lógica no dashboard usando um script Python que simula racks extras publicando dados aleatórios (telemetria e localização), permitindo avaliar: Desempenho da interface.
Estabilidade do broker MQTT.
Comportamento do sistema sob múltiplas fontes de dados.

### 9.1. MEDIÇÕES E ANÁLISE DO CIRCUITO

Foram feitas medições e analises do circuito para identificar ponto de falhas. Apesar da deformação do sinal no barramento I2C (deveria ser uma onda quadrada mais retilinea) a comunicação funciona perfeitamente bem.

•
•

•
•
•


### 10. PROBLEMAS ENCONTRADOS E SOLUÇÕES ADOTADAS

Limitação de bancada (ausência de um rack real)

Para simular cenários, foram usados métodos práticos para elevar temperatura/ umidade, permitindo observar respostas do sistema.

Necessidade de testar vários racks com apenas um kit

Foi criado um simulador que injeta dados de múltiplos racks (com geolocalizações variadas e grande variação de temperatura/umidade), viabilizando testes mais completos do dashboard.

Sensor de movimento aparentemente não funcional

Está em avaliação a possibilidade de troca do componente junto ao EmbarcaTech.

Falha no envio de umidade (intermitente)

Próxima ação: revisar sincronismo entre a task de coleta e a task de publicação MQTT, garantindo consistência na atualização do valor.

### 11. PRÓXIMOS PASSOS

Adicionar um watchdog timer para detectar travamentos e reiniciar o hardware quando necessário.
Finalizar o menu local para troca de senha.
Implementar armazenamento dinâmico e seguro de configurações (por exemplo, senha e dados de rede Wi-Fi).
Evoluir a coleta e uso de geolocalização do rack, incluindo opções de configuração.
Adicionar no dashboard recursos para recuperação de senha remota (com segurança e auditoria).
Melhorar o treinamento e calibragem dos componentes de IA, tanto do Granite TTM quanto do Granite LLM.

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
### 12. PROJETO NO GITHUB

O projeto pode ser clonado, lembre-se de clonar recursivamente, pois o firmware está em outro repositório. Assim poderá ser analisado em seu estágio atual:

Projeto Geral: https://github.com/ArvoreDosSaberes/Embacathec-Etapa-2---Projeto-Final.git. (https://github.com/ArvoreDosSaberes/Embacathec-Etapa-2---Projeto-Final.git)
Projeto | Firmware: | https://github.com/ArvoreDosSaberes/Embarcatech-
Etapa-2---Projeto-Final-firmware
Em breve Dashboard e Simulador estarão em seus repositórios próprios para facilitar minha gerencia do código.

•

•

•

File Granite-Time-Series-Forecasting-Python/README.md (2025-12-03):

# 🔮 Granite Time Series Forecasting

Sistema de previsão de séries temporais em tempo real usando o modelo **IBM Granite TTM-R2** (Tiny Time Mixer).

> **🔧 Última atualização**: Melhorias de diagnóstico e estabilidade do WebSocket - veja [WEBSOCKET_DIAGNOSTICS.md](docs/WEBSOCKET_DIAGNOSTICS.md)

## 📋 Visão Geral

Este projeto demonstra o uso do modelo Granite TTM-R2 para:

- **Previsão de valores futuros** em séries temporais
- **Detecção de anomalias** em tempo real
- **Identificação de padrões** e tendências
- **Visualização interativa** com gráficos dinâmicos
- **Alertas automáticos** quando valores saem do padrão esperado

## ✨ Funcionalidades

### 🎯 Core Features

- ✅ **Geração contínua de dados sintéticos** com características realistas:
  - Tendência temporal
  - Sazonalidade (padrões cíclicos)
  - Ruído aleatório
  - Anomalias ocasionais (5% de probabilidade)

- ✅ **Previsão em tempo real** usando IBM Granite TTM-R2:
  - Horizonte configurável (padrão: 96 pontos)
  - Contexto histórico de 512 pontos
  - Zero-shot forecasting (sem necessidade de treinamento)

- ✅ **Detecção de anomalias** baseada em análise estatística:
  - Z-score (desvio padrão)
  - Threshold configurável (padrão: 3σ)
  - Classificação de severidade (normal, medium, high, critical)

- ✅ **Interface web moderna e responsiva**:
  - Gráfico de linha dinâmico (Chart.js)
  - Alertas visuais de anomalias
  - Estatísticas em tempo real
  - Controles de start/stop/reset

### 🔄 Arquitetura em Tempo Real

```
┌─────────────────┐
│  Data Generator │ ──► Gera pontos a cada 2s
└────────┬────────┘
         │
         ▼
┌─────────────────┐
│ Forecast Service│ ──► Prevê próximos 96 pontos
└────────┬────────┘
         │
         ▼
┌─────────────────┐
│ Anomaly Detector│ ──► Detecta desvios > 3σ
└────────┬────────┘
         │
         ▼
┌─────────────────┐
│   WebSocket     │ ──► Envia para frontend
└────────┬────────┘
         │
         ▼
┌─────────────────┐
│  Web Interface  │ ──► Visualização interativa
└─────────────────┘
```

## 🚀 Instalação

### Pré-requisitos

- Python 3.8+
- pip
- (Opcional) CUDA para aceleração GPU

### Passo a Passo

1. **Clone o repositório** (ou navegue até a pasta do projeto):

```bash
cd Granite-Time-Series-Forecasting-Python
```

2. **Crie um ambiente virtual** (recomendado):

```bash
python -m venv venv
source venv/bin/activate  # Linux/Mac
# ou
venv\Scripts\activate  # Windows
```

3. **Instale as dependências**:

```bash
pip install -r requirements.txt
```

4. **Configure as variáveis de ambiente**:

```bash
cp .env.example .env
# Edite o arquivo .env conforme necessário
```

5. **Execute a aplicação**:

```bash
python app.py
```

6. **Acesse a interface web**:

Abra seu navegador em: [http://localhost:5000](http://localhost:5000)

## ⚙️ Configuração

Todas as configurações podem ser ajustadas no arquivo `.env`:

### Servidor

```env
PORT=5000                    # Porta do servidor
DEBUG=False                  # Modo debug
SECRET_KEY=your-secret-key   # Chave secreta Flask
```

### Modelo

```env
MODEL_NAME=ibm-granite/granite-timeseries-ttm-r2
FORECAST_HORIZON=96          # Pontos futuros a prever
CONTEXT_LENGTH=512           # Janela de contexto histórico
```

### Geração de Dados

```env
DATA_GENERATION_INTERVAL=2.0  # Intervalo entre gerações (segundos)
BASE_VALUE=100.0              # Valor base da série
NOISE_LEVEL=5.0               # Amplitude do ruído
TREND_ENABLED=True            # Habilitar tendência
SEASONALITY_ENABLED=True      # Habilitar sazonalidade
```

### Detecção de Anomalias

```env
ANOMALY_THRESHOLD_MULTIPLIER=3.0  # Múltiplo do desvio padrão (3σ = 99.7%)
ANOMALY_WINDOW_SIZE=50            # Janela para calcular estatísticas
```

## 📊 Uso

### Interface Web

1. **Iniciar processamento**: Clique no botão "▶️ Iniciar"
2. **Observar dados**: O gráfico será atualizado em tempo real
3. **Alertas**: Anomalias dispararão alertas visuais automáticos
4. **Parar**: Use o botão "⏸️ Parar" para pausar
5. **Resetar**: Limpe todos os dados com "🔄 Resetar"

### API REST

#### Status do Sistema

```bash
GET /api/status
```

Retorna:
```json
{
  "running": true,
  "data_points": 150,
  "anomaly_count": 5,
  "total_predictions": 148,
  "model_loaded": true,
  "config": {
    "forecast_horizon": 96,
    "context_length": 512,
    "generation_interval": 2.0
  }
}
```

#### Histórico de Dados

```bash
GET /api/history
```

Retorna últimos 100 pontos de dados e 10 previsões.

### WebSocket Events

#### Cliente → Servidor

- `start_processing`: Inicia geração e previsão
- `stop_processing`: Para processamento
- `reset_data`: Limpa todos os dados

#### Servidor → Cliente

- `connected`: Confirmação de conexão
- `new_data`: Novos dados, previsões e anomalias
- `status_changed`: Mudança de estado (running/stopped)
- `data_reset`: Confirmação de reset

## 🏗️ Estrutura do Projeto

```
Granite-Time-Series-Forecasting-Python/
├── app.py                          # Aplicação Flask principal
├── requirements.txt                # Dependências Python
├── .env.example                    # Exemplo de configuração
├── README.md                       # Este arquivo
│
├── src/
│   ├── __init__.py
│   ├── config.py                   # Configurações centralizadas
│   │
│   └── services/
│       ├── __init__.py
│       ├── dataGenerator.py        # Gerador de dados sintéticos
│       ├── forecastService.py      # Serviço de previsão (Granite)
│       └── anomalyDetector.py      # Detector de anomalias
│
├── templates/
│   └── index.html                  # Interface web
│
└── static/
    └── app.js                      # Frontend JavaScript
```

## 🤖 Sobre o Modelo Granite TTM-R2

O **Tiny Time Mixer (TTM)** é um modelo de previsão de séries temporais desenvolvido pela IBM Research:

- **Zero-shot forecasting**: Funciona sem necessidade de treinamento adicional
- **Eficiente**: Otimizado para baixa latência e consumo de recursos
- **Versátil**: Suporta múltiplos domínios e padrões temporais
- **Estado da arte**: Performance competitiva com modelos maiores

### Referências

- 🤗 [Hugging Face Model Card](https://huggingface.co/ibm-granite/granite-timeseries-ttm-r2)
- 📄 [Paper: Tiny Time Mixers](https://arxiv.org/abs/2401.03955)
- 🔗 [IBM Research Blog](https://research.ibm.com/)

## 🔧 Desenvolvimento

### Estrutura de Código

O projeto segue princípios de **Domain-Driven Design (DDD)**:

- **Separação de responsabilidades**: Cada serviço tem uma função específica
- **Modularidade**: Componentes independentes e reutilizáveis
- **Documentação**: Código amplamente documentado com docstrings
- **Logging**: Sistema de logs estruturado para debugging

### Complexidade Algorítmica

- **Geração de dados**: O(1) por ponto
- **Previsão**: O(n + m) onde n = context_length, m = forecast_horizon
- **Detecção de anomalias**: O(w) onde w = window_size
- **Atualização de gráfico**: O(1) amortizado

### Testes

Para executar testes (quando implementados):

```bash
pytest tests/ -v --cov=src
```

## 📈 Performance

### Requisitos de Sistema

- **CPU**: 2+ cores recomendado
- **RAM**: 4GB mínimo, 8GB recomendado
- **GPU**: Opcional (CUDA compatível para aceleração)
- **Disco**: ~2GB para modelo e dependências

### Otimizações

- **Lazy loading**: Modelo carregado apenas quando necessário
- **Batch processing**: Suporte a processamento em lote
- **Memory management**: Limite de histórico em memória
- **WebSocket**: Comunicação eficiente em tempo real

## 🐛 Troubleshooting

### Erro: "ModuleNotFoundError: No module named 'tsfm_public'"

```bash
pip install tsfm_public
```

### Erro: "CUDA out of memory"

Ajuste no `.env`:
```env
USE_GPU=False
```

### Gráfico não atualiza

1. Verifique console do navegador (F12)
2. Confirme conexão WebSocket
3. Reinicie o servidor

### Modelo demora para carregar

O primeiro carregamento baixa o modelo (~500MB). Aguarde a conclusão.

## 📝 Licença

Este projeto é fornecido como exemplo educacional. O modelo Granite TTM-R2 possui sua própria licença (consulte Hugging Face).

## 🤝 Contribuições

Contribuições são bem-vindas! Áreas de melhoria:

- [ ] Suporte a múltiplas séries temporais simultâneas
- [ ] Persistência de dados em banco de dados
- [ ] Exportação de relatórios (PDF/CSV)
- [ ] Testes unitários e de integração
- [ ] Docker containerization
- [ ] Autenticação e autorização
- [ ] Dashboard administrativo

## 📧 Contato

Para dúvidas ou sugestões, abra uma issue no repositório.

---

**🚀 Desenvolvido com Flask, Socket.IO, Chart.js e IBM Granite TTM-R2**

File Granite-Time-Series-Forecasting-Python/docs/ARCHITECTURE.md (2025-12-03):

# 🏗️ Arquitetura do Sistema

Documentação técnica da arquitetura do **Granite Time Series Forecasting System**.

## 📐 Visão Geral

O sistema segue uma arquitetura **modular e orientada a serviços**, baseada nos princípios de **Domain-Driven Design (DDD)**.

```
┌─────────────────────────────────────────────────────────────┐
│                      Frontend (Web UI)                      │
│  ┌──────────────┐  ┌──────────────┐  ┌──────────────┐     │
│  │  Chart.js    │  │  WebSocket   │  │  Controls    │     │
│  │  Visualizer  │  │  Client      │  │  & Stats     │     │
│  └──────────────┘  └──────────────┘  └──────────────┘     │
└────────────────────────┬────────────────────────────────────┘
                         │ WebSocket / REST API
┌────────────────────────┴────────────────────────────────────┐
│                   Backend (Flask Server)                    │
│  ┌──────────────────────────────────────────────────────┐  │
│  │              Flask + SocketIO Core                   │  │
│  │  • Routing  • WebSocket Events  • API Endpoints     │  │
│  └──────────────────────────────────────────────────────┘  │
│                                                              │
│  ┌──────────────┐  ┌──────────────┐  ┌──────────────┐     │
│  │    Data      │  │   Forecast   │  │   Anomaly    │     │
│  │  Generator   │  │   Service    │  │   Detector   │     │
│  │   Service    │  │   (Granite)  │  │   Service    │     │
│  └──────────────┘  └──────────────┘  └──────────────┘     │
│         │                  │                  │             │
│         └──────────────────┴──────────────────┘             │
│                            │                                │
│                    ┌───────┴────────┐                       │
│                    │  Configuration │                       │
│                    │    Manager     │                       │
│                    └────────────────┘                       │
└─────────────────────────────────────────────────────────────┘
                             │
                    ┌────────┴─────────┐
                    │  IBM Granite     │
                    │  TTM-R2 Model    │
                    │  (Hugging Face)  │
                    └──────────────────┘
```

## 🔧 Componentes Principais

### 1. Frontend (Web UI)

**Tecnologias**: HTML5, JavaScript (ES6+), Chart.js, Socket.IO Client, Tailwind CSS

**Responsabilidades**:
- Renderização de interface responsiva
- Visualização de gráficos em tempo real
- Comunicação WebSocket com backend
- Gerenciamento de estado local
- Exibição de alertas e estatísticas

**Arquivos**:
- `templates/index.html` - Template HTML principal
- `static/app.js` - Lógica JavaScript do frontend

### 2. Backend (Flask Server)

**Tecnologias**: Python 3.8+, Flask, Flask-SocketIO, Flask-CORS

**Responsabilidades**:
- Servidor HTTP e WebSocket
- Orquestração de serviços
- Gerenciamento de threads
- Roteamento de API REST
- Broadcasting de eventos

**Arquivo Principal**: `app.py`

**Endpoints REST**:
- `GET /` - Interface web
- `GET /api/status` - Status do sistema
- `GET /api/history` - Histórico de dados

**Eventos WebSocket**:
- `connect` / `disconnect` - Gerenciamento de conexões
- `start_processing` - Iniciar geração
- `stop_processing` - Parar geração
- `reset_data` - Limpar dados
- `new_data` - Broadcast de novos dados (servidor → cliente)

### 3. Data Generator Service

**Arquivo**: `src/services/dataGenerator.py`

**Responsabilidades**:
- Geração de séries temporais sintéticas
- Simulação de padrões realistas:
  - Tendência linear
  - Sazonalidade (ciclos)
  - Ruído gaussiano
  - Anomalias ocasionais (5%)

**Algoritmo de Geração**:

```python
valor_final = base_value + tendência + sazonalidade + ruído

# Componentes:
tendência = coeficiente * t
sazonalidade = amplitude * sin(2π * t / período)
ruído = N(0, σ²)  # Distribuição normal
```

**Complexidade**: O(1) por ponto gerado

### 4. Forecast Service

**Arquivo**: `src/services/forecastService.py`

**Responsabilidades**:
- Carregamento do modelo Granite TTM-R2
- Preparação de dados de entrada
- Execução de previsões
- Pós-processamento de resultados

**Modelo**: IBM Granite TTM-R2 (Tiny Time Mixer)
- **Tipo**: Zero-shot time series forecasting
- **Arquitetura**: Transformer-based
- **Parâmetros**: ~5M (otimizado para eficiência)
- **Contexto**: 512 pontos históricos
- **Horizonte**: 96 pontos futuros (configurável)

**Pipeline de Previsão**:

```
1. Receber histórico (mínimo: context_length pontos)
2. Preparar DataFrame com timestamp + value
3. Executar pipeline do modelo
4. Extrair previsões
5. Gerar timestamps futuros
6. Retornar resultados estruturados
```

**Complexidade**: O(n + m) onde n = context_length, m = forecast_horizon

### 5. Anomaly Detector Service

**Arquivo**: `src/services/anomalyDetector.py`

**Responsabilidades**:
- Detecção de valores anômalos
- Cálculo de estatísticas (média, desvio padrão)
- Classificação de severidade
- Manutenção de histórico de anomalias

**Algoritmo**: Z-Score (Statistical Outlier Detection)

```python
z_score = |valor - média| / desvio_padrão

# Classificação:
z > threshold (3σ) → Anomalia
  z > 5σ → Critical
  z > 4σ → High
  z > 3σ → Medium
z ≤ 3σ → Normal
```

**Janela Deslizante**: Usa últimos N pontos (padrão: 50) para calcular estatísticas adaptativas.

**Complexidade**: O(w) onde w = window_size

### 6. Configuration Manager

**Arquivo**: `src/config.py`

**Responsabilidades**:
- Centralização de configurações
- Carregamento de variáveis de ambiente
- Validação de parâmetros
- Defaults seguros

**Fontes de Configuração** (ordem de precedência):
1. Variáveis de ambiente
2. Arquivo `.env`
3. Valores padrão no código

## 🔄 Fluxo de Dados

### Fluxo Principal (Tempo Real)

```
1. Thread Background (loop infinito):
   ├─► Data Generator: gera novo ponto
   ├─► Adiciona ao histórico
   ├─► Forecast Service: prevê próximos valores (se histórico >= context_length)
   ├─► Anomaly Detector: verifica se é anomalia
   └─► WebSocket: emite evento 'new_data' para todos os clientes

2. Frontend (ao receber 'new_data'):
   ├─► Atualiza gráfico (Chart.js)
   ├─► Atualiza estatísticas
   ├─► Exibe alerta (se anomalia)
   └─► Atualiza displays de valor atual e previsão
```

### Fluxo de Inicialização

```
1. Usuário acessa http://localhost:5000
2. Flask renderiza index.html
3. Frontend carrega app.js
4. WebSocket conecta ao servidor
5. Frontend solicita status via REST API
6. Usuário clica "Iniciar"
7. Frontend emite evento 'start_processing'
8. Backend inicia thread de processamento
9. Loop de geração/previsão/detecção começa
```

## 🧵 Threading Model

O sistema usa **threading** para processamento assíncrono:

```
Main Thread (Flask)
├─► HTTP Request Handler
├─► WebSocket Event Handler
└─► SocketIO Background Tasks

Background Thread (daemon)
└─► Data Generation Loop
    ├─► Generate Point
    ├─► Forecast (if enough data)
    ├─► Detect Anomaly
    └─► Emit via WebSocket
```

**Sincronização**: Estado compartilhado via dicionário `app_state` (thread-safe para operações simples).

## 📊 Estrutura de Dados

### Ponto de Dados

```python
{
    'timestamp': '2024-01-01T12:00:00',  # ISO 8601
    'value': 105.23,                      # float
    'index': 42,                          # int (contador)
    'components': {                       # Decomposição
        'base': 100.0,
        'trend': 0.42,
        'seasonality': 3.5,
        'noise': 1.31
    },
    'is_injected_anomaly': False         # bool
}
```

### Previsão

```python
{
    'predictions': [                      # Lista de previsões
        {
            'timestamp': '2024-01-01T12:00:02',
            'value': 106.5,
            'horizon_step': 1             # Passo à frente
        },
        # ... mais 95 pontos
    ],
    'forecast_timestamp': '2024-01-01T12:00:00',
    'context_size': 512,
    'model': 'ibm-granite/granite-timeseries-ttm-r2'
}
```

### Informação de Anomalia

```python
{
    'value': 150.0,                       # Valor anômalo
    'mean': 100.0,                        # Média da janela
    'stdev': 5.0,                         # Desvio padrão
    'zscore': 10.0,                       # Z-score
    'threshold': 3.0,                     # Threshold configurado
    'deviation': 10.0,                    # Número de sigmas
    'window_size': 50,                    # Tamanho da janela
    'is_anomaly': True,                   # Classificação
    'severity': 'critical',               # Severidade
    'severity_emoji': '🔴'                # Emoji visual
}
```

## 🔐 Segurança

### Considerações Implementadas

- ✅ **CORS**: Configurado via Flask-CORS
- ✅ **WebSocket Origin**: Permitido para desenvolvimento
- ✅ **Secret Key**: Configurável via ambiente
- ✅ **Input Validation**: Validação de configurações

### Melhorias Futuras

- [ ] Autenticação de usuários
- [ ] Rate limiting
- [ ] HTTPS/WSS em produção
- [ ] Sanitização de inputs
- [ ] Logging de auditoria

## 📈 Performance

### Otimizações Implementadas

1. **Lazy Loading**: Modelo carregado apenas quando necessário
2. **Memory Management**: Limite de histórico em memória (1000 pontos)
3. **Chart Updates**: Sem animação para melhor performance
4. **Batch Operations**: Suporte a processamento em lote
5. **GPU Acceleration**: Detecção automática de CUDA

### Benchmarks Esperados

| Operação | Tempo (CPU) | Tempo (GPU) |
|---|---|---|
| Gerar ponto | ~1ms | N/A |
| Detectar anomalia | ~5ms | N/A |
| Previsão (96 pontos) | ~500ms | ~50ms |
| Update gráfico | ~10ms | N/A |

## 🔧 Extensibilidade

### Pontos de Extensão

1. **Novos Geradores**: Implementar `DataGenerator` customizado
2. **Detectores Alternativos**: Substituir `AnomalyDetector` (ex: Isolation Forest)
3. **Modelos Diferentes**: Trocar Granite por outro modelo Hugging Face
4. **Persistência**: Adicionar camada de banco de dados
5. **Notificações**: Integrar com sistemas externos (email, Slack, etc.)

### Exemplo: Adicionar Novo Detector

```python
# src/services/customDetector.py
class CustomAnomalyDetector:
    def detect(self, value, history):
        # Implementar lógica customizada
        pass

# app.py
from src.services.customDetector import CustomAnomalyDetector
anomaly_detector = CustomAnomalyDetector()
```

## 📚 Referências Técnicas

- [Flask Documentation](https://flask.palletsprojects.com/)
- [Flask-SocketIO](https://flask-socketio.readthedocs.io/)
- [Chart.js](https://www.chartjs.org/)
- [IBM Granite TTM-R2](https://huggingface.co/ibm-granite/granite-timeseries-ttm-r2)
- [PyTorch](https://pytorch.org/)

---

**Última atualização**: 2024-01-01

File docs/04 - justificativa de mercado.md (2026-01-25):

---
title: "Rack Inteligente AIoT: Justificativa de Mercado, Impacto Econômico e Projeções"
authors:
  - "Carlos Delfino Carvalho Pinheiro"
summary: "Documento de justificativa do projeto com foco em mercado, impacto econômico de redes e projeções, baseado em fontes públicas (IBGE, Sebrae, Uptime Institute)."
language: "pt-BR"
date: "2026-01-25"
tags:
  - "EmbarcaTech"
  - "AIoT"
  - "IoT"
  - "Redes de Computadores"
  - "Mercado"
  - "Justificativa"
  - "Disponibilidade"
  - "Segurança"
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

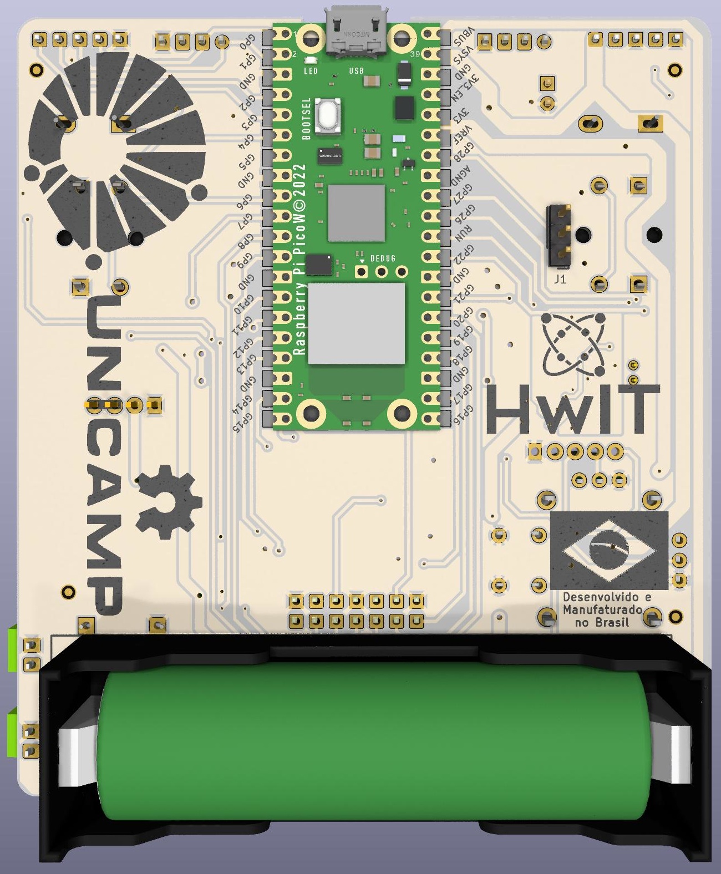
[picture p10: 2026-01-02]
docs/esquemático/Esquemático Final/bitdoglab_smd_bot.jpg

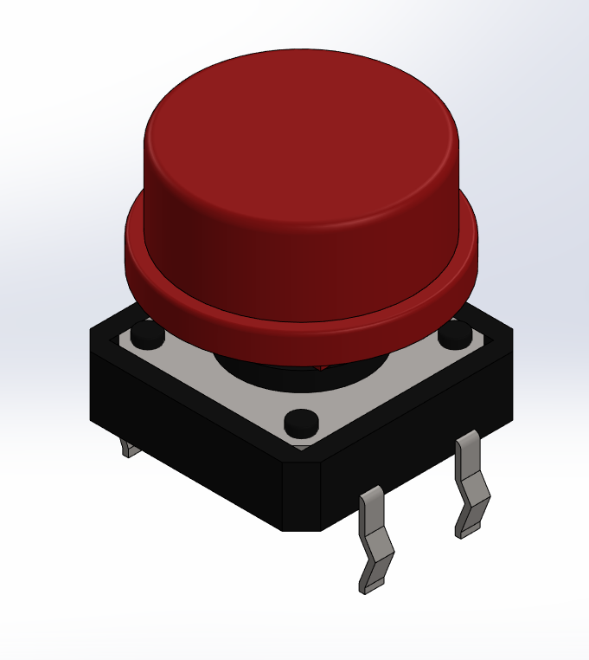
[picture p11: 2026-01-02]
docs/esquemático/Esquemático Final/3D/3D_1/Button with Cap Isometric.png

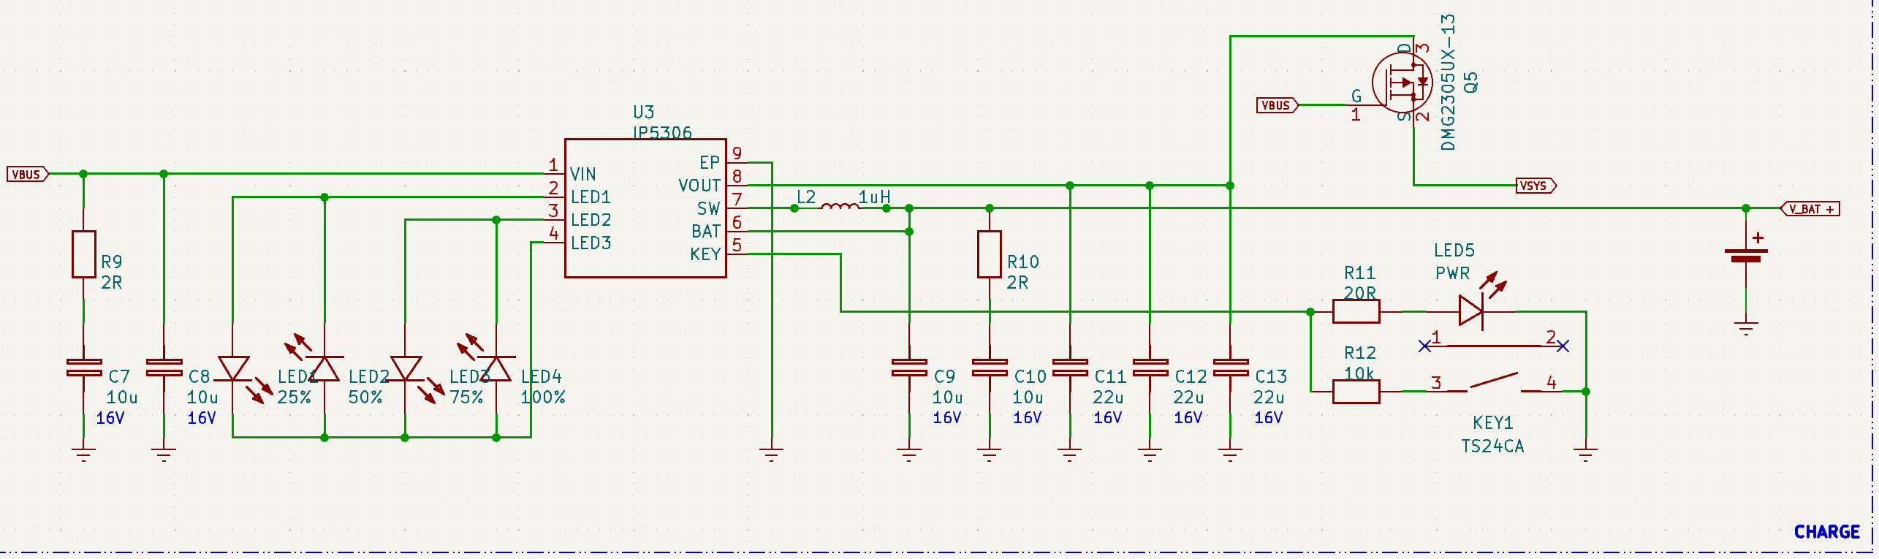
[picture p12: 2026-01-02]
docs/esquemático/Esquemático Final/3D/3D_1/Circuito charge1.png

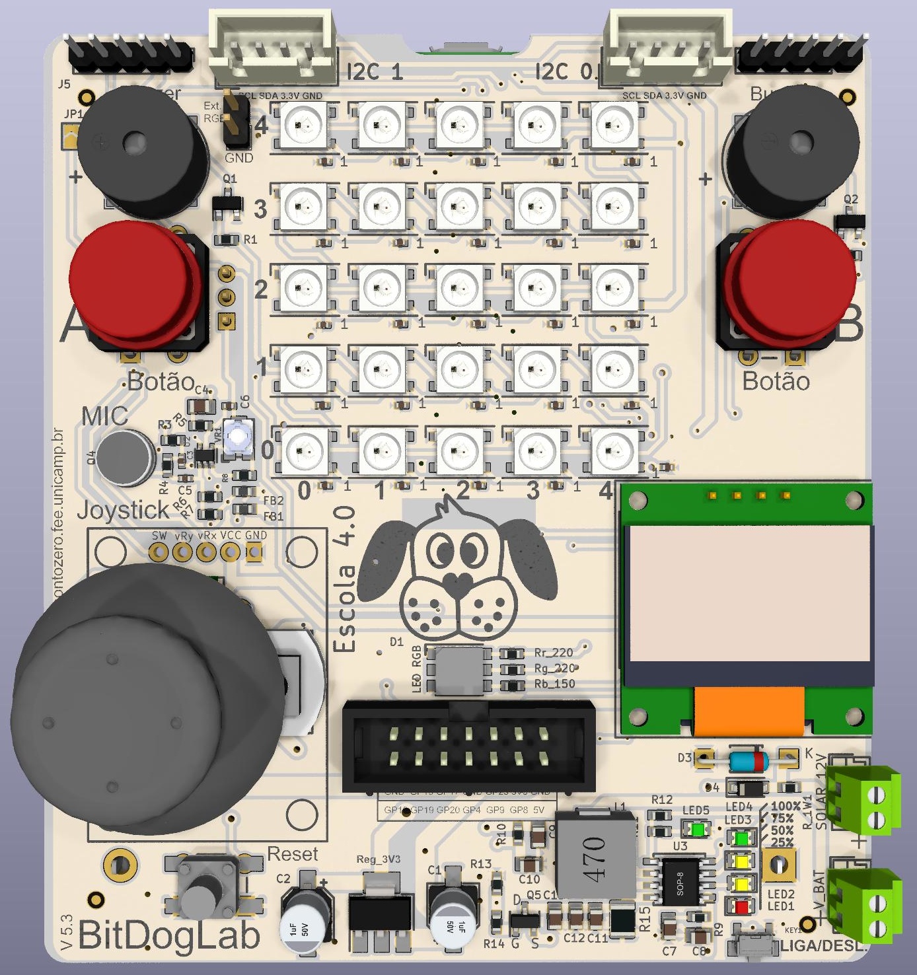
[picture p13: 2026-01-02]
docs/esquemático/Esquemático Final/bitdoglab_smd_top.jpg

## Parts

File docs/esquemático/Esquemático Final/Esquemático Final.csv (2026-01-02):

# | Reference | Qty | Value | Footprint | DNP
1 | A1 | 1 | SC0918 | Library_raspberry_pi:RPi_PicoW_SMD_TH
2 | BT1 | 1 | Battery_Cell | Battery:BatteryHolder_MPD_BH-18650-PC2
3 | BZ1 | 1 | Buzzer_A | Buzzer_Beeper:Buzzer_12x9.5RM7.6
4 | BZ2, BZ4 | 2 | Buzzer_B_SMD | Buzzer_Beeper:MagneticBuzzer_CUI_CMT-8504-100-SMT
5 | BZ3 | 1 | Buzzer_B | Buzzer_Beeper:Buzzer_12x9.5RM7.6
6 | C1, C2 | 2 | C_Polarized_Small | Capacitor_SMD:CP_Elec_5x5.9
7 | C3, C14, C15, C16, C17, C18, C19, C20, C21, C22, C23, C24, C25, C26, C27, C28, C29, C30, C31, C32, C33, C34, C35, C36, C37, C38 | 26 | 0.1µF | Capacitor_SMD:C_0402_1005Metric
8 | C4 | 1 | 10uF | Capacitor_SMD:C_0805_2012Metric
9 | C5 | 1 | 0.01uF | Capacitor_SMD:C_0402_1005Metric
10 | C6 | 1 | 100pF | Capacitor_SMD:C_0402_1005Metric
11 | C7, C8, C9, C10 | 4 | 10u | Resistor_SMD:R_0805_2012Metric
12 | C11, C12, C13 | 3 | 22u | Resistor_SMD:R_0805_2012Metric
13 | CARGA_SOLAR1 | 1 | SOLAR_12V | BITDOG_HWIT1:JST_EH_B2B-EH-A_1x02_P2.50mm_Vertical
14 | D1 | 1 | LED_RGB_SMD | LED_SMD:LED_RGB_5050-6
15 | D2, D5, D6, D7, D8, D9, D10, D11, D12, D13, D14, D15, D16, D17, D18, D19, D20, D21, D22, D23, D24, D25, D26, D27, D28 | 25 | WS2812B | LED_SMD:LED_WS2812B_PLCC4_5.0x5.0mm_P3.2mm
16 | D3 | 1 | 1N5231 | Diode_THT:D_T-1_P5.08mm_Horizontal
17 | D4 | 1 | D_Schottky | Diode_SMD:D_SOD-123
18 | FB1, FB2 | 2 | FERRITE | Inductor_SMD:L_0603_1608Metric
19 | FID1, FID2, FID3, FID4, FID5, FID6, FID7, FID8 | 8 | Fiducial | Fiducial:Fiducial_1mm_Mask2mm
20 | J1 | 1 | Conn_01x03 | Connector_PinHeader_2.54mm:PinHeader_1x03_P2.54mm_Vertical
21 | J2 | 1 | conector_idc | Connector_PinHeader_2.54mm:PinHeader_2x07_P2.54mm_Vertical
22 | J3 | 1 | Conn_01x02 | Connector_PinHeader_2.54mm:PinHeader_1x02_P2.54mm_Vertical
23 | J5, J12 | 2 | Conn_01x05_Pin | Connector_PinHeader_2.54mm:PinHeader_1x05_P2.54mm_Vertical
24 | J19 | 1 | JOYSTICK | user_ky-023-joystick-module-1.snapshot.4:ky-023
25 | J20, J21 | 2 | Conn_01x04_Pin | Connector_JST:JST_EH_B4B-EH-A_1x04_P2.50mm_Vertical
26 | JP1 | 1 | SolderJumper_2_Open | Jumper:SolderJumper-2_P1.3mm_Open_TrianglePad1.0x1.5mm
27 | KEY1 | 1 | TS24CA | Button_Switch_SMD:SW_SPST_CK_KMS2xxGP
28 | L1 | 1 | 1uH | Inductor_SMD:L_Bourns_SRP7028A_7.3x6.6mm
29 | LED1 | 1 | 25% | BITDOG_HWIT1:LED_0805_2012Metric
30 | LED2 | 1 | 50% | BITDOG_HWIT1:LED_0805_2012Metric
31 | LED3 | 1 | 75% | BITDOG_HWIT1:LED_0805_2012Metric
32 | LED4 | 1 | 100% | BITDOG_HWIT1:LED_0805_2012Metric
33 | LED5 | 1 | PWR | LED_SMD:LED_0805_2012Metric
34 | OLED1 | 1 | SSD1306 | user_SSD1306:128x64OLED
35 | Q1, Q2 | 2 | BC817 | Package_TO_SOT_SMD:SOT-23
36 | Q4 | 1 | CMA-4544PF-W | Buzzer_Beeper:Buzzer_12x9.5RM7.6
37 | Q5 | 1 | DMG2305UX-13 | Package_TO_SOT_SMD:SOT-23-3
38 | R1, R2 | 2 | 330 | Resistor_SMD:R_0603_1608Metric
39 | R3, R4, R5 | 3 | 1K | Resistor_SMD:R_0603_1608Metric
40 | R6, R7 | 2 | 1M | Resistor_SMD:R_0603_1608Metric
41 | R8 | 1 | 22K | Resistor_SMD:R_0603_1608Metric
42 | R9, R10 | 2 | 2R | Resistor_SMD:R_0603_1608Metric
43 | R11 | 1 | 20R | Resistor_SMD:R_0603_1608Metric
44 | R12, R13 | 2 | 10k | Resistor_SMD:R_0603_1608Metric
45 | R14 | 1 | 0R | Resistor_SMD:R_0603_1608Metric
46 | R15 | 1 | 100R | Resistor_SMD:R_1210_3225Metric
47 | R_1W1 | 1 | 100 | Resistor_SMD:R_0603_1608Metric
48 | Rb_150 | 1 | 150 | Resistor_SMD:R_0603_1608Metric
49 | Reg_3V3 | 1 | 3.3v_smd | Package_TO_SOT_SMD:SOT-223
50 | Rg_220, Rr_220 | 2 | 220 | Resistor_SMD:R_0603_1608Metric
51 | SW1 | 1 | Reset | Button_Switch_THT:SW_PUSH_6mm
52 | SW2 | 1 | Botão | BITDOG_HWIT1:SW_PUSH_6mm_b
53 | SW3 | 1 | Button_B | BITDOG_HWIT1:SW_PUSH_6mm_b
54 | SW4 | 1 | Reset | Button_Switch_SMD:SW_Push_1P1T_NO_6x6mm_H9.5mm
55 | U2 | 1 | MAX4466EXK+T | Package_TO_SOT_SMD:SOT-353_SC-70-5
56 | U3 | 1 | IP5306 | Package_SO:SOP-8_5.28x5.23mm_P1.27mm
57 | V_BAT1 | 1 | V_BAT | BITDOG_HWIT1:JST_EH_B2B-EH-A_1x02_P2.50mm_Vertical
58 | VR1 | 1 | TC33X-2-104E (100K) | Potentiometer_SMD:Potentiometer_Bourns_TC33X_Vertical

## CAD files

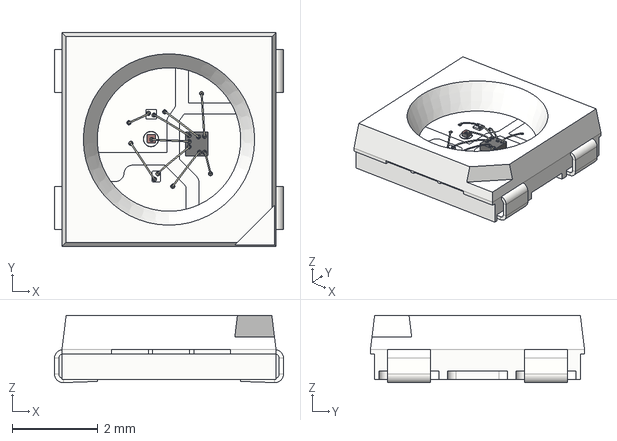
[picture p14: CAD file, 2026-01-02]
docs/esquemático/Esquemático Final/3D/3D_1/WS2812B.step
5.35 x 5.00 x 1.57 mm

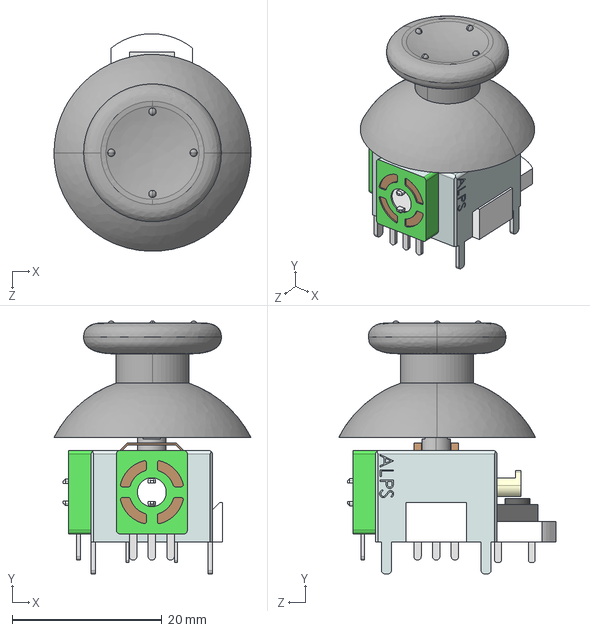
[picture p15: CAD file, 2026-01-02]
docs/esquemático/Esquemático Final/3D/ALPS JOYSTICK.STEP
26.3 x 33.8 x 29.0 mm
User Library-Joystick_Asm_Left_Joystick_b
User Library-alps joystick module

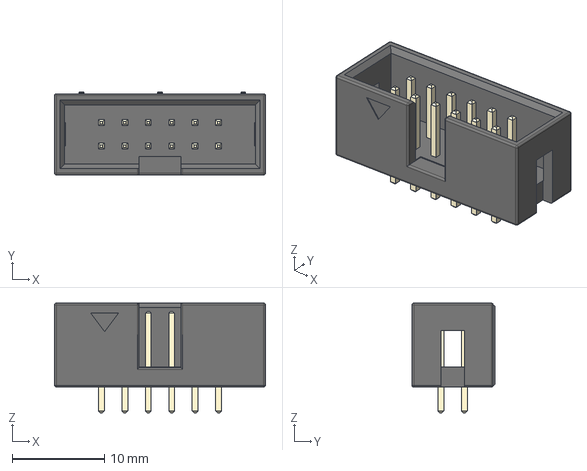
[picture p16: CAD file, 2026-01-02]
docs/esquemático/Esquemático Final/3D/3D_1/2x6 shrouded header v2.step
22.8 x 9.00 x 11.9 mm
Pins

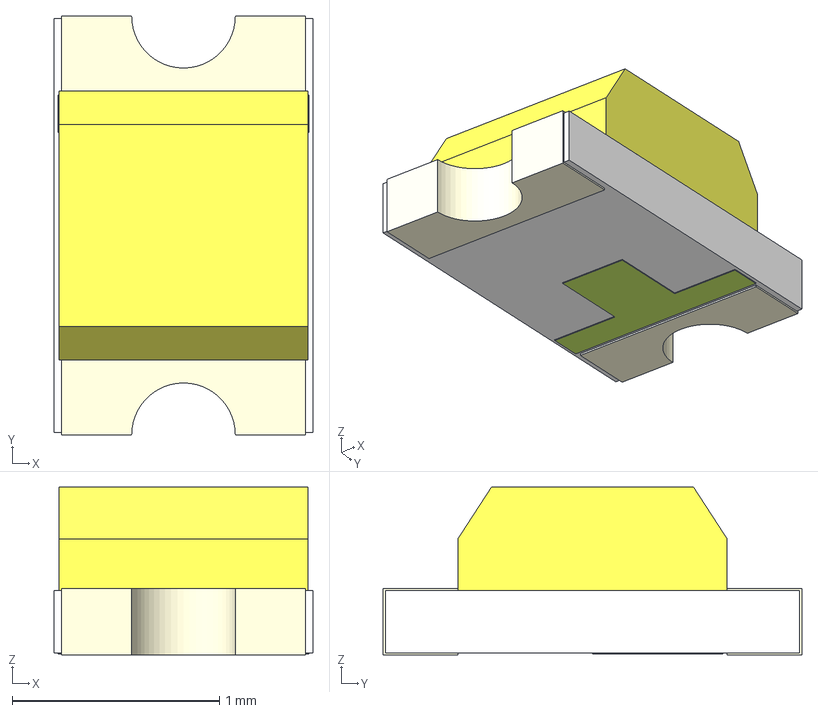
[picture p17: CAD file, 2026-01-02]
docs/esquemático/Esquemático Final/3D/LED-0805-Yellow.step
1.25 x 2.02 x 0.81 mm
Pads
Glass
Marks
Chip

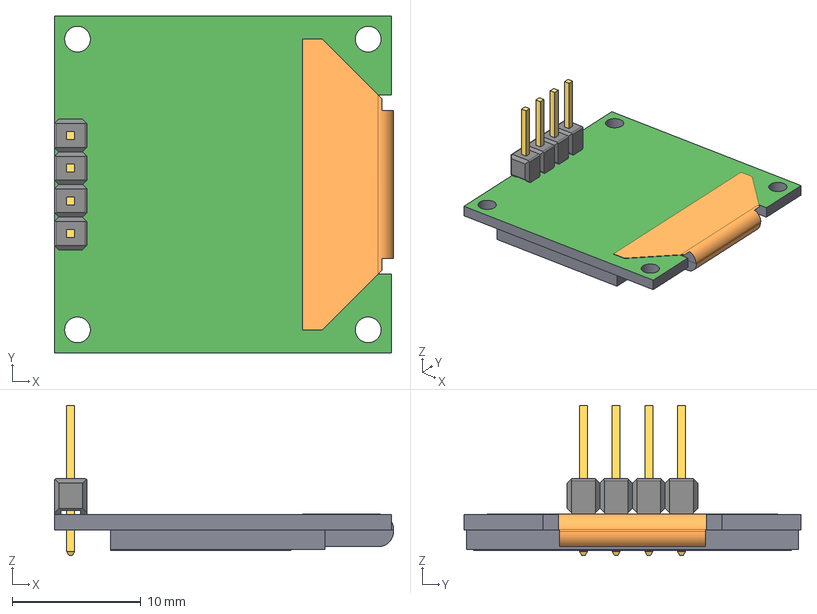
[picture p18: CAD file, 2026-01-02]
docs/esquemático/Esquemático Final/3D/3D_1/OLED TEMU 0.96 in.stp
26.4 x 26.2 x 11.7 mm
brep_2 x 4

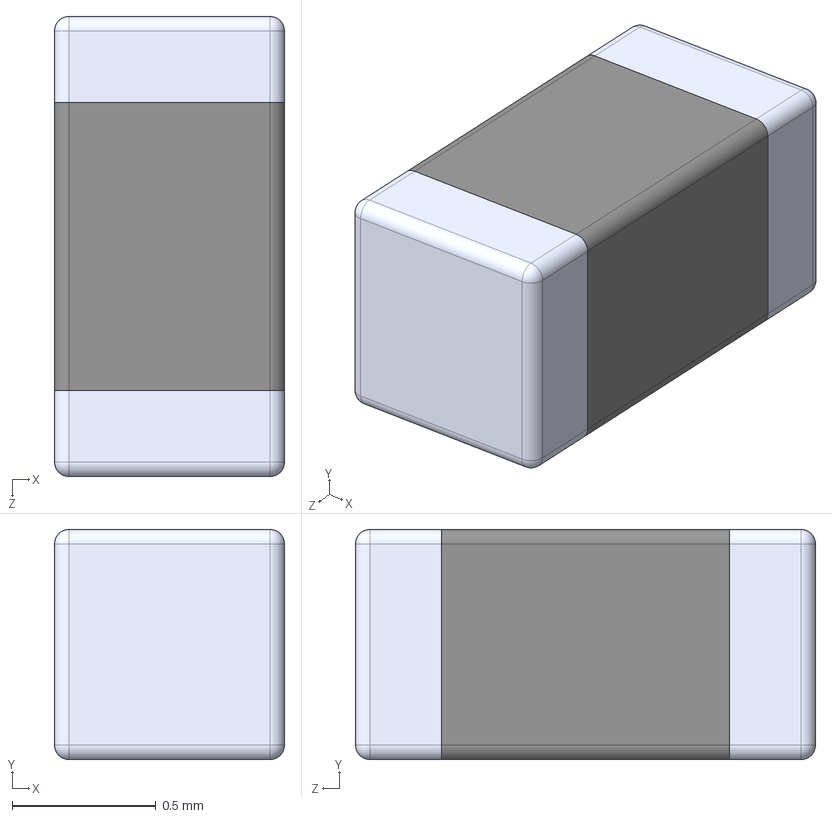
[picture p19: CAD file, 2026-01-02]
docs/esquemático/Esquemático Final/3D/ferrite_bead_0603.STEP
0.8 x 0.8 x 1.60 mm

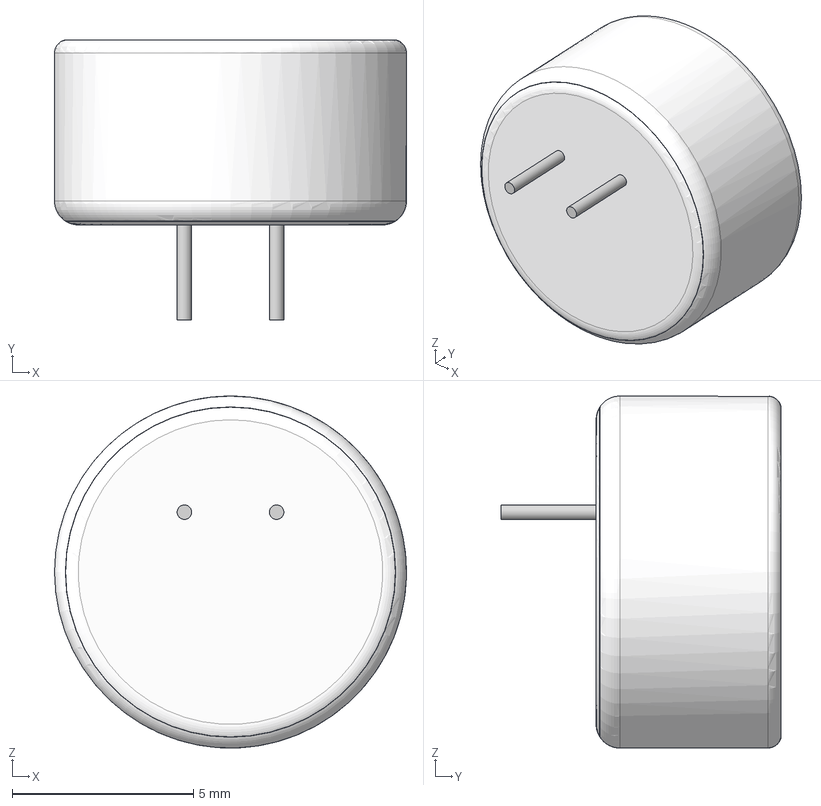
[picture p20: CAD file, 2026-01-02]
docs/esquemático/Esquemático Final/3D/electret mic 9.6x5x2.54 v5.step
9.70 x 7.73 x 9.70 mm

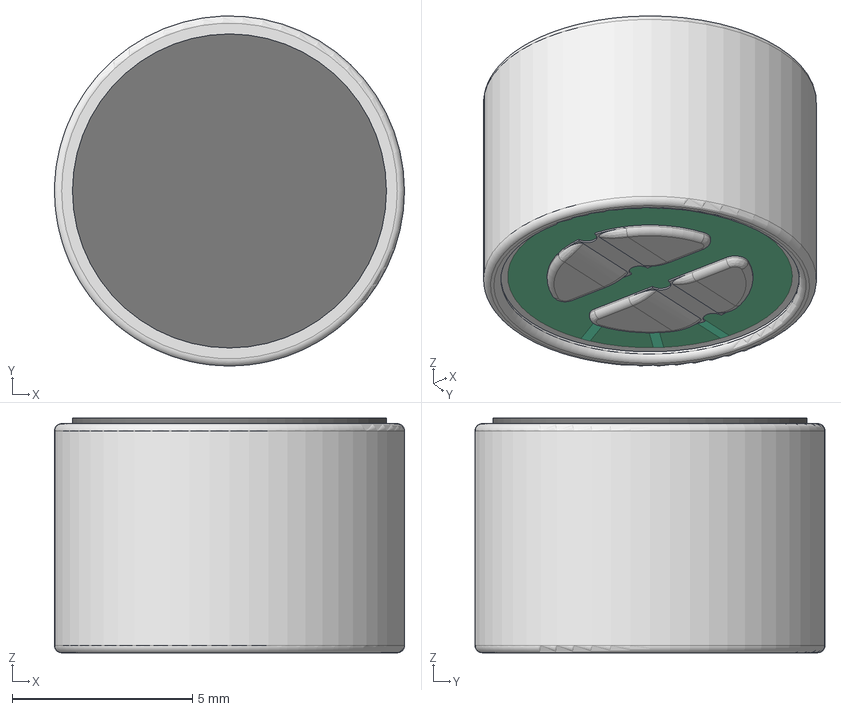
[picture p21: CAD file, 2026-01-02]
docs/esquemático/Esquemático Final/3D/3D_1/MIC_ELECTRET-D9,7MM-H6.5MM.stp
9.70 x 9.70 x 6.50 mm

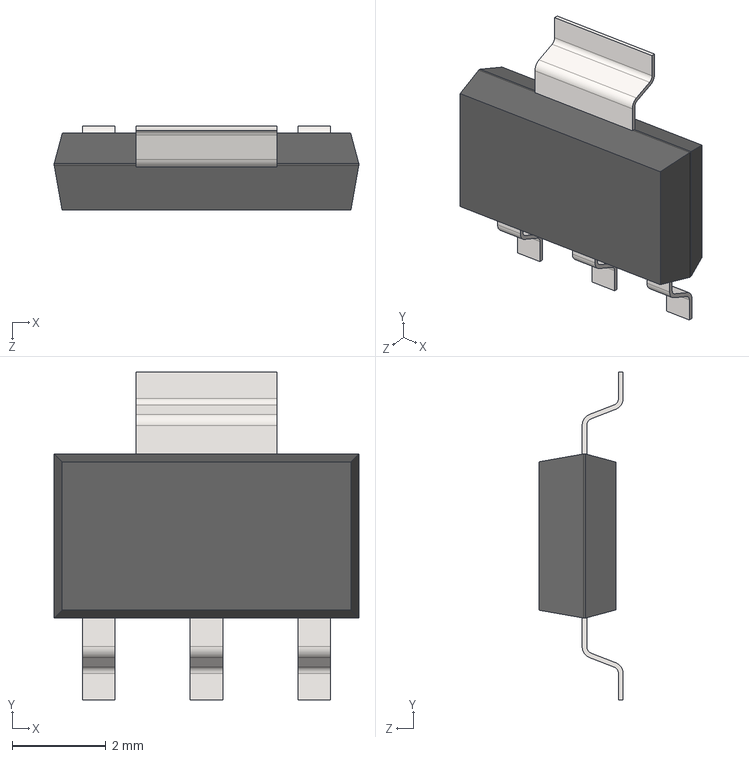
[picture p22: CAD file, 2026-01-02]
docs/esquemático/Esquemático Final/3D/3D_1/SOT-223.STEP
6.50 x 7.00 x 1.80 mm

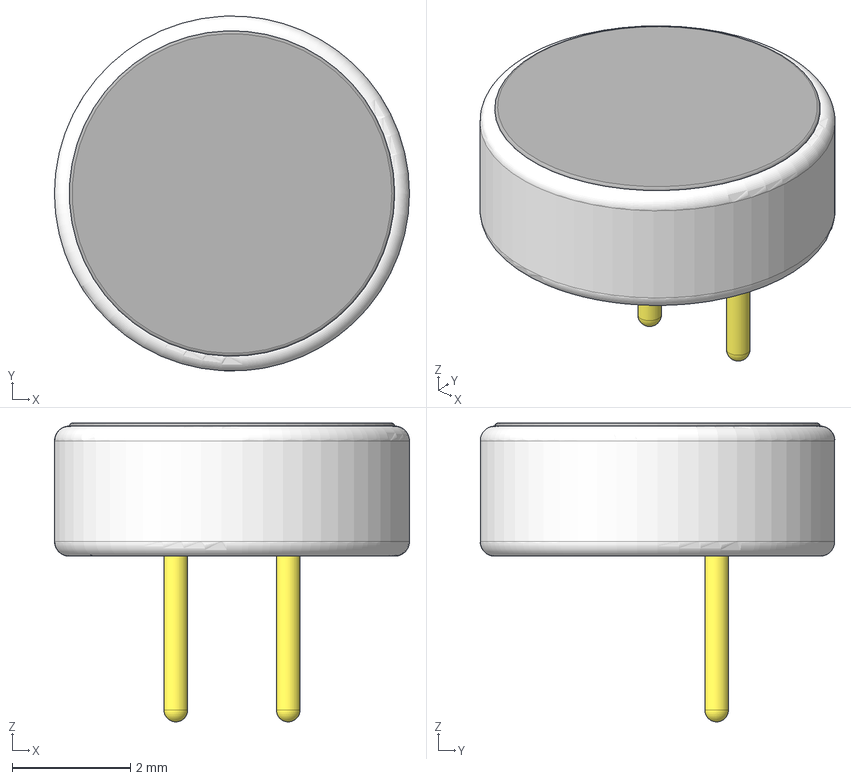
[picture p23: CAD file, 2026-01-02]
docs/esquemático/Esquemático Final/3D/Microphone_D6_H2.2.step
6.00 x 5.99 x 5.05 mm
PIn001
PIn002
Foam
PCB

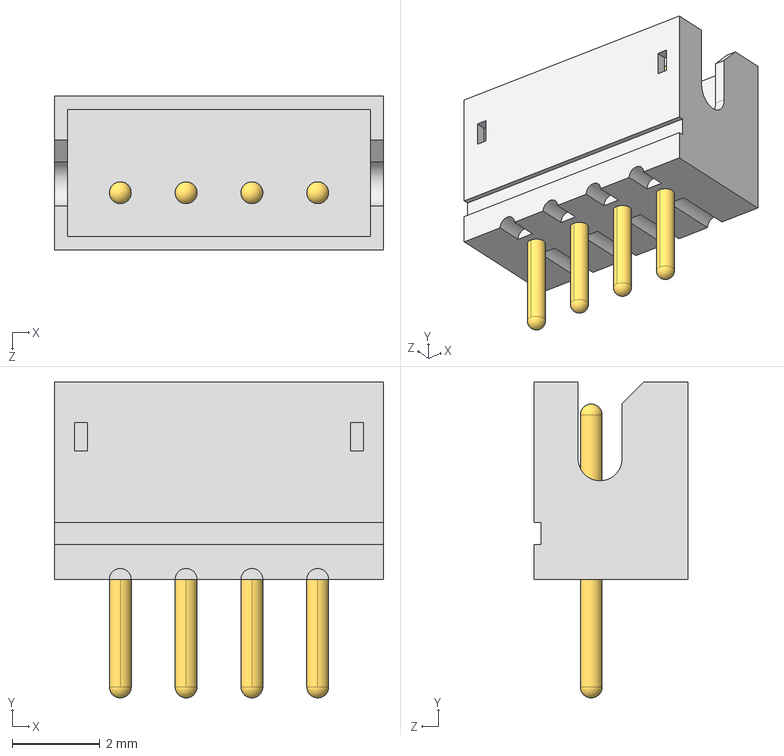
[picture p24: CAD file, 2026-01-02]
docs/esquemático/Esquemático Final/3D/3D_1/jst-1.5mm-4P.STEP
7.50 x 7.20 x 3.50 mm

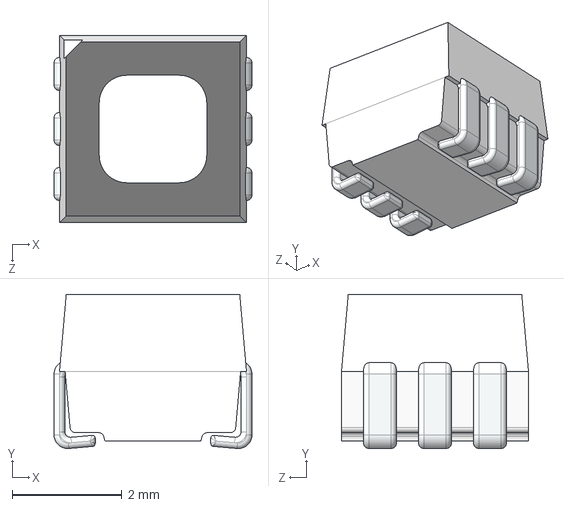
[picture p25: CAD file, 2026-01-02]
docs/esquemático/Esquemático Final/3D/Led, RGB, SMD-Square, CLX6A.STEP
3.60 x 2.80 x 3.40 mm

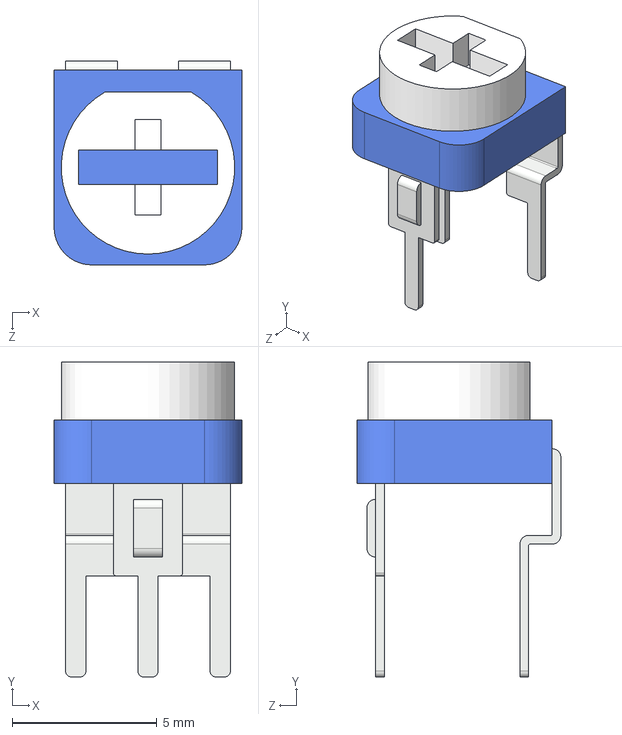
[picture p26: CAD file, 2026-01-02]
docs/esquemático/Esquemático Final/3D/3D_1/Pot - RES_VAR1.STEP
6.50 x 10.9 x 7.05 mm

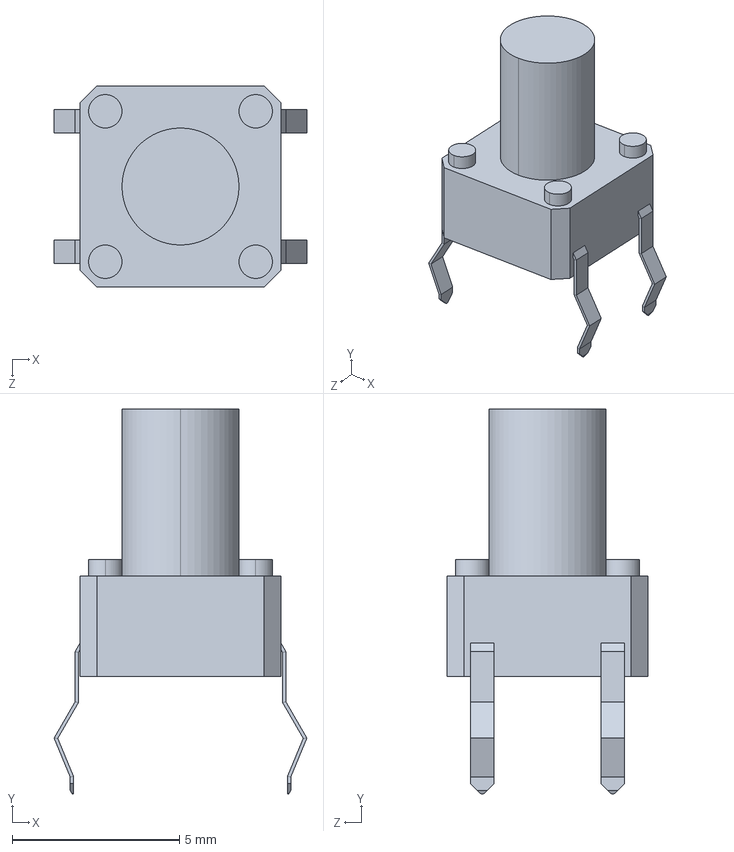
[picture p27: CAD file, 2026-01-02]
docs/esquemático/Esquemático Final/3D/6x6 8mm Tach Buton (4 arm).STEP
7.57 x 11.5 x 6.01 mm

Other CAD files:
docs/esquemático/Esquemático Final/3D/3D_1/LED-0805-Green.step
docs/esquemático/Esquemático Final/3D/LED SMD 5050 RGB1.stp
docs/esquemático/Esquemático Final/3D/3D_1/SMT-microinterruptor moment neo.SLDPRT
docs/esquemático/Esquemático Final/3D/DS1021_blue_2x01p_100mil_Type5_rev1.0.STEP
docs/esquemático/Esquemático Final/3D/0603 Chip SMD LED (1.6x0.8mm).STEP
docs/esquemático/Esquemático Final/3D/12mm Push Button with Cap.STEP
docs/esquemático/Esquemático Final/3D/18650 Battery and Holder 02 v2.step
docs/esquemático/Esquemático Final/3D/3D_1/0603 Chip SMD LED (1.6x0.8mm) - Copia.STEP
docs/esquemático/Esquemático Final/3D/3D_1/0603 Chip SMD LED (1.6x0.8mm).STEP
docs/esquemático/Esquemático Final/3D/3D_1/9x12 Buzzer.step
docs/esquemático/Esquemático Final/3D/3D_1/AB2_HDR_M07-2V-S-TE_WINGS3D.stl
docs/esquemático/Esquemático Final/3D/3D_1/ALU_CAP_1uF_50V.STEP
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

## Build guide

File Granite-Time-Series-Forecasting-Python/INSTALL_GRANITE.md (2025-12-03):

# 🔮 Instalação do IBM Granite TTM-R2

Guia para instalar o modelo **IBM Granite Time Series TTM-R2** no projeto.

## ⚠️ Importante

O modelo Granite TTM-R2 **não está disponível no PyPI** e deve ser instalado diretamente do GitHub.

## 🚀 Instalação Rápida

### Opção 1: Script Automático (Recomendado)

```bash
# 1. Criar e ativar ambiente virtual
python3.7 -m venv venv
source venv/bin/activate

# 2. Instalar dependências base
pip install -r requirements.txt

# 3. Executar script de instalação do Granite
bash install_granite.sh
```

### Opção 2: Instalação Manual

```bash
# 1. Ativar ambiente virtual
source venv/bin/activate

# 2. Instalar PyTorch
pip install torch==1.13.1 --index-url https://download.pytorch.org/whl/cpu

# 3. Instalar transformers
pip install transformers==4.30.0

# 4. Tentar instalar do repositório oficial IBM
pip install git+https://github.com/ibm-granite/granite-tsfm.git@main

# OU do repositório alternativo
pip install git+https://github.com/IBM/tsfm.git
```

## 🔍 Verificar Instalação

```bash
python3.7 -c "
from tsfm_public import TimeSeriesForecastingPipeline, TinyTimeMixerForPrediction
print('✅ Granite TTM-R2 instalado com sucesso!')
"
```

## 📊 Funcionamento do Sistema

O sistema foi projetado para funcionar em **dois modos**:

### Modo 1: Com Granite TTM-R2 (Preferencial)

Se o Granite estiver instalado:
- ✅ Usa o modelo IBM Granite TTM-R2 para previsões
- ✅ Suporte GPU/CPU automático
- ✅ Zero-shot forecasting de alta qualidade
- ✅ Horizonte de 96 pontos futuros

### Modo 2: Fallback (Exponential Smoothing)

Se o Granite **não** estiver disponível:
- ✅ Sistema continua funcionando normalmente
- ✅ Usa Holt-Winters (Triple Exponential Smoothing)
- ✅ Captura tendência e sazonalidade
- ✅ Previsões de boa qualidade

## 🐛 Problemas Comuns

### Erro: "No module named 'tsfm_public'"

**Solução**: Execute o script de instalação:
```bash
bash install_granite.sh
```

### Erro: "Could not find a version that satisfies..."

**Causa**: Python 3.7 tem limitações de compatibilidade.

**Solução**: Verifique se está usando as versões corretas:
```bash
pip install torch==1.13.1
pip install transformers==4.30.0
```

### Erro ao instalar do GitHub

**Causa**: Repositório pode não estar acessível ou ter mudado.

**Solução**: O sistema funcionará automaticamente em modo fallback.

## 📝 Logs do Sistema

O sistema exibe mensagens claras sobre qual modelo está sendo usado:

```
✅ [ForecastService] IBM Granite TTM-R2 disponivel
🔮 [ForecastService] Using IBM Granite TTM-R2 on cpu
```

Ou em modo fallback:

```
⚠️  [ForecastService] IBM Granite TTM-R2 nao disponivel - usando modelo alternativo
💡 [ForecastService] Execute: bash install_granite.sh
🔮 [ForecastService] Using Exponential Smoothing (fallback)
```

## 🎯 Requisitos Mínimos

- **Python**: 3.7+
- **RAM**: 4GB mínimo (8GB recomendado para Granite)
- **Disco**: ~2GB para modelo e dependências
- **Internet**: Necessário para download inicial do modelo

## 🔗 Referências

- [IBM Granite Models](https://github.com/ibm-granite)
- [Granite Time Series Forecasting](https://huggingface.co/ibm-granite/granite-timeseries-ttm-r2)
- [Paper: Tiny Time Mixers](https://arxiv.org/abs/2401.03955)

## ✅ Próximos Passos

Após instalar:

1. Execute o sistema: `python app.py`
2. Acesse: http://localhost:5000
3. Clique em "▶️ Iniciar"
4. Observe os logs para confirmar qual modelo está sendo usado

---

**💡 Dica**: O sistema funciona perfeitamente mesmo sem o Granite instalado!

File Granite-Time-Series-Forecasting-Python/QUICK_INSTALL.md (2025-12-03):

# ⚡ Instalação Rápida - Python 3.12

## 🚀 Passos Rápidos

```bash
# 1. Limpar ambiente anterior (se existir)
rm -rf venv

# 2. Executar script de instalação
bash run.sh
```

O script `run.sh` irá automaticamente:
- ✅ Criar ambiente virtual
- ✅ Instalar todas as dependências
- ✅ Iniciar o servidor

## 🔮 Instalar IBM Granite TTM-R2 (Opcional mas Recomendado)

Após o sistema estar rodando, em outro terminal:

```bash
# Ativar ambiente virtual
source venv/bin/activate

# Instalar Granite
bash install_granite.sh

# Reiniciar o servidor
# (Ctrl+C no terminal anterior e executar novamente)
python app.py
```

## 📊 Verificar Instalação

O sistema mostrará nos logs qual modelo está usando:

**Com Granite:**
```
✅ [ForecastService] IBM Granite TTM-R2 disponivel
🔮 [ForecastService] Using IBM Granite TTM-R2 on cpu
```

**Sem Granite (Fallback):**
```
⚠️  [ForecastService] IBM Granite TTM-R2 nao disponivel
🔮 [ForecastService] Using Exponential Smoothing (fallback)
```

## 🌐 Acessar Interface

Abra seu navegador em: **http://localhost:5000**

## ⚙️ Requisitos

- **Python 3.12** ✅
- **pip** atualizado
- **4GB RAM** mínimo
- **Conexão com internet** (primeira execução)

## 🐛 Problemas?

### Erro de permissão no script
```bash
chmod +x run.sh install_granite.sh
```

### Porta 5000 em uso
Edite `.env` e mude:
```
PORT=8080
```

### Dependências não instalam
```bash
pip install --upgrade pip setuptools wheel
bash run.sh
```

---

**💡 Dica**: O sistema funciona perfeitamente mesmo sem o Granite instalado!

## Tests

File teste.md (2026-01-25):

# Análise RTOS (WCET / Stack / Heap)
Gerado em: `2025-12-25T14:00:03.760732-03:00`
## Parâmetros
- **board**: `None`
- **mcuCode**: `rp2040`
- **projectDir**: `firmware`
- **elf**: `firmware/build/rack_inteligente.elf`

## Heap
- **heap_free**
  - count: `0`
  - min: `None`
  - max: `None`
  - mean: `0.0`
- **heap_min**
  - count: `0`
  - min: `None`
  - max: `None`
  - mean: `0.0`

## Tasks

## Escalonamento / CPU (janela)
Sem dados suficientes de TraceKV para estimar CPU por janela.

### Segmentos de escalonamento (resumo)
| Task | Segments | TotalRunTime(s) | MeanSegment(s) | MaxSegment(s) |
|---|---:|---:|---:|---:|

## ELF/MAP (resumo)
- `map_path`: `firmware/build/rack_inteligente.elf.map`
- `section_bss_bytes`: `218964`
- `section_data_bytes`: `72`
- `section_text_bytes`: `4`

## ELF (maiores símbolos por tamanho)
| Símbolo | Bytes |
|---|---:|
| `w43439A0_7_95_49_00_combined` | `225240` |
| `ucHeap` | `104504` |
| `memp_memory_PBUF_POOL_base` | `49027` |
| `ram_heap` | `24019` |
| `gLines` | `8960` |
| `gLines` | `8960` |
| `vApplicationGetTimerTaskMemory::uxTimerTaskStack` | `4096` |
| `memp_memory_TCP_PCB_base` | `3283` |
| `tcp_receive` | `2504` |
| `cyw43_state` | `2464` |
| `core1_stack` | `2048` |
| `_vsnprintf` | `1700` |
| `tcp_input` | `1632` |
| `main` | `1620` |
| `_malloc_r` | `1484` |
| `tcp_process` | `1376` |
| `cyw43_spi_transfer` | `1324` |
| `tcp_slowtmr` | `1100` |
| `dns_table` | `1088` |
| `_etoa` | `1058` |
| `__malloc_av_` | `1032` |
| `vApplicationGetIdleTaskMemory::uxIdleTaskStack` | `1024` |
| `statsBuffer.0` | `1024` |
| `ssd_buffer` | `1024` |
| `hw_endpoints` | `1024` |
| `memp_memory_TCP_SEG_base` | `963` |
| `mqtt_client_connect` | `916` |
| `process_control_request` | `900` |
| `cyw43_ll_bus_init` | `880` |
| `tcp_write` | `852` |

## Complexidade Ciclomática (McCabe) - análise offline
A complexidade é calculada a partir do assembly (contagem de branches condicionais por função).

- Clock do MCU: `125 MHz`
- Funções analisadas: `1290`
- Tasks identificadas: `69`
- Profundidade máxima do callgraph: `38`
- McCabe médio: `4.51`
- McCabe máximo: `108`

| Função | McCabe | Decisões | Instruções | Ciclos Est. | WCET Est. (μs) | Task |
|---|---:|---:|---:|---:|---:|:---:|
| `tcp_receive` | `108` | `107` | `1121` | `2292` | `18.34` |  |
| `tcp_input` | `72` | `71` | `684` | `1441` | `11.53` |  |
| `tcp_process` | `67` | `66` | `610` | `1298` | `10.38` |  |
| `_vsnprintf` | `65` | `64` | `829` | `1550` | `12.40` |  |
| `_malloc_r` | `62` | `61` | `713` | `1311` | `10.49` |  |
| `tcp_slowtmr` | `62` | `61` | `483` | `1027` | `8.22` |  |
| `dhcp_parse_reply` | `42` | `41` | `349` | `708` | `5.66` |  |
| `tcp_write` | `40` | `39` | `381` | `738` | `5.90` |  |
| `tcp_output` | `40` | `39` | `361` | `729` | `5.83` |  |
| `process_control_request` | `39` | `38` | `399` | `874` | `6.99` |  |
| `_ftoa` | `37` | `36` | `369` | `779` | `6.23` |  |
| `mqtt_message_received` | `37` | `36` | `298` | `618` | `4.94` |  |
| `ip4_input` | `31` | `30` | `301` | `618` | `4.94` |  |
| `_ntoa_format` | `31` | `30` | `134` | `265` | `2.12` |  |
| `mqtt_client_connect` | `29` | `28` | `385` | `814` | `6.51` |  |
| `alarm_pool_irq_handler` | `29` | `28` | `347` | `664` | `5.31` |  |
| `ip_reass_chain_frag_into_datagram_and_validate` | `29` | `28` | `302` | `574` | `4.59` |  |
| `ip4_reass` | `28` | `27` | `289` | `594` | `4.75` |  |
| `udp_input` | `27` | `26` | `232` | `472` | `3.78` |  |
| `dns_recv` | `26` | `25` | `243` | `522` | `4.18` |  |
| `etharp_find_entry` | `26` | `25` | `200` | `383` | `3.06` |  |
| `cyw43_cb_process_async_event` | `26` | `25` | `195` | `423` | `3.38` |  |
| `ip4addr_aton` | `26` | `25` | `164` | `333` | `2.66` |  |
| `_etoa` | `25` | `24` | `438` | `918` | `7.34` |  |
| `handle_name_menu_keys` | `25` | `24` | `222` | `483` | `3.86` |  |
| `i2c_write_blocking_internal` | `25` | `24` | `172` | `335` | `2.68` |  |
| `handle_password_menu_keys` | `24` | `23` | `203` | `442` | `3.54` |  |
| `etharp_query` | `24` | `23` | `202` | `407` | `3.26` |  |
| `pvPortMalloc` | `24` | `23` | `162` | `350` | `2.80` |  |
| `xQueueGenericSend` | `24` | `23` | `152` | `372` | `2.98` |  |
| `pbuf_copy_partial_pbuf` | `22` | `21` | `135` | `277` | `2.22` |  |
| `dhcp_recv` | `22` | `21` | `107` | `230` | `1.84` |  |
| `cyw43_spi_transfer` | `21` | `20` | `597` | `1133` | `9.06` |  |
| `cyw43_ll_bus_init` | `21` | `20` | `328` | `774` | `6.19` |  |
| `_free_r` | `21` | `20` | `235` | `430` | `3.44` |  |
| `best_effort_wfe_or_timeout` | `21` | `20` | `133` | `280` | `2.24` |  |
| `dcd_rp2040_irq` | `20` | `19` | `227` | `459` | `3.67` |  |
| `cdcd_control_xfer_cb` | `20` | `19` | `144` | `308` | `2.46` |  |
| `cdcd_xfer_cb` | `20` | `19` | `141` | `299` | `2.39` |  |
| `cyw43_ll_wifi_join` | `19` | `18` | `334` | `667` | `5.34` |  |
| `sdpcm_process_rx_packet` | `19` | `18` | `164` | `329` | `2.63` |  |
| `xQueueSemaphoreTake` | `19` | `18` | `150` | `377` | `3.02` |  |
| `xQueueGenericSendFromISR` | `19` | `18` | `130` | `282` | `2.26` |  |
| `tcp_close_shutdown` | `19` | `18` | `129` | `297` | `2.38` |  |
| `cyw43_ll_wifi_ap_init` | `18` | `17` | `289` | `589` | `4.71` |  |
| `icmp_input` | `18` | `17` | `224` | `459` | `3.67` |  |
| `dns_enqueue` | `18` | `17` | `182` | `347` | `2.78` |  |
| `cyw43_ll_sdpcm_poll_device` | `18` | `17` | `146` | `317` | `2.54` |  |
| `mem_malloc` | `18` | `17` | `125` | `264` | `2.11` |  |
| `tcp_enqueue_flags` | `17` | `16` | `131` | `276` | `2.21` |  |

### Tasks Identificadas
- **buzzerPwmTask**: McCabe=`5`, WCET=`1.66 μs`, Chama 9 funções
- **commandProcessingTask**: McCabe=`7`, WCET=`1.69 μs`, Chama 12 funções
- **eTaskGetState**: McCabe=`12`, WCET=`1.28 μs`, Chama 3 funções
- **keyboard_task**: McCabe=`3`, WCET=`0.53 μs`, Chama 6 funções
- **pcTaskGetName**: McCabe=`3`, WCET=`0.26 μs`, Chama 1 funções
- **prvAddCurrentTaskToDelayedList**: McCabe=`5`, WCET=`1.03 μs`, Chama 2 funções
- **prvAddNewTaskToReadyList**: McCabe=`8`, WCET=`1.34 μs`, Chama 4 funções
- **prvCheckTasksWaitingTermination**: McCabe=`2`, WCET=`0.45 μs`, Chama 4 funções
- **prvCreateIdleTasks**: McCabe=`2`, WCET=`0.50 μs`, Chama 2 funções
- **prvIdleTask**: McCabe=`2`, WCET=`0.18 μs`, Chama 2 funções
- **prvInitialiseNewTask**: McCabe=`6`, WCET=`1.18 μs`, Chama 4 funções
- **prvInitialiseTaskLists**: McCabe=`2`, WCET=`0.57 μs`, Chama 1 funções
- **prvListTasksWithinSingleList**: McCabe=`5`, WCET=`0.82 μs`, Chama 1 funções
- **prvProcessTimerOrBlockTask**: McCabe=`6`, WCET=`0.86 μs`, Chama 6 funções
- **prvResetNextTaskUnblockTime**: McCabe=`2`, WCET=`0.29 μs`, Chama 0 funções
- **prvTaskCheckFreeStackSpace**: McCabe=`2`, WCET=`0.14 μs`, Chama 0 funções
- **prvTaskExitError**: McCabe=`1`, WCET=`0.06 μs`, Chama 1 funções
- **prvTimerTask**: McCabe=`1`, WCET=`0.18 μs`, Chama 3 funções
- **pvTaskIncrementMutexHeldCount**: McCabe=`2`, WCET=`0.13 μs`, Chama 0 funções
- **sanitizeTaskName**: McCabe=`7`, WCET=`0.63 μs`, Chama 0 funções
- **timer_task**: McCabe=`3`, WCET=`0.66 μs`, Chama 3 funções
- **tud_task_ext**: McCabe=`15`, WCET=`3.30 μs`, Chama 12 funções
- **ulTaskGenericNotifyTake**: McCabe=`6`, WCET=`1.24 μs`, Chama 6 funções
- **uxTaskGetNumberOfTasks**: McCabe=`1`, WCET=`0.06 μs`, Chama 0 funções
- **uxTaskGetSystemState**: McCabe=`4`, WCET=`1.06 μs`, Chama 4 funções
- **uxTaskResetEventItemValue**: McCabe=`1`, WCET=`0.16 μs`, Chama 0 funções
- **vApplicationGetIdleTaskMemory**: McCabe=`1`, WCET=`0.14 μs`, Chama 0 funções
- **vApplicationGetTimerTaskMemory**: McCabe=`1`, WCET=`0.14 μs`, Chama 0 funções
- **vDoorStateMqttTask**: McCabe=`1`, WCET=`1.18 μs`, Chama 7 funções
- **vGpsMqttTask**: McCabe=`2`, WCET=`1.72 μs`, Chama 7 funções
- **vGpsTask**: McCabe=`1`, WCET=`1.25 μs`, Chama 7 funções
- **vHumidityMqttTask**: McCabe=`1`, WCET=`0.89 μs`, Chama 5 funções
- **vMenuOledTask**: McCabe=`16`, WCET=`2.65 μs`, Chama 7 funções
- **vNetworkPollTask**: McCabe=`4`, WCET=`1.25 μs`, Chama 9 funções
- **vOledStatusTask**: McCabe=`1`, WCET=`0.38 μs`, Chama 4 funções
- **vPortStartFirstTask**: McCabe=`1`, WCET=`0.30 μs`, Chama 0 funções
- **vRTOSMonitorTask**: McCabe=`3`, WCET=`1.82 μs`, Chama 13 funções
- **vTaskDelay**: McCabe=`4`, WCET=`0.52 μs`, Chama 6 funções
- **vTaskGetInfo**: McCabe=`8`, WCET=`1.26 μs`, Chama 6 funções
- **vTaskGetRunTimeStats**: McCabe=`5`, WCET=`1.18 μs`, Chama 7 funções
- **vTaskInternalSetTimeOutState**: McCabe=`1`, WCET=`0.13 μs`, Chama 0 funções
- **vTaskMissedYield**: McCabe=`1`, WCET=`0.07 μs`, Chama 0 funções
- **vTaskPlaceOnEventList**: McCabe=`2`, WCET=`0.33 μs`, Chama 3 funções
- **vTaskPlaceOnEventListRestricted**: McCabe=`3`, WCET=`0.58 μs`, Chama 2 funções
- **vTaskPlaceOnUnorderedEventList**: McCabe=`3`, WCET=`0.75 μs`, Chama 2 funções
- **vTaskPriorityDisinheritAfterTimeout**: McCabe=`10`, WCET=`1.27 μs`, Chama 2 funções
- **vTaskRemoveFromUnorderedEventList**: McCabe=`7`, WCET=`1.54 μs`, Chama 1 funções
- **vTaskStartScheduler**: McCabe=`4`, WCET=`0.70 μs`, Chama 6 funções
- **vTaskSuspendAll**: McCabe=`1`, WCET=`0.09 μs`, Chama 0 funções
- **vTaskSwitchContext**: McCabe=`10`, WCET=`1.95 μs`, Chama 6 funções
- **vTemperatureHumidityTask**: McCabe=`3`, WCET=`2.40 μs`, Chama 12 funções
- **vTemperatureMqttTask**: McCabe=`1`, WCET=`0.94 μs`, Chama 6 funções
- **vTiltMqttTask**: McCabe=`2`, WCET=`1.02 μs`, Chama 5 funções
- **vTiltTask**: McCabe=`2`, WCET=`1.05 μs`, Chama 9 funções
- **watchdogSupervisorTask**: McCabe=`3`, WCET=`0.81 μs`, Chama 7 funções
- **watchdogTaskInit**: McCabe=`4`, WCET=`0.83 μs`, Chama 3 funções
- **xTaskCheckForTimeOut**: McCabe=`8`, WCET=`1.18 μs`, Chama 4 funções
- **xTaskCreate**: McCabe=`3`, WCET=`0.79 μs`, Chama 5 funções
- **xTaskCreateStatic**: McCabe=`4`, WCET=`1.10 μs`, Chama 4 funções
- **xTaskGetCurrentTaskHandle**: McCabe=`1`, WCET=`0.06 μs`, Chama 0 funções
- **xTaskGetSchedulerState**: McCabe=`3`, WCET=`0.25 μs`, Chama 0 funções
- **xTaskGetTickCount**: McCabe=`1`, WCET=`0.06 μs`, Chama 0 funções
- **xTaskIncrementTick**: McCabe=`14`, WCET=`2.52 μs`, Chama 2 funções
- **xTaskPriorityDisinherit**: McCabe=`7`, WCET=`1.20 μs`, Chama 2 funções
- **xTaskPriorityInherit**: McCabe=`7`, WCET=`1.30 μs`, Chama 1 funções
- **xTaskRemoveFromEventList**: McCabe=`7`, WCET=`1.68 μs`, Chama 1 funções
- **xTaskResumeAll**: McCabe=`14`, WCET=`2.38 μs`, Chama 6 funções
- **xTimerCreateTimerTask**: McCabe=`3`, WCET=`0.68 μs`, Chama 4 funções
- **xTimerGenericCommandFromTask**: McCabe=`5`, WCET=`0.80 μs`, Chama 3 funções

### Callgraph (amostra de arestas)
- `hold_non_core0_in_bootrom` → `data_cpy`
- `frame_dummy` → `register_tm_clones`
- `indata_cb` → `__wrap___aeabi_memcpy`
- `indata_cb` → `log_write`
- `indata_cb` → `processCommandBuzzer`
- `indata_cb` → `processCommandDoor`
- `indata_cb` → `processCommandVentilation`
- `inpub_cb` → `log_write`
- `inpub_cb` → `__wrap_snprintf`
- `inpub_cb` → `strcmp`
- `add_repeating_timer_ms` → `alarm_pool_get_default`
- `add_repeating_timer_ms` → `__wrap___aeabi_lmul`
- `add_repeating_timer_ms` → `alarm_pool_add_repeating_timer_us`
- `dns_check_callback` → `ip4addr_ntoa`
- `dns_check_callback` → `log_write`
- `dns_check_callback` → `mqtt_client_connect`
- `subscribeToCommandTopics` → `__wrap_snprintf`
- `subscribeToCommandTopics` → `mqtt_sub_unsub`
- `subscribeToCommandTopics` → `log_write`
- `mqtt_connection_callback` → `log_write`
- `mqtt_connection_callback` → `commandMqttInit`
- `mqtt_connection_callback` → `subscribeToCommandTopics`
- `__static_initialization_and_destruction_0()` → `I2C::I2C(i2c_inst*, unsigned int, unsigned int)`
- `main` → `stdio_init_all`
- `main` → `log_set_level`
- `main` → `gpio_init`
- `main` → `add_repeating_timer_ms`
- `main` → `log_write`
- `main` → `sleep_ms`
- `main` → `cyw43_arch_init`
- ... e mais 2815 arestas

## Notas
- Análise offline do ELF realizada com sucesso.
- O WCET estimado é baseado em contagem de ciclos de instrução (pior caso).

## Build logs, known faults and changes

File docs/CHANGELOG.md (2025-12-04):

# Changelog

Histórico de mudanças do projeto Rack Inteligente - EmbarcaTech TIC-27.

Formato baseado em [Keep a Changelog](https://keepachangelog.com/pt-BR/1.0.0/).

## [Unreleased]

### Added
- **Documentação de Referência API** (`docs/REFERENCE_API.md`): Documentação completa de todas as funções, macros e variáveis dos códigos Python e C/C++.
  - Documentação do dashboard PyQt5 (`app.py`)
  - Documentação dos serviços: `rackControlService.py`, `forecastService.py`, `sarimaFallbackService.py`, `toolCallingService.py`, `anomalyDetector.py`
  - Documentação do simulador MQTT (`mqtt_simulator.py`)
  - Documentação do firmware: `rack_inteligente.cpp`, headers, tasks
  - Documentação das bibliotecas: `log_vt100`, `buzzer_pwm_task`, `door_servo_task`
  - Referência de tópicos MQTT padronizados
  - Referência de variáveis de ambiente

---

## [0.1.0] - 2025-11-16

### Added
- Firmware inicial para Raspberry Pi Pico W com FreeRTOS
- Conexão Wi-Fi e cliente MQTT
- Tasks para leitura de sensores (temperatura, umidade, inclinação)
- Task de GPS simulado
- Task de controle de porta via servo motor PWM
- Task de buzzer PWM com padrões sonoros distintos
- Sistema de comandos MQTT com confirmação (ACK)
- Dashboard PyQt5 com interface moderna
- Serviço de controle de racks via MQTT (`RackControlService`)
- Serviço de previsão com IBM Granite TTM-R2 (`ForecastService`)
- Serviço de fallback SARIMA (`SarimaFallbackService`)
- Serviço de Tool Calling com LLM (`ToolCallingService`)
- Detector de anomalias por Z-score (`AnomalyDetector`)
- Simulador MQTT para testes
- Mapa interativo com Leaflet.js e OpenStreetMap
- Script de conversão Markdown para PDF (padrão e ABNT)

### Technical
- Arquitetura híbrida de previsão (Granite + SARIMA)
- Sistema de histerese (Schmitt Trigger) para limiares
- Comunicação MQTT bidirecional com ACK
- Gráficos de séries temporais com previsão 24h
- Saída graciosa para interrupções (Ctrl+C)

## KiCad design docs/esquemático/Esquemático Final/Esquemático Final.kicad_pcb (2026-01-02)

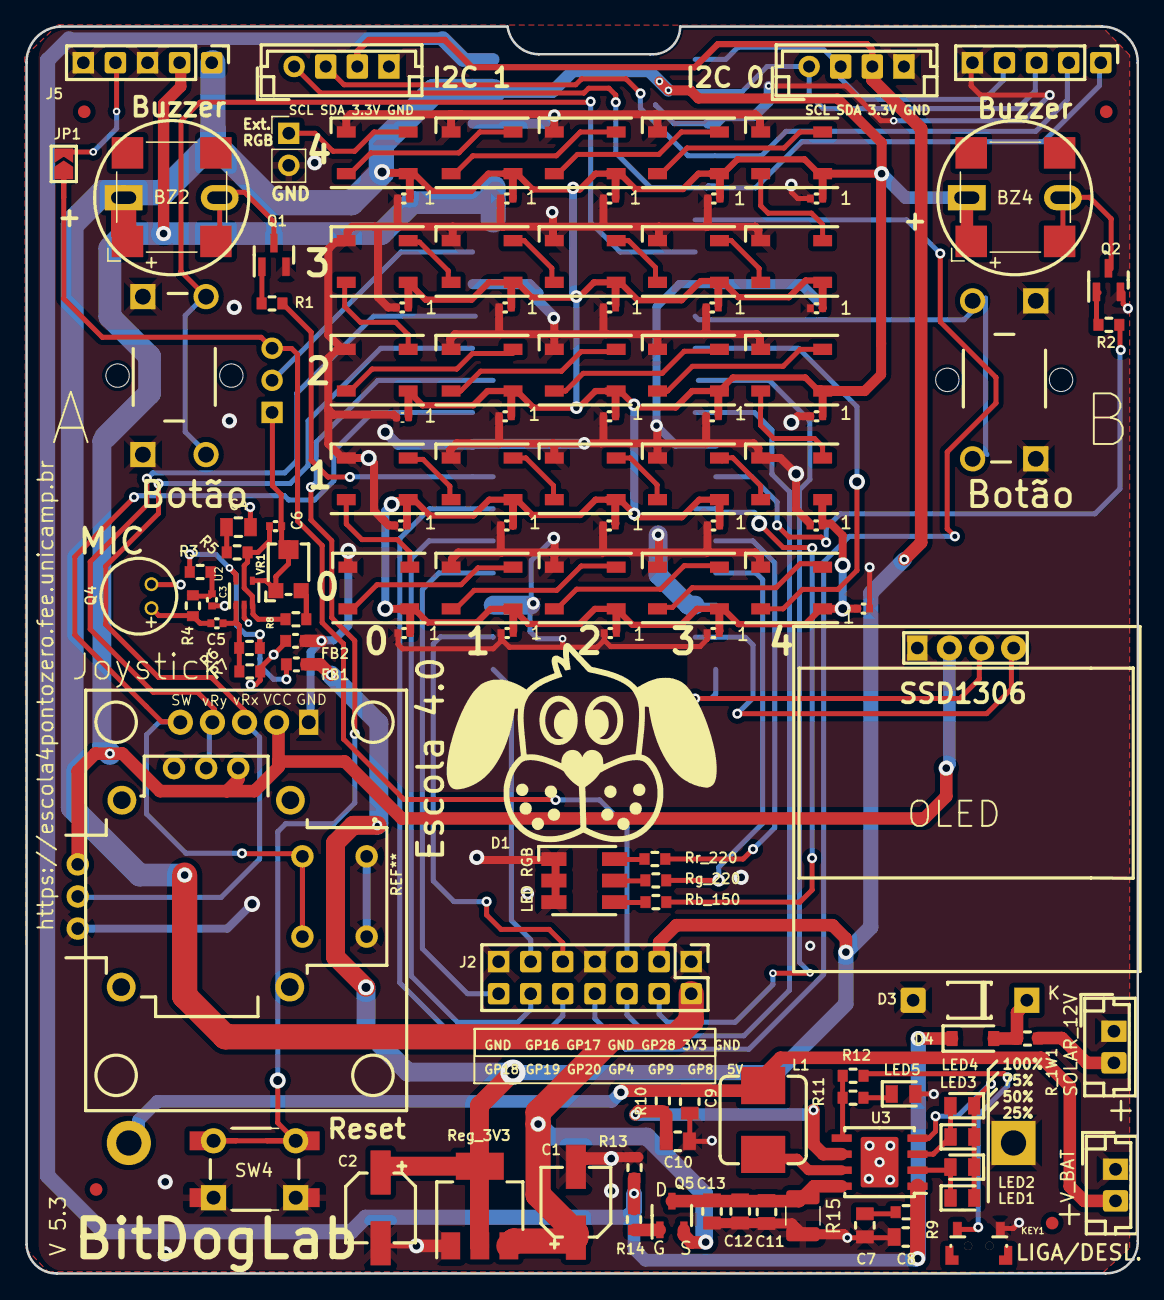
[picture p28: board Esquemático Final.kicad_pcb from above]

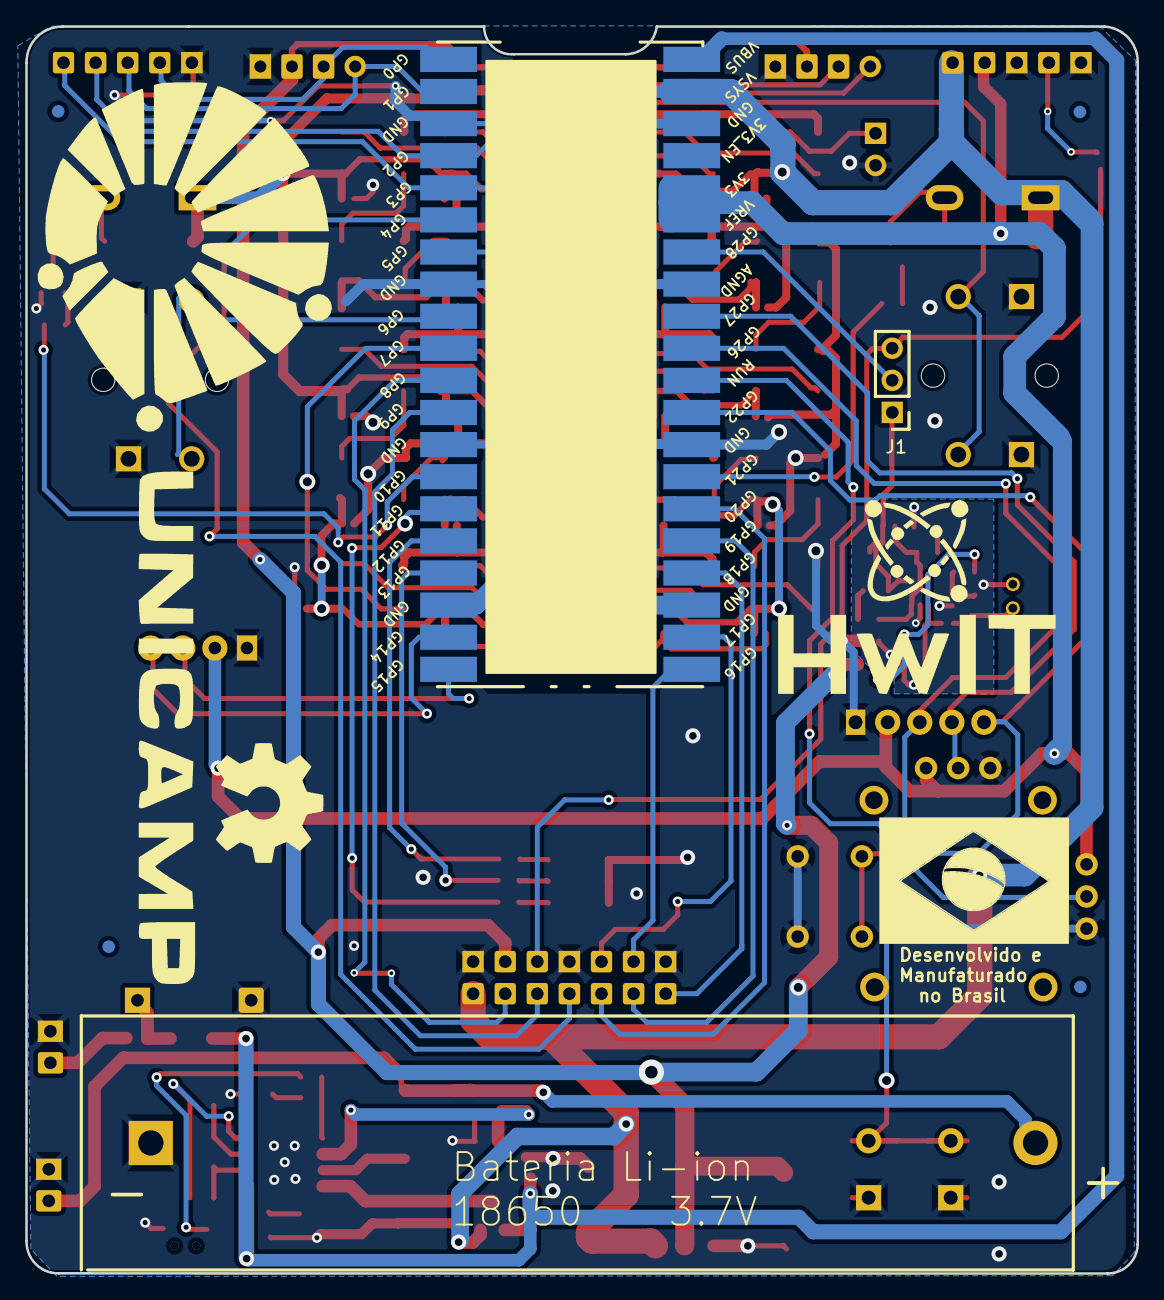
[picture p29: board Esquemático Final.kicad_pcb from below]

Board: 2 copper layers, 87.9 x 98.7 mm, 137 parts (11 on the bottom side), 89 nets.

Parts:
.: LOGO; Brasil_4
.#2: LOGO; 1Logo
.#3: LOGO; unicamp V2A
A1: SC0918; RPi_PicoW_SMD_TH
BT1: Battery_Cell; BatteryHolder_MPD_BH-18650-PC2
BZ1: Buzzer_A; Buzzer_12x9.5RM7.6
BZ2, BZ4: Buzzer_B_SMD; MagneticBuzzer_CUI_CMT-8504-100-SMT
BZ3: Buzzer_B; Buzzer_12x9.5RM7.6
C1, C2: C_Polarized_Small; CP_Elec_5x5.9
C3, C14, C15, C16, C17, C18, C19, C20, C21, C22, C23, C24, C25, C26, C27, C28, C29, C30, C31, C32, C33, C34, C35, C36, C37, C38: 0.1µF; C_0402_1005Metric
C4: 10uF; C_0805_2012Metric
C5: 0.01uF; C_0402_1005Metric
C6: 100pF; C_0402_1005Metric
C7, C8, C9, C10: 10u; R_0805_2012Metric
C11, C12, C13: 22u; R_0805_2012Metric
CARGA_SOLAR1: SOLAR_12V; JST_EH_B2B-EH-A_1x02_P2.50mm_Vertical
D1: LED_RGB_SMD; LED_RGB_5050-6
D2, D5, D6, D7, D8, D9, D10, D11, D12, D13, D14, D15, D16, D17, D18, D19, D20, D21, D22, D23, D24, D25, D26, D27, D28: WS2812B; LED_WS2812B_PLCC4_5.0x5.0mm_P3.2mm
D3: 1N5231; D_T-1_P5.08mm_Horizontal
D4: D_Schottky; D_SOD-123
FB1, FB2: FERRITE; L_0603_1608Metric
FID1, FID2, FID3, FID4, FID5, FID6, FID7, FID8: Fiducial; Fiducial_1mm_Mask2mm
G1: LOGO; logo bitDog 25mm
G3: LOGO
J1: Conn_01x03; PinHeader_1x03_P2.54mm_Vertical
J2: conector_idc; PinHeader_2x07_P2.54mm_Vertical
J3: Conn_01x02; PinHeader_1x02_P2.54mm_Vertical
J5, J12: Conn_01x05_Pin; PinHeader_1x05_P2.54mm_Vertical
J19: JOYSTICK; ky-023
J20, J21: Conn_01x04_Pin; JST_EH_B4B-EH-A_1x04_P2.50mm_Vertical
JP1: SolderJumper_2_Open; SolderJumper-2_P1.3mm_Open_TrianglePad1.0x1.5mm
KEY1: TS24CA; SW_SPST_CK_KMS2xxGP
L1: 1uH; L_Bourns_SRP7028A_7.3x6.6mm
LED1: 25%; LED_0805_2012Metric
LED2: 50%; LED_0805_2012Metric
LED3: 75%; LED_0805_2012Metric
LED4: 100%; LED_0805_2012Metric
LED5: PWR; LED_0805_2012Metric
OLED1: SSD1306; 128x64OLED
Q1, Q2: BC817; SOT-23
Q4: CMA-4544PF-W; Buzzer_12x9.5RM7.6
Q5: DMG2305UX-13; SOT-23-3
R1, R2: 330; R_0603_1608Metric
R3, R4, R5: 1K; R_0603_1608Metric
R6, R7: 1M; R_0603_1608Metric
R8: 22K; R_0603_1608Metric
R9, R10: 2R; R_0603_1608Metric
R11: 20R; R_0603_1608Metric
R12, R13: 10k; R_0603_1608Metric
R14: 0R; R_0603_1608Metric
R15: 100R; R_1210_3225Metric
R_1W1: 100; R_0603_1608Metric
Rb_150: 150; R_0603_1608Metric
Reg_3V3: 3.3v_smd; SOT-223
Rg_220: 220; R_0603_1608Metric
Rr_220: 220; R_0603_1608Metric
SW1: Reset; SW_PUSH_6mm
SW2: Botão; SW_PUSH_6mm_b
SW3: Button_B; SW_PUSH_6mm_b
SW4: Reset; SW_Push_1P1T_NO_6x6mm_H9.5mm
U2: MAX4466EXK+T; SOT-353_SC-70-5
U3: IP5306; SOP-8_5.28x5.23mm_P1.27mm
VR1: TC33X-2-104E (100K); Potentiometer_Bourns_TC33X_Vertical
V_BAT1: V_BAT; JST_EH_B2B-EH-A_1x02_P2.50mm_Vertical

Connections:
3.3_OUT: A1.35 (ADC_VREF), A1.36 (3V3_OUT), J5.2, J19.2, OLED1.2 (VCC)
+3.3V: C2.1, FB1.2, J2.3, J20.3, J21.3, Reg_3V3.2 (VO), Reg_3V3.4 (VO)
/GP0: A1.1 (GP0), J12.4, J21.2
/GP01: A1.2 (GP1), J12.3, J21.1
/GP02: A1.4 (GP2), J12.2, J20.2
/GP03: A1.5 (GP3), J12.1, J20.1
/GP04: A1.6 (GP4), J2.8
/GP08: A1.11 (GP8), J2.4
/GP09: A1.12 (GP9), J2.6
/GP10: A1.14 (GP10), R2.1
/GP11: A1.15 (GP11), Rb_150.2
/GP12: A1.16 (GP12), Rr_220.2
/GP13: A1.17 (GP13), Rg_220.2
/GP16: A1.21 (GP16), J2.11
/GP17: A1.22 (GP17), J2.9
/GP18: A1.24 (GP18), J2.14
/GP19: A1.25 (GP19), J2.12
/GP20: A1.26 (GP20), J2.10
/GP28: J1.3, J2.5, JP1.1 (A)
/GP28_uC: A1.34 (GP28), J1.2
/in: A1.10 (GP7), D2.4 (DIN)
/pino_07: A1.7 (GP5), SW2.1
/pino_09: A1.9 (GP6), SW3.1
/pino_19: A1.19 (GP14), OLED1.4 (SDA)
/pino_20: A1.20 (GP15), OLED1.3 (SCL)
/pino_27: A1.27 (GP21), R1.1
/pino_29: A1.29 (GP22), J19.5
/pino_30: A1.30 (RUN), SW1.1, SW4.1
/pino_31: A1.31 (GP26), J19.3
/pino_32: A1.32 (GP27), J19.4
AVCC: FB1.1, R3.2, R6.2, U2.5 (VCC)
GNDA: C3.2, C4.2, FB2.1, Q4.2 (+), R7.1, U2.2 (GND)
GNDREF: A1.3 (GND), A1.8 (GND), A1.13 (GND), A1.18 (GND), A1.23 (GND), A1.28 (GND), A1.33 (AGND), A1.38 (GND), BT1.2 (-), C1.2, C2.2, C7.2, C8.2, C9.2, C10.2, C11.2, C12.2, C13.2, C14.1, C15.1, C16.1, C17.1, C18.1, C19.1, C20.1, C21.1, C22.1, C23.1, C24.1, C25.1, C26.1, C27.1, C28.1, C29.1, C30.1, C31.1, C32.1, C33.1, C34.1, C35.1, C36.1, C37.1, C38.1, CARGA_SOLAR1.1, D1.1 (RK), D1.2 (GK), D1.3 (BK), D2.3 (VSS), D3.2 (A), D5.3 (VSS), D6.3 (VSS), D7.3 (VSS), D8.3 (VSS), D9.3 (VSS), D10.3 (VSS), D11.3 (VSS), D12.3 (VSS), D13.3 (VSS), D14.3 (VSS), D15.3 (VSS), D16.3 (VSS), D17.3 (VSS), D18.3 (VSS), D19.3 (VSS), D20.3 (VSS), D21.3 (VSS), D22.3 (VSS), D23.3 (VSS), D24.3 (VSS), D25.3 (VSS), D26.3 (VSS), D27.3 (VSS), D28.3 (VSS), FB2.2, J2.1, J2.7, J2.13, J3.2, J5.3, J5.5, J12.5, J19.1, J20.4, J21.4, KEY1.2, LED5.2 (K), OLED1.1 (GND), Q1.2 (E), Q2.2 (E), R13.2, R15.2, Reg_3V3.1 (ADJ), SW1.2, SW2.2, SW3.2, SW4.2, U3.9 (EP), V_BAT1.1
unnamed: BZ1.2 (+), BZ2.2 (+), Q1.3 (C)
unnamed: BZ3.2 (+), BZ4.2 (+), Q2.3 (C)
unnamed: C3.1, R3.1, R4.2
unnamed: C4.1, R5.1
unnamed: C5.1, Q4.1 (-), R4.1
unnamed: C5.2, R6.1, R7.2, U2.1 (IN+)
unnamed: C6.1, J1.1, U2.4 (OUT), VR1.1 (A), VR1.2 (S)
unnamed: C6.2, R5.2, R8.1, U2.3 (IN-)
unnamed: C7.1, R9.1
unnamed: CARGA_SOLAR1.2, R_1W1.2
unnamed: D1.4 (BA), Rb_150.1
unnamed: D1.5 (GA), Rg_220.1
unnamed: D1.6 (RA), Rr_220.1
unnamed: D2.2 (DOUT), D5.4 (DIN)
unnamed: D3.1 (K), D4.2 (A), R_1W1.1
unnamed: D5.2 (DOUT), D6.4 (DIN)
unnamed: D6.2 (DOUT), D7.4 (DIN)
unnamed: D7.2 (DOUT), D8.4 (DIN)
unnamed: D10.4 (DIN), D11.2 (DOUT)
unnamed: D9.4 (DIN), D10.2 (DOUT)
unnamed: D11.4 (DIN), D12.2 (DOUT)
unnamed: D12.4 (DIN), D13.2 (DOUT)
unnamed: D8.2 (DOUT), D13.4 (DIN)
unnamed: D9.2 (DOUT), D14.4 (DIN)
unnamed: D14.2 (DOUT), D15.4 (DIN)
unnamed: D15.2 (DOUT), D16.4 (DIN)
unnamed: D16.2 (DOUT), D17.4 (DIN)
unnamed: D17.2 (DOUT), D18.4 (DIN)
unnamed: D18.2 (DOUT), D25.4 (DIN)
unnamed: D19.4 (DIN), D21.2 (DOUT)
unnamed: D19.2 (DOUT), D20.4 (DIN)
unnamed: D20.2 (DOUT), D22.4 (DIN)
unnamed: D21.4 (DIN), D23.2 (DOUT)
unnamed: D22.2 (DOUT), D24.4 (DIN)
unnamed: D23.4 (DIN), D27.2 (DOUT)
unnamed: D24.2 (DOUT), D26.4 (DIN)
unnamed: D25.2 (DOUT), D27.4 (DIN)
unnamed: D26.2 (DOUT), D28.4 (DIN)
unnamed: D28.2 (DOUT), J3.1
unnamed: J5.4, JP1.2 (B)
unnamed: KEY1.1, R12.1
unnamed: LED1.1 (A), LED2.2 (K), U3.2 (LED1)
unnamed: LED1.2 (K), LED2.1 (A), LED3.2 (K), LED4.1 (A), U3.4 (LED3)
unnamed: LED3.1 (A), LED4.2 (K), U3.3 (LED2)
unnamed: LED5.1 (A), R11.1
unnamed: Q1.1 (B), R1.2
unnamed: Q2.1 (B), R2.2
unnamed: C11.1, C12.1, C13.1, Q5.3 (D), R15.1, U3.8 (VOUT)
unnamed: Q5.1 (G), R14.2
unnamed: C10.1, R10.1, U3.6 (BAT)
unnamed: R11.2, R12.2, U3.5 (KEY)
unnamed: L1.1, U3.7 (SW)
unnamed: R8.2, VR1.3 (E)
VBUS: A1.40 (VBUS), C8.1, D4.1 (K), R9.2, R13.1, R14.1, U3.1 (VIN)
VSYS: A1.39 (VSYS), BZ1.1 (-), BZ2.1 (-), BZ3.1 (-), BZ4.1 (-), C1.1, C14.2, C15.2, C16.2, C17.2, C18.2, C19.2, C20.2, C21.2, C22.2, C23.2, C24.2, C25.2, C26.2, C27.2, C28.2, C29.2, C30.2, C31.2, C32.2, C33.2, C34.2, C35.2, C36.2, C37.2, C38.2, D2.1 (VDD), D5.1 (VDD), D6.1 (VDD), D7.1 (VDD), D8.1 (VDD), D9.1 (VDD), D10.1 (VDD), D11.1 (VDD), D12.1 (VDD), D13.1 (VDD), D14.1 (VDD), D15.1 (VDD), D16.1 (VDD), D17.1 (VDD), D18.1 (VDD), D19.1 (VDD), D20.1 (VDD), D21.1 (VDD), D22.1 (VDD), D23.1 (VDD), D24.1 (VDD), D25.1 (VDD), D26.1 (VDD), D27.1 (VDD), D28.1 (VDD), J2.2, J5.1, Q5.2 (S), Reg_3V3.3 (VI)
V_BAT +: BT1.1 (+), C9.1, L1.2, R10.2, V_BAT1.2

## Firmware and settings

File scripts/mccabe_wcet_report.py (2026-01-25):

#!/usr/bin/env python3
"""mccabe_wcet_report.py

Autor: Carlos Delfino / EmbarcaTech TIC-27 (script recriado com suporte a GUI)
Data: 2025-12-18 (revisado 2025-12-23)

Objetivo
- Analisar arquivos ELF para extrair complexidade ciclomática (McCabe) e estimativa de WCET.
- Quando --serial é informado, coletar métricas de RTOS emitidas via serial pelo firmware.
- Agregar estatísticas (mínimo, máximo, média) e gerar relatório em Markdown.
- Exibir as métricas em tempo real via interface Qt com grafo de chamadas interativo.

Modos de operação:
1. Modo OFFLINE (sem --serial): Analisa apenas o arquivo ELF
   - Complexidade ciclomática McCabe
   - Estimativa de WCET baseada em ciclos de instrução
   - Grafo de chamadas de funções
   - Não requer conexão serial

2. Modo ONLINE (com --serial): Coleta dados do firmware em tempo real
   - Métricas de heap, stack e CPU
   - WCET medido via probes
   - Trace de escalonamento de tasks

Dependências (ver requirements.txt na raiz)
- PySide6
- pyserial
- pyqtgraph
- networkx (opcional, para layout de grafos)

Execução (exemplos)
# Modo offline (apenas análise de ELF):
python scripts/mccabe_wcet_report.py --out-md docs.temp/analise.md --elf firmware/build/rack_inteligente.elf --mcu-code rp2040 --gui

# Modo online (com serial):
python scripts/mccabe_wcet_report.py --out-md docs.temp/analise.md --serial --port /dev/ttyACM0 --elf firmware/build/rack_inteligente.elf --mcu-code rp2040 --gui

Observações importantes
- No modo online, o script depende do firmware emitir linhas no formato KV (key=value):
  - [MonitorKV] heap_free, heap_min, stack_total, stack_free, stack_used, stack_usage_pct
  - [HwKV] clk_*_hz, rtos_tick_hz, etc.
  - [WcetKV] ts_us, name, dur_us, task, isr
  - [TraceKV] ts_us, ev=switch_in|switch_out, task, reason, wait_ticks
- As estatísticas de CPU por tarefa são obtidas do bloco "Run Time Stats (CPU)" quando habilitado.

Saída graciosa
- Ctrl+C e sinais de término fecham a porta serial e gravam o Markdown de saída.
"""

from __future__ import annotations

import argparse
import dataclasses
import datetime as _dt
import json
import logging
import math
import numpy as np
import os
import re
import signal
import subprocess
import sys
import threading
import time
from collections import defaultdict, deque
from typing import Any, Deque, Dict, List, Optional, Set, Tuple

# Serial é opcional (apenas para modo online)
try:
    import serial  # type: ignore
    _HAS_SERIAL = True
except ImportError:
    serial = None  # type: ignore
    _HAS_SERIAL = False

# Qt / gráficos - opcional para modo CLI offline
_HAS_QT = False
QtCore: Any = None
QtWidgets: Any = None
QtGui: Any = None
pg: Any = None

try:
    from PySide6 import QtCore, QtWidgets, QtGui  # type: ignore
    import pyqtgraph as pg  # type: ignore
    _HAS_QT = True
except ImportError:
    # Cria classes stub para permitir definição das classes Qt
    class _QtCoreStub:
        class QObject:
            pass
        class QThread:
            pass
        class Signal:
            def __init__(self, *args: Any) -> None:
                pass
        class Slot:
            def __init__(self, *args: Any) -> None:
                pass
            def __call__(self, fn: Any) -> Any:
                return fn
        class Qt:
            class PenStyle:
                DashLine = 0
            class MatchFlag:
                MatchExactly = 0
            class ConnectionType:
                QueuedConnection = 0
            class ItemDataRole:
                DisplayRole = 0
        class QTimer:
            pass

    class _QtWidgetsStub:
        class QMainWindow:
            pass
        class QWidget:
            pass
        class QApplication:
            pass
        class QTabWidget:
            pass
        class QVBoxLayout:
            pass
        class QHBoxLayout:
            pass
        class QLabel:
            pass
        class QListWidget:
            pass
        class QTableWidget:
            pass
        class QLineEdit:
            pass
        class QCheckBox:
            pass
        class QSpinBox:
            pass
        class QTableWidgetItem:
            pass
        class QAbstractItemView:
            class EditTrigger:
                NoEditTriggers = 0
            class SelectionBehavior:
                SelectRows = 0
        class QHeaderView:
            class ResizeMode:
                Stretch = 0
                ResizeToContents = 0

    class _PgStub:
        class PlotWidget:
            pass
        class GraphItem:
            pass
        class TextItem:
            pass
        class BarGraphItem:
            pass
        class InfiniteLine:
            pass
        class ViewBox:
            YAxis = 0
        @staticmethod
        def setConfigOptions(**kwargs: Any) -> None:
            pass
        @staticmethod
        def mkPen(*args: Any, **kwargs: Any) -> Any:
            return None
        @staticmethod
        def mkBrush(*args: Any, **kwargs: Any) -> Any:
            return None

    QtCore = _QtCoreStub()  # type: ignore
    QtWidgets = _QtWidgetsStub()  # type: ignore
    QtGui = None  # type: ignore
    pg = _PgStub()  # type: ignore

# networkx é opcional para layout de grafos
try:
    import networkx as nx
    _HAS_NETWORKX = True
except ImportError:
    nx = None  # type: ignore
    _HAS_NETWORKX = False


_KV_RE = re.compile(r"(?P<key>[a-zA-Z0-9_]+)=(?P<value>[^\s]+)")
_PREFIX_RE = re.compile(r"^\[(?P<prefix>[A-Za-z0-9_]+)\]\s*(?P<body>.*)$")
_PLAIN_PREFIX_RE = re.compile(r"^(?P<prefix>[A-Za-z0-9_]+)\s*(?P<body>.*)$")
_LOG_LEVEL_PREFIX_RE = re.compile(r"^\[[A-Z]{3,5}\s*\]\s*(?P<rest>.*)$")
_ANSI_ESCAPE_RE = re.compile(r"(?:\x1b)?\[[0-9;]*m")
_KNOWN_PREFIXES = {"MonitorKV", "HwKV", "WcetKV", "TraceKV", "WCET", "TRACE"}

_LOGGER = logging.getLogger("wcet_report")


_TRACE_REASON_LABEL_BY_CODE: Dict[int, str] = {
    0: "desconhecido",
    1: "preempção",
    2: "delay",
    3: "queue_recv",
    4: "queue_send",
    5: "notify",
    6: "eventgroup",
}


def _formatTraceReason(reasonCode: Optional[int], waitTicks: Optional[int]) -> str:
    label = _TRACE_REASON_LABEL_BY_CODE.get(int(reasonCode or 0), str(reasonCode))
    if waitTicks is not None and waitTicks > 0:
        return f"{label} (wait={waitTicks} ticks)"
    return label


@dataclasses.dataclass(frozen=True)
class CliArgs:
    outMd: str
    serialEnabled: bool
    port: Optional[str]
    baud: int
    elfPath: Optional[str]
    mcuCode: Optional[str]
    projectDir: Optional[str]
    board: Optional[str]
    gui: bool
    logFile: Optional[str]
    serialLogPath: Optional[str]
    appLogPath: Optional[str]
    logLevel: str
    debugSerial: bool
    debugOutLog: Optional[str]


@dataclasses.dataclass
class RunningStats:
    """Estatística incremental para min/max/média."""

    count: int = 0
    mean: float = 0.0
    m2: float = 0.0
    minValue: Optional[float] = None
    maxValue: Optional[float] = None

    def update(self, value: float) -> None:
        if not math.isfinite(value):
            return
        self.count += 1
        if self.minValue is None or value < self.minValue:
            self.minValue = value
        if self.maxValue is None or value > self.maxValue:
            self.maxValue = value
        delta = value - self.mean
        self.mean += delta / float(self.count)
        delta2 = value - self.mean
        self.m2 += delta * delta2

    def variance(self) -> Optional[float]:
        if self.count < 2:
            return None
        return self.m2 / float(self.count - 1)

    def stddev(self) -> Optional[float]:
        var = self.variance()
        if var is None:
            return None
        if var < 0.0:
            return 0.0
        return float(var ** 0.5)


@dataclasses.dataclass
class TimeSeries:
    """Série temporal com janela fixa (memória limitada)."""

    maxLen: int
    points: Deque[Tuple[float, float]] = dataclasses.field(default_factory=deque)
    _startTs: Optional[float] = None
    _version: int = dataclasses.field(default=0, init=False, repr=False)
    _cacheVersion: int = dataclasses.field(default=-1, init=False, repr=False)
    _cacheX: Optional[np.ndarray] = dataclasses.field(default=None, init=False, repr=False)
    _cacheY: Optional[np.ndarray] = dataclasses.field(default=None, init=False, repr=False)

    def append(self, ts: float, value: float) -> None:
        if not math.isfinite(ts) or not math.isfinite(value):
            return
        if self._startTs is None:
            self._startTs = ts
        relTs = ts - self._startTs
        self.points.append((relTs, value))
        while len(self.points) > self.maxLen:
            self.points.popleft()
        self._version += 1

    def toArrays(self) -> Tuple[List[float], List[float]]:
        xs: List[float] = []
        ys: List[float] = []
        for x, y in self.points:
            xs.append(x)
            ys.append(y)
        return xs, ys

    def toNumpyArrays(self) -> Tuple[np.ndarray, np.ndarray]:
        if (
            self._cacheVersion == self._version
            and self._cacheX is not None
            and self._cacheY is not None
        ):
            return self._cacheX, self._cacheY

        n = len(self.points)
        if n <= 0:
            xs = np.asarray([], dtype=float)
            ys = np.asarray([], dtype=float)
            self._cacheX = xs
            self._cacheY = ys
            self._cacheVersion = self._version
            return xs, ys

        xs = np.empty(n, dtype=float)
        ys = np.empty(n, dtype=float)
        for i, (x, y) in enumerate(self.points):
            xs[i] = x
            ys[i] = y

        self._cacheX = xs
        self._cacheY = ys
        self._cacheVersion = self._version
        return xs, ys

    def clear(self) -> None:
        self.points.clear()
        self._startTs = None
        self._version += 1
        self._cacheVersion = -1
        self._cacheX = None
        self._cacheY = None


@dataclasses.dataclass
class TaskMetrics:
    """Métricas agregadas por task."""

    stackTotalStats: RunningStats = dataclasses.field(default_factory=RunningStats)
    stackFreeStats: RunningStats = dataclasses.field(default_factory=RunningStats)
    stackUsedStats: RunningStats = dataclasses.field(default_factory=RunningStats)
    stackUsagePctStats: RunningStats = dataclasses.field(default_factory=RunningStats)

    cpuPctStats: RunningStats = dataclasses.field(default_factory=RunningStats)

    stackUsedSeries: TimeSeries = dataclasses.field(default_factory=lambda: TimeSeries(maxLen=600))
    cpuPctSeries: TimeSeries = dataclasses.field(default_factory=lambda: TimeSeries(maxLen=600))


@dataclasses.dataclass
class WcetKey:
    name: str
    task: str
    isr: int


@dataclasses.dataclass
class WcetMetrics:
    """Métricas de WCET coletadas em tempo real via serial."""
    durUsStats: RunningStats = dataclasses.field(default_factory=RunningStats)
    durUsSeries: TimeSeries = dataclasses.field(default_factory=lambda: TimeSeries(maxLen=1200))
    durUsSamples: Deque[float] = dataclasses.field(default_factory=lambda: deque(maxlen=5000))
    lastTsUs: Optional[int] = None

    def quantiles(self, ps: List[float]) -> Dict[float, Optional[float]]:
        if not self.durUsSamples:
            return {p: None for p in ps}
        try:
            arr = np.fromiter(self.durUsSamples, dtype=float, count=len(self.durUsSamples))
        except Exception:
            return {p: None for p in ps}

        out: Dict[float, Optional[float]] = {}
        try:
            qs = np.percentile(arr, ps)
            for p, q in zip(ps, qs):
                out[p] = float(q)
        except Exception:
            for p in ps:
                out[p] = None
        return out


@dataclasses.dataclass
class FunctionInfo:
    """Informações de uma função extraídas do ELF (análise offline)."""
    name: str
    address: int = 0
    size: int = 0
    instructionCount: int = 0
    decisionCount: int = 0  # Número de branches condicionais
    mccabe: int = 1  # Complexidade ciclomática (1 + decisionCount)
    estimatedCycles: int = 0  # Estimativa de ciclos (para WCET)
    estimatedTimeUs: float = 0.0  # Tempo estimado em microsegundos
    callees: List[str] = dataclasses.field(default_factory=list)  # Funções chamadas
    callers: List[str] = dataclasses.field(default_factory=list)  # Funções que chamam esta
    stackUsage: Optional[int] = None  # Uso de stack (se disponível via -fstack-usage)
    isTask: bool = False  # Se é uma task do RTOS
    taskName: Optional[str] = None


@dataclasses.dataclass
class CallGraphData:
    """Dados do grafo de chamadas extraído do ELF."""
    functions: Dict[str, FunctionInfo] = dataclasses.field(default_factory=dict)
    edges: List[Tuple[str, str]] = dataclasses.field(default_factory=list)
    maxDepth: int = 0
    rootFunctions: List[str] = dataclasses.field(default_factory=list)  # Funções sem callers
    taskFunctions: List[str] = dataclasses.field(default_factory=list)  # Tasks identificadas
    mcuClockHz: int = 125_000_000  # Clock do MCU para cálculo de tempo


# Tabela de ciclos por instrução (ARM Cortex-M0+/M33, simplificada)
# Valores médios/piores casos para estimativa de WCET
_ARM_INSTRUCTION_CYCLES: Dict[str, int] = {
    # Aritméticas simples (1 ciclo)
    "add": 1, "adds": 1, "adc": 1, "adcs": 1, "sub": 1, "subs": 1,
    "sbc": 1, "sbcs": 1, "rsb": 1, "rsbs": 1, "mul": 1, "muls": 1,
    "and": 1, "ands": 1, "orr": 1, "orrs": 1, "eor": 1, "eors": 1,
    "bic": 1, "bics": 1, "mvn": 1, "mvns": 1, "neg": 1, "negs": 1,
    "mov": 1, "movs": 1, "movw": 1, "movt": 1,
    # Shifts (1 ciclo)
    "lsl": 1, "lsls": 1, "lsr": 1, "lsrs": 1, "asr": 1, "asrs": 1,
    "ror": 1, "rors": 1, "rrx": 1,
    # Comparações (1 ciclo)
    "cmp": 1, "cmn": 1, "tst": 1, "teq": 1,
    # Load/Store (2 ciclos em média, pior caso com wait states)
    "ldr": 2, "ldrb": 2, "ldrh": 2, "ldrsb": 2, "ldrsh": 2,
    "str": 2, "strb": 2, "strh": 2,
    "ldm": 4, "stm": 4, "push": 3, "pop": 3,
    # Branches (2-4 ciclos, pior caso para pipeline flush)
    "b": 3, "bl": 4, "blx": 4, "bx": 3,
    "beq": 3, "bne": 3, "bcs": 3, "bcc": 3, "bhs": 3, "blo": 3,
    "bmi": 3, "bpl": 3, "bvs": 3, "bvc": 3, "bhi": 3, "bls": 3,
    "bge": 3, "blt": 3, "bgt": 3, "ble": 3,
    "cbz": 3, "cbnz": 3,
    # Divisão (em MCUs com suporte, 2-12 ciclos)
    "sdiv": 8, "udiv": 8,
    # NOP
    "nop": 1,
    # Default para instruções desconhecidas
    "_default": 2,
}

# Padrões de nomes de tasks FreeRTOS comuns
_TASK_NAME_PATTERNS = [
    re.compile(r"^.*[Tt]ask.*$"),
    re.compile(r"^vTask.*$"),
    re.compile(r"^xTask.*$"),
    re.compile(r"^prv.*Task$"),
    re.compile(r"^.*_task$"),
    re.compile(r"^.*TaskEntry$"),
]


@dataclasses.dataclass
class SystemMetrics:
    heapFreeStats: RunningStats = dataclasses.field(default_factory=RunningStats)
    heapMinStats: RunningStats = dataclasses.field(default_factory=RunningStats)

    heapFreeSeries: TimeSeries = dataclasses.field(default_factory=lambda: TimeSeries(maxLen=600))
    heapMinSeries: TimeSeries = dataclasses.field(default_factory=lambda: TimeSeries(maxLen=600))


@dataclasses.dataclass
class SchedulingState:
    """Mantém timeline simplificada (switch_in/out) por task."""

    # segmentos recentes (start_ts, end_ts) em segundos (epoch)
    segments: Deque[Tuple[float, float]] = dataclasses.field(default_factory=lambda: deque(maxlen=2000))


@dataclasses.dataclass
class TraceGlobalState:
    """Estado global do escalonamento.

    O trace do FreeRTOS representa uma linha do tempo única (uma task executando
    por vez). Então, ao invés de armazenar currentStart por task (que falha
    quando os logs chegam com perdas), mantemos a task atual e seu início.
    """

    currentTask: Optional[str] = None
    currentStartRelSec: Optional[float] = None
    startTargetSec: Optional[float] = None
    startHostSec: Optional[float] = None
    lastRelSec: Optional[float] = None
    timeBase: Optional[str] = None

    pendingSwitchOutTask: Optional[str] = None
    pendingSwitchOutReason: Optional[int] = None
    pendingSwitchOutWaitTicks: Optional[int] = None
    pendingSwitchOutRelSec: Optional[float] = None


@dataclasses.dataclass
class TraceEdgeInfo:
    count: int = 0
    lastReason: Optional[int] = None
    lastWaitTicks: Optional[int] = None
    lastRelSec: Optional[float] = None


class MetricsStore:
    """Armazena dados em memória e fornece agregações rápidas."""

    def __init__(self) -> None:
        self.system = SystemMetrics()
        self.tasks: Dict[str, TaskMetrics] = defaultdict(TaskMetrics)
        self.scheduling: Dict[str, SchedulingState] = defaultdict(SchedulingState)
        self.hwKv: Dict[str, str] = {}
        self.trace = TraceGlobalState()
        self.traceEdges: Dict[Tuple[str, str], TraceEdgeInfo] = defaultdict(TraceEdgeInfo)
        self.wcet: Dict[WcetKey, WcetMetrics] = defaultdict(WcetMetrics)
        self.rxTotalLines: int = 0
        self.rxCountsByPrefix: Dict[str, int] = defaultdict(int)
        # Dados de análise offline do ELF
        self.callGraph: Optional[CallGraphData] = None
        self.offlineAnalysisComplete: bool = False

    def listTasks(self) -> List[str]:
        names = list(self.tasks.keys())
        names.sort()
        return names

    def listWcetKeys(self) -> List[WcetKey]:
        keys = list(self.wcet.keys())
        keys.sort(key=lambda k: (k.name, k.task, k.isr))
        return keys


class FirmwareLineParser:
    """Parser das linhas da serial conforme os prefixes já emitidos pelo firmware."""

    def parseLine(self, line: str) -> Tuple[Optional[str], Dict[str, str]]:
        txt = _ANSI_ESCAPE_RE.sub("", line).strip()

        # Alguns ambientes/loggers prefixam timestamp/ruído antes do KV.
        # Heurística: corta a partir do primeiro '[' para tentar alinhar com "[MonitorKV] ...".
        lb = txt.find("[")
        if lb > 0:
            txt = txt[lb:]

        # Normaliza prefixos de logger do firmware (ex.: "[INFO ] [TraceKV] ...")
        lm = _LOG_LEVEL_PREFIX_RE.match(txt)
        if lm:
            txt = lm.group("rest").lstrip()

        lb2 = txt.find("[")
        if lb2 > 0:
            txt = txt[lb2:]

        m = _PREFIX_RE.match(txt)
        if not m:
            # Fallback: permite linhas sem colchetes, ex.: "MonitorKV key=val"
            pm = _PLAIN_PREFIX_RE.match(txt)
            if not pm:
                return None, {}
            prefix = pm.group("prefix")
            if prefix not in _KNOWN_PREFIXES:
                return None, {}
            body = pm.group("body")
        else:
            prefix = m.group("prefix")
            body = m.group("body")

        kv: Dict[str, str] = {}
        for km in _KV_RE.finditer(body):
            kv[km.group("key")] = km.group("value")

        # Special handling for WCET prefix
        if prefix == "WCET" and not kv:
            m = re.search(r'Task:\s*(\w+),\s*WCET:\s*(\d+)\s*us', body.strip())
            if m:
                kv = {'name': 'wcet', 'task': m.group(1), 'dur_us': m.group(2), 'isr': '0'}

        if prefix.upper() == "TRACE" and not kv:
            m = re.search(r"Task\s+switched:\s*(?P<frm>.+?)\s*->\s*(?P<to>.+)$", body.strip())
            if m:
                kv = {"from": m.group("frm").strip(), "to": m.group("to").strip()}
                prefix = "TRACE"

        return prefix, kv

    def normalizeLine(self, line: str) -> str:
        """Remove prefixos de log (ex.: [INFO ]) para facilitar debug/replay."""

        txt = _ANSI_ESCAPE_RE.sub("", line).strip()

        lb = txt.find("[")
        if lb > 0:
            txt = txt[lb:]
        lm = _LOG_LEVEL_PREFIX_RE.match(txt)
        if lm:
            txt = lm.group("rest").lstrip()

        lb2 = txt.find("[")
        if lb2 > 0:
            txt = txt[lb2:]

        return txt


_CPU_HEADER_RE = re.compile(r"=+\s*Run Time Stats \(CPU\)\s*=+", re.IGNORECASE)
_CPU_END_RE = re.compile(r"=+\s*End Run Time Stats\s*=+", re.IGNORECASE)


class CpuStatsBlockParser:
    """Parser do bloco de vTaskGetRunTimeStats.

    Exemplo típico de linhas (FreeRTOS):
    TaskName\t\tRunTimeCounter\t\tPercentage
    Idle\t\t12345\t\t50%

    O firmware imprime cada linha com LOG_INFO("%s", line).
    """

    def __init__(self) -> None:
        self._inBlock = False

    def feed(self, line: str) -> Optional[List[Tuple[str, float]]]:
        txt = _ANSI_ESCAPE_RE.sub("", line).strip()
        lb = txt.find("[")
        if lb > 0:
            txt = txt[lb:]
        lm = _LOG_LEVEL_PREFIX_RE.match(txt)
        if lm:
            txt = lm.group("rest").lstrip()
        lb2 = txt.find("[")
        if lb2 > 0:
            txt = txt[lb2:]
        if _CPU_HEADER_RE.search(txt):
            self._inBlock = True
            _LOGGER.debug("CPU stats block start")
            return None
        if _CPU_END_RE.search(txt):
            self._inBlock = False
            _LOGGER.debug("CPU stats block end")
            return None
        if not self._inBlock:
            return None

        # Ignora cabeçalho
        if txt.lower().startswith("task"):
            return None

        # Tenta extrair "<name> ... <pct>%"
        parts = re.split(r"\s+", txt)
        if len(parts) < 2:
            return None

        # Percentual normalmente é o último campo e pode vir como "12%" ou "<1%"
        last = parts[-1]
        if not last.endswith("%"):
            return None

        try:
            rawPct = last.rstrip("%")
            if rawPct.startswith("<"):
                # Ex.: "<1%" -> aproxima para metade do limite
                pct = float(rawPct.lstrip("<")) * 0.5
            else:
                pct = float(rawPct)
        except ValueError:
            return None

        taskName = parts[0]
        return [(taskName, pct)]
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

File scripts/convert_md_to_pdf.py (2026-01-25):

#!/usr/bin/env python3

from __future__ import annotations

import argparse
import html
import re
import signal
import struct
import sys
from datetime import datetime
from pathlib import Path
from typing import TYPE_CHECKING, Any, Iterable, Protocol, Sequence, Tuple

import yaml
from markdown import markdown

try:
    from weasyprint import HTML
    from weasyprint.document import DocumentMetadata
except ModuleNotFoundError as import_error:  # pragma: no cover - execução defensiva
    HTML = None  # type: ignore[assignment]
    DocumentMetadata = None  # type: ignore[assignment]
    WEASYPRINT_IMPORT_ERROR = import_error
else:
    WEASYPRINT_IMPORT_ERROR = None

if TYPE_CHECKING:  # pragma: no cover - anotação para mypy/pylance
    from weasyprint.document import DocumentMetadata as DocumentMetadataType
else:
    DocumentMetadataType = Any

PDF_STYLES = """
@page {
    margin: 2cm;
}

body {
    margin: 0;
    font-family: "Helvetica", "Arial", sans-serif;
    font-size: 12pt;
}

table {
    width: 100%;
    border-collapse: collapse;
    table-layout: fixed;
}

thead tr,
tbody tr {
    page-break-inside: avoid;
}

th,
td {
    border: 1px solid #000000;
    padding: 0.4rem;
    text-align: justify;
    vertical-align: top;
    word-break: break-word;
}

caption {
    caption-side: top;
    text-align: center;
    font-weight: bold;
    margin-bottom: 0.5rem;
}

img {
    max-width: 100%;
    height: auto;
}

.image-portrait {
    text-align: center;
    page-break-inside: avoid;
    break-inside: avoid;
}

.image-portrait img {
    /*
     * A4 (portrait) = 29,7cm de altura.
     * Margens de 2cm em cima + 2cm em baixo => 25,7cm úteis.
     * Usamos max-height em cm para evitar casos em que porcentagem/vh não é
     * resolvida como esperado e a imagem acaba sendo cortada no PDF.
     */
    max-height: 25.7cm;
    object-fit: contain;
}

@page image-landscape {
    size: A4 landscape;
    margin: 2cm;
}

.image-landscape-page {
    page: image-landscape;
    page-break-before: always;
    page-break-after: always;
    text-align: center;
    page-break-inside: avoid;
    break-inside: avoid;
    display: flex;
    align-items: center;
    justify-content: center;
}

.image-landscape-page img {
    /*
     * A4 (landscape) = 21cm de altura e 29,7cm de largura.
     * Margens de 2cm em cada lado => altura útil 17cm e largura útil 25,7cm.
     */
    max-width: 25.7cm;
    max-height: 17cm;
    object-fit: contain;
}
"""

SLIDE_PDF_STYLES = """
@page {
    size: 1280px 720px;
    margin: 0;
}

html, body {
    margin: 0;
    padding: 0;
    font-family: "Segoe UI", "Roboto", "Helvetica Neue", "Arial", sans-serif;
    font-size: 24pt;
    line-height: 1.4;
    background: linear-gradient(135deg, #1a1a2e 0%, #16213e 50%, #0f3460 100%);
    color: #ffffff;
}

.slide {
    width: 1280px;
    min-height: 720px;
    box-sizing: border-box;
    padding: 60px 80px;
    page-break-after: always;
    display: flex;
    flex-direction: column;
    justify-content: flex-start;
    position: relative;
}

.slide:last-child {
    page-break-after: avoid;
}

.slide-title {
    width: 1280px;
    height: 720px;
    box-sizing: border-box;
    padding: 0 80px;
    page-break-after: always;
    page-break-inside: avoid;
    display: flex;
    flex-direction: column;
    justify-content: center;
    align-items: center;
    text-align: center;
    background: linear-gradient(135deg, #0f3460 0%, #1a1a2e 50%, #16213e 100%);
}

.slide-title h1 {
    font-size: 56pt;
    font-weight: 700;
    margin: 0 0 30px 0;
    color: #e94560;
    text-shadow: 2px 2px 4px rgba(0, 0, 0, 0.3);
}

.slide-title .subtitle {
    font-size: 28pt;
    color: #a0d2db;
    margin-bottom: 40px;
}

.slide-title .authors {
    font-size: 22pt;
    color: #c4c4c4;
    margin-top: 20px;
}

.slide-title .date {
    font-size: 18pt;
    color: #888888;
    margin-top: 30px;
}

.slide h1 {
    font-size: 40pt;
    font-weight: 600;
    margin: 0 0 40px 0;
    color: #e94560;
    border-bottom: 3px solid #e94560;
    padding-bottom: 15px;
}

.slide h2 {
    font-size: 32pt;
    font-weight: 600;
    margin: 0 0 30px 0;
    color: #a0d2db;
}

.slide h3 {
    font-size: 28pt;
    font-weight: 500;
    margin: 0 0 20px 0;
    color: #a0d2db;
}

.slide p {
    font-size: 24pt;
    margin: 0 0 20px 0;
    text-align: left;
}

.slide ul, .slide ol {
    font-size: 22pt;
    margin: 0 0 20px 40px;
    padding: 0;
}

.slide li {
    margin-bottom: 15px;
    line-height: 1.5;
}

.slide li::marker {
    color: #e94560;
}

.slide code {
    font-family: "Fira Code", "Consolas", "Monaco", monospace;
    font-size: 18pt;
    background: rgba(0, 0, 0, 0.4);
    padding: 4px 10px;
    border-radius: 6px;
    color: #a0d2db;
}

.slide pre {
    background: rgba(0, 0, 0, 0.5);
    padding: 25px 30px;
    border-radius: 12px;
    overflow: hidden;
    margin: 20px 0;
    border-left: 4px solid #e94560;
}

.slide pre code {
    font-size: 16pt;
    background: transparent;
    padding: 0;
    line-height: 1.6;
}

.slide blockquote {
    border-left: 5px solid #e94560;
    margin: 20px 0;
    padding: 15px 30px;
    background: rgba(233, 69, 96, 0.1);
    border-radius: 0 12px 12px 0;
    font-style: italic;
    color: #c4c4c4;
}

.slide table {
    width: 100%;
    border-collapse: collapse;
    margin: 20px 0;
    font-size: 18pt;
    page-break-inside: auto;
}

.slide thead {
    display: table-header-group;
}

.slide tbody {
    display: table-row-group;
}

.slide tr {
    page-break-inside: avoid;
    page-break-after: auto;
}

.slide th {
    background: rgba(233, 69, 96, 0.3);
    color: #ffffff;
    padding: 15px 20px;
    text-align: left;
    border: 1px solid rgba(255, 255, 255, 0.2);
}

.slide td {
    padding: 12px 20px;
    border: 1px solid rgba(255, 255, 255, 0.1);
    background: rgba(0, 0, 0, 0.2);
}

.slide tr:nth-child(even) td {
    background: rgba(0, 0, 0, 0.3);
}

.slide img {
    max-width: 100%;
    max-height: 500px;
    border-radius: 12px;
    box-shadow: 0 10px 30px rgba(0, 0, 0, 0.3);
}

.slide strong {
    color: #e94560;
}

.slide em {
    color: #a0d2db;
}

.slide a {
    color: #a0d2db;
    text-decoration: none;
    border-bottom: 2px dotted #a0d2db;
}

.slide hr {
    border: none;
    height: 2px;
    background: linear-gradient(90deg, transparent 0%, #e94560 20%, #a0d2db 50%, #e94560 80%, transparent 100%);
    margin: 25px 0;
}

.slide-number {
    position: absolute;
    bottom: 20px;
    right: 40px;
    font-size: 14pt;
    color: rgba(255, 255, 255, 0.4);
}

.slide-footer {
    position: absolute;
    bottom: 20px;
    left: 40px;
    font-size: 12pt;
    color: rgba(255, 255, 255, 0.3);
}
"""

ABNT_PDF_STYLES = """
@page {
    size: A4;
    margin-top: 3cm;
    margin-right: 2cm;
    margin-bottom: 2cm;
    margin-left: 3cm;
}

body {
    margin: 0;
    font-family: "Times New Roman", serif;
    font-size: 12pt;
    line-height: 1.5;
    text-align: justify;
}
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

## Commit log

2025-12-03 Regras para o Windsurf.
2025-12-03 Scripts de apoio
2025-12-03 Requirements para o python
2025-12-03 API do Granite e o TTS Granite para uso local
2025-12-03 Ajuste no mapa e nos comandos com ack para o firmware via mqtt
2025-12-03 Mais parametros para o sistema
2025-12-03 Ajustado o repositório que estava com falhas nos submodulos.
2025-12-04 Ajustes na lib de teclado e menu
2025-12-04 Corrigido problema de abertura e fechamento da porta.
2025-12-04 Movido o dashboard para um repositorio próprio.
2025-12-18 Adicionado esquemático da bitdog lab e do projeto, ajustes no firmware para wcet.
2026-01-02 Organização dos aquivos de imagem
2026-01-02 Adicionado esquemático do projeto
    [0603 Chip SMD LED (1.6x0.8mm) - Copia.STEP, 0603 Chip SMD LED (1.6x0.8mm).STEP, 12mm Push Button with Cap.STEP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]

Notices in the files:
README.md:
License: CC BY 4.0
